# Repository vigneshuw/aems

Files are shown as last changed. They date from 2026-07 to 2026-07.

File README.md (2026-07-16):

# AEMS — Autonomous Energy Monitoring System

An open-source, low-cost, modular platform for high-resolution energy monitoring of manufacturing equipment. AEMS acquires three-phase voltage and current through a front end and a 24-bit, simultaneously sampling ADC, managed by a dual-core architecture that separates deterministic acquisition and on-board logging from host communication and control. A host, edge-gateway, and optional cloud software stack enable autonomous, long-duration acquisition independent of a continuously connected host, combining research-grade fidelity with industrial deployability for Industry 4.0 environments.

This repository accompanies the paper (preprint):

> **An Open-Source, Autonomous Platform for High-Resolution Energy Monitoring in Manufacturing**
> Vignesh Selvaraj, Aditya Nagaraj, Shengyuan Zhang, Sina Sadeghian, Sangkee Min

If you use this hardware, firmware, or software in your work, please see
[Citation](#citation) and [`CITATION.cff`](CITATION.cff).

---

## Why AEMS

Long-term, robust monitoring of machine energy consumption is difficult: commercial power
meters capable of capturing transient events are expensive, closed, and impractical to deploy
across an entire facility. AEMS was designed to make high-fidelity energy monitoring
**affordable, customizable, and reproducible**, so that small and medium-sized manufacturers
can instrument their equipment and improve data availability for Industry 4.0 analytics.

Design goals:

- **High-rate, simultaneous multi-channel acquisition** of voltage and current signals.
- **Autonomous operation** — capture and log on the board even when a host or network is unavailable, then stream or transfer data later.
- **Modular and open** — hardware, firmware, and host software are all open and independently reusable.
- **Deployable at scale** — many boards can share a network and be controlled from a single host or from an edge computer such as Raspberry Pi.

---

## System overview

AEMS is organized into three layers, each of which lives in this repository:

| Layer | Location | Role |
|---|---|---|
| **Hardware** | [`hardware/`](hardware/) | Custom AEMS v2 DAQ board — KiCad design, ADS131M08 analog front end, surge protection, impedance-controlled PCB. |
| **Firmware** | [`firmware/`](firmware/) | STM32H745 dual-core firmware. **CM4** owns deterministic acquisition + eMMC storage; **CM7** owns Ethernet/TCP + host command/control over OpenAMP. |
| **Host software** | [`firmware/BoardInterfaceLibrary/`](firmware/BoardInterfaceLibrary/) | Python `board_interface` library, examples, Raspberry Pi daemon (`aemsctl`), and an optional AWS IoT cloud agent. |

```
Machine mains ──▶ AEMS board (ADS131M08 front end)
                        │
                   STM32H745
              ┌─────────┴─────────┐
        CM4 (DAQ + eMMC)   CM7 (Ethernet/TCP)
                        │
                Host (PC / Raspberry Pi)
             board_interface  ·  aemsctl daemon
```

Data flows from the analog front end through the ADS131M08 acquisition path on CM4, is logged
to on-board eMMC and/or streamed over TCP to a host, and can optionally be forwarded to the
cloud for remote monitoring and transfer.

---

## Repository layout

```
aems/
├── hardware/                     KiCad project for the AEMS v2 board
│   ├── *.kicad_sch / *.kicad_pcb Schematics and PCB layout
│   ├── CustomLibs/               Project symbol/footprint libraries
│   ├── LTSpiceSimulation/        Analog front-end simulations (CT op-amp, etc.)
│   ├── DesignSummary/            Stackup, impedance control, interactive BOM (ibom.html)
│   ├── Manufacturing/            PCBWay fabrication outputs
│   └── FutureUpdates/            Planned revisions (e.g. front-end isolation)
│
└── firmware/                     STM32H745 dual-core firmware + host tooling
    ├── CM4/                      Cortex-M4: DAQ, ADS131M08, eMMC/FatFs, OpenAMP
    ├── CM7/                      Cortex-M7: Ethernet/TCP, FreeRTOS, OpenAMP master
    ├── Common/                   Shared cross-core headers/data structures
    ├── BoardInterfaceLibrary/    Python host library, CLI, Raspberry Pi daemon, cloud agent
    ├── docs/Software/            Firmware architecture documentation
    └── UnitTests/                Bench connectivity/test scripts
```

Detailed documentation already lives with each subtree:

- **Firmware architecture** — [`firmware/README.md`](firmware/README.md) and
  [`firmware/docs/Software/README.md`](firmware/docs/Software/README.md)
- **Host Python library** — [`firmware/BoardInterfaceLibrary/README.md`](firmware/BoardInterfaceLibrary/README.md)
- **Raspberry Pi server & cloud** —
  [`firmware/BoardInterfaceLibrary/docs/raspberry_pi_server.md`](firmware/BoardInterfaceLibrary/docs/raspberry_pi_server.md),
  [`firmware/BoardInterfaceLibrary/docs/cloud_autonomy.md`](firmware/BoardInterfaceLibrary/docs/cloud_autonomy.md)
- **Hardware** — [`hardware/README.md`](hardware/README.md)

---

## Hardware at a glance

The AEMS v2 board is built around:

- **ADS131M08** 8-channel, 24-bit simultaneous-sampling delta-sigma ADC as the analog front end.
- **STM32H745** dual-core (Cortex-M7 + Cortex-M4) microcontroller.
- **Isolated power rails** and impedance-controlled routing for Ethernet and USB.
- **MOV-based surge protection** on the measurement inputs.
- **On-board eMMC** storage for logging, plus Ethernet connectivity.

The current firmware and host workflows target a **6-channel acquisition mask (`0x3F`)** — three voltage and three current channels. See [`hardware/README.md`](hardware/README.md) for the board description, bill of materials, and manufacturing notes.

> **Note on voltage range:** the present hardware is validated for direct measurement at the
> board's rated input topology. Higher line-to-line service voltages (e.g. 480 V L-L) require updating the MOV-based surge protector or an external potential transformer, consistent with the modular design; see
> [`hardware/FutureUpdates/`](hardware/FutureUpdates/).

---

## Getting started

The fastest path depends on what you want to do.

**Bring up a board and capture data**

1. Read the system split in [`firmware/docs/Software/README.md`](firmware/docs/Software/README.md).
2. Build and flash the CM4/CM7 firmware from STM32CubeIDE ([`firmware/`](firmware/)).
3. Confirm connectivity with `firmware/UnitTests/tcptest.py` or the Python examples.
4. Use the [`board_interface`](firmware/BoardInterfaceLibrary/) library for repeatable host-side
   control, logging, and streaming.

**Reproduce or modify the hardware**

1. Open the KiCad project in [`hardware/`](hardware/).
2. Review the interactive BOM at `hardware/DesignSummary/ibom.html` and the stackup/impedance
   summaries.
3. Use the [`hardware/Manufacturing/`](hardware/Manufacturing/) outputs for fabrication.

**Deploy a permanent Raspberry Pi server**

See [`firmware/BoardInterfaceLibrary/docs/raspberry_pi_server.md`](firmware/BoardInterfaceLibrary/docs/raspberry_pi_server.md)
for the `aems-boardd` systemd daemon and `aemsctl` control command, and
[`cloud_autonomy.md`](firmware/BoardInterfaceLibrary/docs/cloud_autonomy.md) for optional AWS
IoT integration.

---

## Repository provenance

`hardware/` and `firmware/` are maintained as independent projects and integrated here via
`git subtree`. Each retains its own commit history and can be developed in isolation.

---

## Citation

If you use AEMS in academic work, please cite the paper and (optionally) the archived software
release. Machine-readable metadata is in [`CITATION.cff`](CITATION.cff).

```bibtex
@misc{selvaraj_aems_2026,
  title   = {An Open-Source, Autonomous Platform for High-Resolution Energy
             Monitoring in Manufacturing},
  author  = {Selvaraj, Vignesh and Nagaraj, Aditya and Zhang, Shengyuan and
             Sadeghian, Sina and Min, Sangkee},
  year    = {2026},
  note    = {Preprint. Department of Mechanical Engineering,
             University of Wisconsin-Madison}
  % arXiv id / journal / doi to be added
}
```

The software itself is archived on Zenodo. Please cite the concept DOI (resolves to the
latest release):

**DOI: [10.5281/zenodo.21383443](https://doi.org/10.5281/zenodo.21383443)**

```bibtex
@software{selvaraj_aems_software,
  author    = {Selvaraj, Vignesh and Nagaraj, Aditya and Zhang, Shengyuan and
               Sadeghian, Sina and Min, Sangkee},
  title     = {AEMS: Autonomous Energy Monitoring System},
  year      = {2026},
  publisher = {Zenodo},
  doi       = {10.5281/zenodo.21383443},
  url       = {https://github.com/vigneshuw/aems}
}
```

The version validated in the paper is v1.0.2 (DOI: [10.5281/zenodo.21383444](https://doi.org/10.5281/zenodo.21383444)).

---

## License

AEMS is released as open hardware and open-source software under a per-material split (full
texts in [`LICENSES/`](LICENSES/), following the [REUSE](https://reuse.software) convention):

| Material | License | Applies to |
|---|---|---|
| Hardware design files | [`CERN-OHL-P-2.0`](LICENSES/CERN-OHL-P-2.0.txt) | [`hardware/`](hardware/) — schematics, PCB, libraries, BOM, fabrication outputs |
| Firmware & host software | [`MIT`](LICENSES/MIT.txt) | original code in [`firmware/`](firmware/) and the Python `BoardInterfaceLibrary` |
| Documentation & figures | [`CC-BY-4.0`](LICENSES/CC-BY-4.0.txt) | READMEs, `docs/`, design summaries |

SPDX expression for the repository: `CERN-OHL-P-2.0 AND MIT AND CC-BY-4.0`. Vendor and
third-party components (ST HAL/CMSIS, FreeRTOS, OpenAMP, FatFs, BlueNRG-2, downloaded KiCad
libraries) retain their own licenses. See [`LICENSE`](LICENSE) for the full overview.

---

## Contact

**Vignesh Selvaraj** — `vselvaraj@wisc.edu`, `vignesh-selvaraj@outlook.com`

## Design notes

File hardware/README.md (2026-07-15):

# AEMS Hardware — Energy Monitoring System Board

KiCad design for the AEMS v2 data-acquisition board: a custom, multi-channel energy-monitoring
front end built around the **ADS131M08** ADC and the **STM32H745** dual-core MCU. This is the
hardware layer of the [Autonomous Energy Monitoring System](../README.md) and is designed to be
reproduced, modified, and manufactured by others.

The KiCad project root is `EnergyMonitoringSystem.kicad_pro`.

---

## Board overview

The board acquires multi-channel voltage and current signals at a high, simultaneous sampling
rate, digitizes them through the ADS131M08 analog front end, and hands the data to the STM32H745
for on-board logging and network streaming.

Key design features:

- **ADS131M08** — 8-channel, 24-bit, simultaneous-sampling delta-sigma ADC front end.
- **STM32H745** dual-core (Cortex-M7 + Cortex-M4) host MCU with eMMC and Ethernet.
- **Isolated power rails** feeding the analog front end and digital domains.
- **Impedance-controlled, multilayer PCB** (100 Ω differential / 50 Ω single-ended Ethernet,
  90 Ω USB) — see the impedance and stackup exports in [`DesignSummary/`](DesignSummary/).
- **MOV-based surge protection** on the measurement inputs.
- **Ethernet** and **on-board eMMC** for autonomous, network-independent logging.

The current firmware/host workflows use a **6-channel acquisition mask (`0x3F`)** — three voltage and three current channels.

> **Input voltage topology:** the present design is validated for its rated direct-measurement
> input topology. Measuring higher line-to-line service voltages (e.g. 480 V L-L) exceeds the
> on-board MOV continuous ratings and requires an updated **MOV surge protector (upto a certain voltage level)** or **external potential transformer**. This is
> consistent with the modular design intent and is tracked under
> [`FutureUpdates/`](FutureUpdates/).

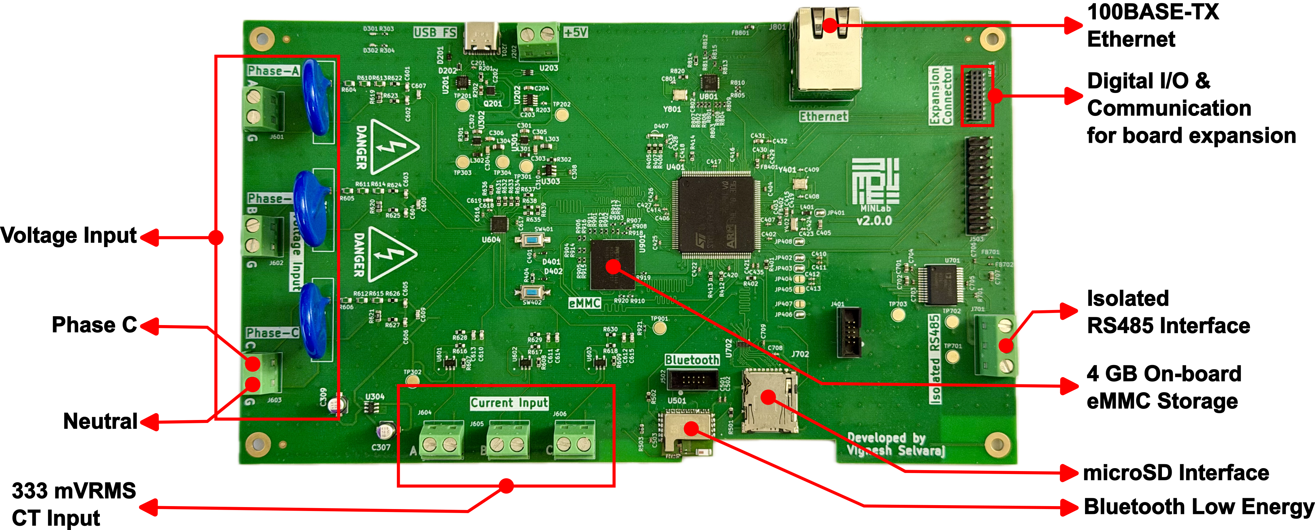
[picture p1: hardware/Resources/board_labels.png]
Overview of the AEMS hardware


---

## Board Power-Up

Temporarily, due to a design issue, the board needs to be powered on as shown in the figure below. This design issue will be fixed in the next hardware version. 

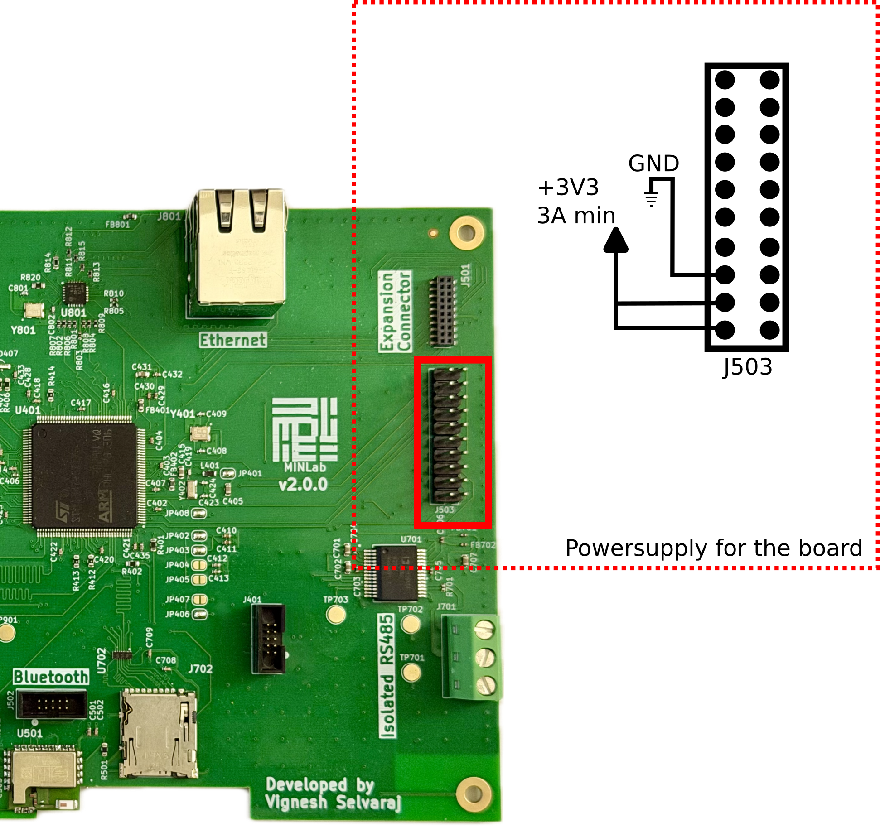
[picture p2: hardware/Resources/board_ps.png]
Board Power Supply


---

## Project structure

```
hardware/
├── EnergyMonitoringSystem.kicad_pro   KiCad project
├── EnergyMonitoringSystem.kicad_sch   Root schematic
├── EnergyMonitoringSystem.kicad_pcb   PCB layout
├── *.kicad_sch                        Hierarchical sheets (see below)
├── CustomLibs/                        Project symbol/footprint libraries
│   ├── EMS.kicad_sym                  Custom symbols
│   ├── EMS.pretty/                    Custom footprints
│   └── Downloaded/                    Third-party part libs (ADS131M08, MOV, op-amps, …)
├── LTSpiceSimulation/                 Analog front-end simulations (CT op-amp, rough studies)
├── Datasheets/                        Component reference material
├── ApplicationNotes/                  ST H7 hardware development notes
├── DesignSummary/                     Stackup, impedance control, interactive BOM
├── Manufacturing/PCBWay/              Fabrication + assembly outputs (Gerbers, drill, BOM, CPL)
└── FutureUpdates/Planned/             Planned revisions (front-end isolation, etc.)
```

### Schematic sheets

The design is hierarchical. The main functional sheets are:

| Sheet | Function |
|---|---|
| `adc` | ADS131M08 analog front end and signal conditioning |
| `uC` / `uCMain` | STM32H745 microcontroller and support |
| `ethernet` | Ethernet PHY (LAN8742) and magnetics |
| `poe` | Ethernet input (No PoE setup currently) |
| `vr` | Voltage regulation / power rails |
| `emmc` | eMMC storage |
| `sd_card` | SD card interface |
| `usb` | USB interface |
| `bm` | Bluetooth (BlueNRG) module |

---

## Bill of materials

- **Interactive BOM:** open [`DesignSummary/ibom.html`](DesignSummary/ibom.html) in a browser
  for a searchable, click-to-highlight BOM with board placement.
- **Fabrication BOM / placement:**
  [`Manufacturing/PCBWay/EnergyMonitoringSystem.kicad_pcb/PCBWay_bom.csv`](Manufacturing/PCBWay/EnergyMonitoringSystem.kicad_pcb/PCBWay_bom.csv)
  and `PCBWay_positions.csv` (component placement / CPL).

---

## Manufacturing

Ready-to-fabricate outputs (generated for PCBWay) are in
[`Manufacturing/PCBWay/`](Manufacturing/PCBWay/) or you generated your own from the KiCAD project:

- Gerbers (`F_Cu`, `B_Cu`, `In1..In6_Cu`, mask, paste, silkscreen, edge cuts)
- Drill files (`PTH`, `NPTH`)
- `PCBWay_bom.csv` (BOM) and `PCBWay_positions.csv` (pick-and-place)
- `PCBWay_netlist.ipc` (IPC-356 netlist)
- `DesignRequirements.pdf` and `Jump-SolderBridges.png` (assembly notes)

Stackup and impedance targets are documented in [`DesignSummary/`](DesignSummary/)
(`CurrentStackup.png`, `PCBWay Stackup.png`, and the `ImpedanceControl *.png` exports).

To regenerate outputs, open `EnergyMonitoringSystem.kicad_pcb` in KiCad and re-plot Gerbers/drill
and re-export the BOM/placement.

---

## Requirements

- **KiCad 7** or newer to open the project.
- Custom and downloaded libraries under [`CustomLibs/`](CustomLibs/) are referenced via the
  project-local `sym-lib-table` / `fp-lib-table`, so the project should open self-contained.

---

## Future updates

Planned hardware revisions are tracked in [`FutureUpdates/Planned/`](FutureUpdates/Planned/),
including improved analog front-end **isolation** and higher line-to-line voltages.

---

## License

Hardware licensing is being finalized as part of the open-hardware release; see the
[top-level LICENSE](../LICENSE). Please contact the authors before redistributing the design
files until the final license is committed.

For system context, firmware, and host software, see the [top-level README](../README.md).

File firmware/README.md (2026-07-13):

# AEMSv02-Firmware

Firmware and host-side tooling for the AEMS v2 board.

This repository contains:
- embedded firmware for the STM32H745 dual-core target
- CM4 DAQ, ADC, and eMMC ownership code
- CM7 Ethernet/TCP, OpenAMP, and host command handling code
- a Python board interface library for single-board and multi-board control
- software documentation for the firmware architecture

## What this repo is trying to do

At a high level, the board measures analog electrical signals, converts them through the ADS131M08 acquisition path, and then makes that data available in two main ways:

- log DAQ data to eMMC on the board
- stream DAQ or file data back to a host over TCP

The repository is structured around the hardware split of the STM32H745:

- `CM4` owns deterministic acquisition and storage work
- `CM7` owns network communication and command/control

That split is intentional. It keeps time-sensitive data capture close to the ADC/eMMC side, while the network-facing logic remains isolated on the Ethernet-enabled core.

## System overview

```mermaid
flowchart LR
    Host[Host PC / Raspberry Pi\nPython library or test tools]
    TCP[TCP server/client link]
    CM7[STM32H745 CM7\nEthernet + TCP + OpenAMP master]
    OA[OpenAMP / RPMsg]
    CM4[STM32H745 CM4\nDAQ engine + ADS131M08 + eMMC]
    ADC[ADS131M08 ADC]
    EMMC[eMMC / FatFs]

    Host <-->|commands, status, streams| TCP
    TCP <-->|network packets| CM7
    CM7 <-->|control + metadata| OA
    OA <-->|requests / replies| CM4
    ADC -->|sample frames| CM4
    CM4 -->|logged data| EMMC
    CM4 -->|stream/file data| OA
    OA --> CM7
    CM7 --> TCP
```

## High-level runtime model

### CM4 responsibilities

CM4 is the real-time acquisition and storage side.

It is responsible for:
- configuring and reading the ADS131M08
- running the DAQ state machine
- managing DAQ sample packing
- writing DAQ data to eMMC through FatFs
- exposing DAQ/file operations to CM7 through OpenAMP
- applying persisted channel offset calibration during DAQ startup

### CM7 responsibilities

CM7 is the communication and orchestration side.

It is responsible for:
- Ethernet and TCP handling
- receiving commands from the host
- translating host commands into OpenAMP operations
- returning status and acknowledgements over TCP
- serving file streams and DAQ streams back to the host

### Host responsibilities

The host side in this repo is the Python library in `BoardInterfaceLibrary`.

It is responsible for:
- acting as the TCP server that boards connect to
- handling single-board and multi-board sessions
- parsing board responses into stable dictionaries / dataclasses
- decoding DAQ stream and DAQ log binary formats
- converting raw ADC values into physical voltage/current values
- providing examples, CLI tooling, and simple GUIs

## Main workflows

### 1. Log DAQ data to eMMC

```mermaid
sequenceDiagram
    participant Host
    participant CM7
    participant CM4
    participant eMMC

    Host->>CM7: command 11 (start DAQ log)
    CM7->>CM4: OpenAMP DAQ start log
    CM4->>CM4: start ADC / DAQ state machine
    CM4->>eMMC: write packed DAQ blocks
    Host->>CM7: command 112 (stop and close)
    CM7->>CM4: OpenAMP DAQ stop/close
    CM4->>eMMC: flush + close file
    Host->>CM7: command 110 / 5
    CM7->>CM4: status / file size query
```

### 2. Stream DAQ data live

```mermaid
sequenceDiagram
    participant Host
    participant CM7
    participant CM4

    Host->>CM7: command 13 (start DAQ stream)
    CM7->>CM4: OpenAMP DAQ start stream
    CM4->>CM4: acquire samples
    CM4-->>CM7: stream blocks via shared memory / OpenAMP
    CM7-->>Host: TCP stream payload
    Host->>CM7: command 12 (stop)
    CM7->>CM4: OpenAMP DAQ stop
```

### 3. Read back a file from eMMC

```mermaid
sequenceDiagram
    participant Host
    participant CM7
    participant CM4
    participant eMMC

    Host->>CM7: command 8 (open/read stream)
    CM7->>CM4: OpenAMP file stream open/read
    CM4->>eMMC: read file chunks
    CM4-->>CM7: data blocks
    CM7-->>Host: TCP file stream
```

## Repository layout

Top-level directories:

- `CM4`
  - Cortex-M4 firmware project content
  - DAQ engine, ADS131M08 integration, eMMC/FatFs, OpenAMP remote service
- `CM7`
  - Cortex-M7 firmware project content
  - Ethernet/TCP handling, FreeRTOS tasks, OpenAMP master side
- `Common`
  - shared headers and cross-core data structures
- `BoardInterfaceLibrary`
  - Python package for controlling one or more boards from a host
- `UnitTests`
  - direct test scripts such as `tcptest.py`
- `docs`
  - software documentation for architecture and library internals
- `Drivers`
  - STM32 HAL and CMSIS driver code
- `Middlewares`
  - FatFs, OpenAMP, libmetal, and related middleware
- `datasheets`
  - hardware reference material used during firmware work

Key root files:

- `AEMSv02-Firmware.ioc`
  - STM32CubeMX project configuration
- `.project`, `.mxproject`, `.settings`
  - STM32CubeIDE project metadata

## Where to start, depending on what you are doing

### If you are working on embedded acquisition or storage

Start with:
- `CM4`
- `docs/Software/CM4/README.md`
- `docs/Software/CM4/Library/ads131m08.md`
- `docs/Software/CM4/Library/emmc_fs.md`

### If you are working on Ethernet, TCP, or host command flow

Start with:
- `CM7`
- `docs/Software/CM7/README.md`
- `docs/Software/CM7/Library/tcpclient.md`
- `docs/Software/CM7/Library/openamp_master.md`

Network identity is code-owned in `CM7/Core/Inc/aems_network_config.h`.
That header is the CubeMX-safe place to set the board static IP, server IP,
server port, and MAC derivation policy before flashing a board.

Current Ethernet policy:
- board IP is static and must be unique per board build
- MAC address is derived from the STM32 unique device ID using a locally administered prefix
- the board TCP client connects to the host/Raspberry Pi server at `192.168.0.20:10`
- TCP reconnects use rotating local source ports, per-board jitter, link-stability gating, TCP keepalive, and an app-level idle heartbeat
- command `99` reports the board IP, derived MAC, server IP/port, current local source port, connect-attempt count, and last connect/socket error

### If you are building host tools, automation, or multi-board workflows

Start with:
- `BoardInterfaceLibrary/README.md`
- `BoardInterfaceLibrary/examples/README.md`
- `BoardInterfaceLibrary/board_interface/session.py`
- `BoardInterfaceLibrary/board_interface/response_parser.py`

### If you need the overall firmware architecture first

Start with:
- `docs/Software/README.md`

## How people use this repo

There are usually three usage modes.

### Firmware development

Typical users:
- embedded developers working in STM32CubeIDE

They use this repo to:
- build and flash CM4/CM7 firmware
- modify DAQ behavior
- update command handling
- change hardware bring-up or storage behavior

### Board bring-up and bench validation

Typical users:
- firmware developers
- test engineers

They use:
- `UnitTests/tcptest.py`
- `BoardInterfaceLibrary/examples`

Common actions:
- verify heartbeat and OpenAMP connectivity
- start/stop DAQ logging
- stream files back from eMMC
- view live RMS values in a host GUI during DAQ streaming
- inspect DAQ status and throughput
- run offset calibration

## RGB LED Status Guide

The onboard RGB LED is driven by CM7 and gives a quick visual status of the board. The LED is useful when several boards are connected to a switch and the host is not yet running.

| LED | Board status | What to do |
|---|---|---|
| White solid | Booting | Firmware has started and initialization is in progress. |
| Blue slow blink | Ethernet / PHY init | LAN8742 PHY reset, Ethernet MAC/PHY bring-up, or no stable link yet. Check cable/switch if it stays here. |
| Blue solid | Ethernet link up, TCP not connected | Board has link but has not connected to the Python host server. Start the host server and check host IP/port. |
| Green solid | TCP connected / idle | Board is connected to the host and ready for commands. |
| Yellow blink | CM4 / OpenAMP not ready | CM7 is alive, but CM4/OpenAMP service is not healthy yet. Run command `99` for detail. |
| Red slow blink | eMMC error | Storage is unavailable or mount failed. Run command `99` and inspect eMMC mount diagnostics. |
| Purple slow blink | eMMC formatting | Blank eMMC was detected and filesystem creation is in progress. Wait for it to finish. |
| Cyan pulse | DAQ logging to eMMC | Command `11` DAQ capture is active and writing to eMMC. |
| Green fast blink | Live DAQ streaming | Command `13` live stream is active over TCP. |
| Cyan fast blink | File streaming | Command `8` file readback stream is active. |
| Yellow solid | Offset calibration | Command `98` offset calibration is running. |
| Orange blink | Recoverable warning | Nonfatal issue such as dropped samples, command failure, stream start failure, or retry condition. Query status. |
| Red solid | Fatal error | Firmware entered `Error_Handler()`. Reset/debug the board. |

Priority is error-first. For example, an eMMC error overrides the normal green connected state.

### Host-side application and automation development

Typical users:
- Python application developers
- lab automation developers
- Raspberry Pi / laptop control software developers

They use:
- `BoardInterfaceLibrary`

Common actions:
- control one or more boards simultaneously
- decode DAQ streams
- convert binary DAQ data to physical values
- build live monitoring tools on top of the Python session API
- build higher-level monitoring or acquisition applications

### Raspberry Pi permanent server deployment

Typical users:
- lab users who want a Pi to always listen for any plugged-in AEMS board
- automation systems that need shell-level control instead of foreground Python scripts

They use:
- `BoardInterfaceLibrary` installed with daemon support
- `aems-boardd` as a systemd service
- `aemsctl` as the shell control command
- optional `aems-cloud-agent` for AWS IoT Core command/shadow integration

Common actions:
- list active and historical boards
- start/stop DAQ streams on one board or all boards
- start/stop eMMC DAQ logs
- run local schedules for daily autonomous DAQ
- publish health/shadow JSON for cloud monitoring
- transfer capture bundles and manifests to local storage or S3
- query eMMC files and board status
- persist capture metadata under `/var/lib/aems-server`

Install on the Raspberry Pi from `BoardInterfaceLibrary`:

```bash
sudo bash ./deploy/install_raspberry_pi.sh
```

That installer creates the `aems` service user/group, installs the package into
`/opt/aems/venv`, installs `aems-boardd.service`, installs the optional
`aems-cloud-agent.service` unit file, and starts the board daemon. The cloud
agent is intentionally not enabled until AWS IoT credentials are configured.

For cloud support, install the optional dependencies into the same venv:

```bash
cd BoardInterfaceLibrary
sudo /opt/aems/venv/bin/pip install ".[cloud]"
```

Then configure `/etc/aems-server/cloud-agent.env`, place AWS IoT certificates
under `/etc/aems-server/certs`, and enable the cloud service:

```bash
sudo systemctl daemon-reload
sudo systemctl enable aems-cloud-agent
sudo systemctl start aems-cloud-agent
```

Use these checks after install:

```bash
aemsctl server status
aemsctl boards --active
sudo systemctl status aems-boardd --no-pager
sudo systemctl status aems-cloud-agent --no-pager
```

Cloud control uses JSON MQTT messages. `aems-cloud-agent` subscribes to
`aems/<thing-name>/commands/#`, forwards supported commands to the local daemon,
publishes responses to `aems/<thing-name>/responses`, and publishes health/shadow
state to `$aws/things/<thing-name>/shadow/update`. Example cloud command:

```json
{
  "command": "daq.stream.start",
  "params": {
    "board": "all",
    "file": "daq_cloud.bin",
    "format": "bin",
    "duration": 300,
    "sample_rate": 2000,
    "channel_mask": 63,
    "block_samples": 128
  }
}
```

## Current documentation entry points

- Firmware overview: `docs/Software/README.md`
- CM4 firmware docs: `docs/Software/CM4/README.md`
- CM7 firmware docs: `docs/Software/CM7/README.md`
- Python host library: `BoardInterfaceLibrary/README.md`
- Python examples: `BoardInterfaceLibrary/examples/README.md`
- Raspberry Pi server: `BoardInterfaceLibrary/docs/raspberry_pi_server.md`
- Raspberry Pi CLI: `BoardInterfaceLibrary/docs/aemsctl.md`
- Cloud/autonomous operation: `BoardInterfaceLibrary/docs/cloud_autonomy.md`

## Practical setup flow

For a new developer or user, the practical order is:

1. Understand the system split in `docs/Software/README.md`
2. Build/flash the firmware from STM32CubeIDE
3. Use `UnitTests/tcptest.py` or the Python examples to confirm board connectivity
4. Use `BoardInterfaceLibrary` for repeatable host-side control and streaming workflows

## Notes

- The current board/firmware assumptions in the Python tooling are built around a 6-channel mask of `0x3F` for the active acquisition workflows.
- CM4 is the authority for ADC capture, offset calibration, and eMMC writes.
- CM7 is the authority for TCP command handling and transport.

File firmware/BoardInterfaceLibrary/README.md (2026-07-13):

# Board Interface Library

This package provides a reusable Python interface for the AEMS board TCP protocol.

Primary APIs:
- `board_interface.BoardServer`
- `board_interface.BoardSession`
- `board_interface.StreamHandle`
- `board_interface.ResponseParser`
- `board_interface.convert_daq_bin_to_csv`

Examples are under `examples/`:
- `examples/commands_example.py`
- `examples/daq_log_example.py`
- `examples/stream_example.py`
- `examples/stream_on_command.py`
- `examples/stream_gui.py`
- `examples/multi_board_stream_example.py`
- `examples/multi_board_daq_log_example.py`
- `examples/README.md`

Raspberry Pi daemon/service docs:
- `docs/raspberry_pi_server.md`
- `docs/aemsctl.md`
- `docs/cloud_autonomy.md`

## Current capabilities

The library currently supports:
- single-board and multi-board TCP sessions keyed by board IP address
- DAQ logging control on the board eMMC
- remote file streaming and live DAQ streaming
- host-side parsing of ACKs/responses into stable dictionaries with `ResponseParser`
- command `99` parsing for network diagnostics, including board IP, derived MAC address, configured server IP/port, local TCP source port, connect-attempt count, and last connect/socket errors
- raw binary DAQ capture and offline conversion to parsed CSV
- live Tkinter-based RMS visualization for DAQ stream data through the example layer

For streamed or logged DAQ data, there are now two host-side output styles:
- raw `.bin`
  - preserves the exact raw bytes from the board
  - suitable for later post-processing
- parsed `.csv`
  - converts each DAQ frame into physical values
  - columns are `sample_index,ch0,ch1,ch2,ch3,ch4,ch5`
  - channels `0,1,2` are converted as voltage
  - channels `3,4,5` are converted as current

The same conversion path is exposed through:

```python
from board_interface import convert_daq_bin_to_csv
```

## DAQ binary layout: eMMC log vs live stream

The board does not emit the same binary layout for command `11` eMMC logging and command `13` live DAQ streaming. The library now handles these as two separate formats.

### Command 11: eMMC DAQ log file layout

The CM4 firmware packs only the selected channel values into the file written to eMMC.

For the current board build:
- channel mask is limited to `0x3F`
- that means channels `0..5` are logged
- each channel is written as one signed 32-bit little-endian integer
- there is no frame header, no response field, and no CRC in the file

So each logged sample in the `.bin` file is:
- `ch0` `int32_le`
- `ch1` `int32_le`
- `ch2` `int32_le`
- `ch3` `int32_le`
- `ch4` `int32_le`
- `ch5` `int32_le`

Total:
- `6 * 4 = 24` bytes per sample

This is the format used by:

```python
from board_interface import convert_daq_bin_to_csv
```

When `examples/stream_example.py` is used in file mode with:

```powershell
python .\examples\stream_example.py --mode file --file-output-format csv ...
```

the example now writes a metadata file next to the CSV that records:
- `decode_format: "command11_packed_log"`
- `sample_bytes: 24`
- `channel_mask: 0x3F`
- assumed channel order and channel types
- parsed command `8` stream summary

The multi-board file-stream example does the same thing per board, writing one metadata JSON file next to each converted CSV.

### Command 13: live DAQ stream layout

The live DAQ stream uses the full firmware frame layout:
- `response` as `uint16_le`
- `crc` as `uint16_le`
- `channel[0..7]` as eight signed 32-bit little-endian integers

Total:
- `36` bytes per stream frame

This is a different format from the eMMC log file. The library keeps these decode paths separate so command `11` files are not misinterpreted as command `13` stream frames.

## Installation Modes

### Normal laptop / desktop library install

Use this mode on Windows, macOS, Linux, or a Raspberry Pi when you want to write
your own Python scripts and directly import `board_interface`.

```powershell
pip install .
```

This installs:

- `board_interface` importable Python package
- `board-interface-cli` legacy interactive CLI
- `aemsctl`, `aems-boardd`, and `aems-cloud-agent` console entry points

Only `board_interface` and examples are normally used in this mode. The daemon
entry points are useful mainly on the Raspberry Pi permanent server.

### Raspberry Pi daemon install

Use this mode when the Pi should permanently listen on TCP port `10` and accept
any AEMS board that connects over Ethernet.

From the `BoardInterfaceLibrary` directory on the Pi:

```bash
sudo bash ./deploy/install_raspberry_pi.sh
```

The installer:

- creates the `aems` system user and group
- adds the invoking sudo user to group `aems` when possible
- creates `/etc/aems-server`
- creates `/etc/aems-server/certs`
- creates `/var/lib/aems-server/{captures,metadata,manifests,transfer_out}`
- installs this package into `/opt/aems/venv`
- installs `/etc/aems-server/config.toml`
- installs `aems-boardd.service`
- installs, but does not enable, `aems-cloud-agent.service`
- enables and restarts `aems-boardd`

Check daemon and CLI:

```bash
sudo systemctl status aems-boardd --no-pager
aemsctl server status
aemsctl boards --active
```

If `aemsctl` reports socket permission errors, log out and back in so the `aems`
group membership refreshes.

### Optional cloud dependencies

The base daemon does not require AWS packages. Install cloud extras only when
you need S3 transfer or AWS IoT Core integration:

Run this from the `BoardInterfaceLibrary` directory:

```bash
sudo /opt/aems/venv/bin/pip install ".[cloud]"
```

This installs:

- `boto3` for S3 upload jobs
- `awsiotsdk` for `aems-cloud-agent`

You can also install all extras into a local environment:

```bash
pip install ".[daemon,cloud]"
```

## Quick example

Stream a board file directly to raw binary:

```powershell
python .\examples\stream_example.py --mode file --file-output-format bin --board-ip 192.168.0.10 --remote-file daq0.bin --output captures\daq0.bin
```

Stream a board file and convert it directly to parsed CSV:

```powershell
python .\examples\stream_example.py --mode file --file-output-format csv --board-ip 192.168.0.10 --remote-file daq0.bin --output captures\daq0.csv
```

Stream live DAQ data to parsed CSV:

```powershell
python .\examples\stream_example.py --mode daq --daq-output-format csv --board-ip 192.168.0.10 --remote-file daq0.bin --duration 30 --output captures\daq0.csv
```

Open a live RMS GUI for the DAQ stream:

```powershell
python .\examples\stream_gui.py --mode daq --board-ip 192.168.0.10 --remote-file daq0.bin --sample-rate 2000 --channel-mask 0x3F --block-samples 128
```

Use `examples/README.md` for the full command reference and all example flows.

## Raspberry Pi permanent server

For a permanent Raspberry Pi server, install the daemon and use `aemsctl`.
The daemon owns TCP port `10`; boards connect to it automatically when they are
plugged into Ethernet.

Install on the Pi:

```bash
cd BoardInterfaceLibrary
sudo bash ./deploy/install_raspberry_pi.sh
```

Useful commands:

```bash
aemsctl server status
aemsctl boards --active
aemsctl board 192.168.0.10 openamp
aemsctl daq stream start --board all --file daq.bin --format bin --duration 30
aemsctl daq stream stop
```

The daemon stores board history and DAQ job metadata in SQLite under
`/var/lib/aems-server`. See `docs/raspberry_pi_server.md` and
`docs/aemsctl.md` for the full service and CLI reference.

Cloud/autonomous operation is documented in `docs/cloud_autonomy.md`. The daemon
now supports local schedules, health/shadow JSON, transfer manifests, local/S3
transfer jobs, and an optional AWS IoT bridge through `aems-cloud-agent`.

## Cloud Agent Summary

`aems-cloud-agent` is optional. It does not own board TCP connections; it talks
to the local daemon through `/run/aems-server/aems-boardd.sock`.

It does four things:

- subscribes to `aems/<thing-name>/commands/#`
- forwards supported cloud commands to `aems-boardd`
- publishes command responses to `aems/<thing-name>/responses`
- publishes the daemon shadow document to `$aws/things/<thing-name>/shadow/update`

Minimum cloud setup on the Pi:

```bash
sudo /opt/aems/venv/bin/pip install ".[cloud]"
sudo install -d -o aems -g aems -m 0750 /etc/aems-server/certs
sudo cp <device-cert.pem.crt> /etc/aems-server/certs/device.pem.crt
sudo cp <private-key.pem.key> /etc/aems-server/certs/private.pem.key
sudo cp <AmazonRootCA1.pem> /etc/aems-server/certs/AmazonRootCA1.pem
sudo chown -R aems:aems /etc/aems-server/certs
sudo chmod 0640 /etc/aems-server/certs/*
```

Create `/etc/aems-server/cloud-agent.env`:

```bash
AEMS_AWS_IOT_ENDPOINT=xxxxxxxxxxxxxx-ats.iot.us-east-1.amazonaws.com
AEMS_AWS_THING_NAME=aems-site-001-pi-001
AEMS_AWS_CERT=/etc/aems-server/certs/device.pem.crt
AEMS_AWS_KEY=/etc/aems-server/certs/private.pem.key
AEMS_AWS_CA=/etc/aems-server/certs/AmazonRootCA1.pem
AEMS_AWS_TOPIC_PREFIX=aems/aems-site-001-pi-001
```

Enable and inspect:

```bash
sudo systemctl daemon-reload
sudo systemctl enable aems-cloud-agent
sudo systemctl start aems-cloud-agent
sudo systemctl status aems-cloud-agent --no-pager
journalctl -u aems-cloud-agent -f
```

Cloud command payloads are JSON. Publish them to
`aems/<thing-name>/commands/<request-id>`:

```json
{
  "command": "daq.stream.start",
  "params": {
    "board": "all",
    "file": "daq_cloud.bin",
    "format": "bin",
    "duration": 300,
    "sample_rate": 2000,
    "channel_mask": 63,
    "block_samples": 128
  }
}
```

Useful cloud commands mirror the local daemon API:

- `health.get` / `health.shadow`
- `boards.list`, `jobs.list`, `transfers.list`
- `daq.stream.start` / `daq.stream.stop`
- `daq.log.start` / `daq.log.stop` / `daq.log.run`
- `transfer.start`
- `schedule.add` / `schedule.remove` / `schedule.enable`

Responses are published to `aems/<thing-name>/responses`. The device shadow is
published to `$aws/things/<thing-name>/shadow/update` every 30 seconds by
default. Use `docs/cloud_autonomy.md` for the full AWS setup and command
reference.

The AWS IoT policy must allow MQTT connect, subscribe/receive on the command
topic, publish on the response topic, and publish to the named shadow update
topic. S3 uploads require AWS credentials available to the `aems` user and
`s3:PutObject` permission on the configured bucket/prefix.

## Response parsing for end users

Use `board_interface.ResponseParser` to convert board responses and ACKs into stable dictionaries for application code.

Example:

```python
from board_interface import ResponseParser
parsed = ResponseParser.parse(response)
```

This parser is the intended place to update when board ACK/response formats change in the future.

## Current board limitation

The current board/firmware build is limited to a channel mask of `0x3F`.

That means:
- only channels 0 through 5 are currently supported by the examples and library workflows
- do not request a wider channel mask until the board firmware explicitly supports it

## TODO - Mandatory protocol fix

The current library contains a temporary host-side workaround to distinguish command `12` ACK traffic from command `13` DAQ stream payload on the same TCP connection.

This is not a reliable protocol boundary. It exists only as a temporary compatibility fix.

Mandatory long-term fix:
- update the firmware/protocol so DAQ stream traffic is explicitly framed or otherwise separated from control packets
- once that firmware change is made, the host library should remove the heuristic stream/control marker scan and parse packets deterministically

See `examples/README.md` for the detailed explanation and usage impact.

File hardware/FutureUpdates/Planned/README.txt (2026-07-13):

eMMC Memory
============

The plan is now to use the H7 chip that has a very high clock rate and can support the eMMC memory at a much higher clock rate (read and write speeds)

Advantages
----------

Something that we might potentially use for our case

1. Dual Core - Cortex M7 (~400MHz) and Cortex M4 (~200MHz)
	a. One for data collection / purely sampling the sensors (M0)
	b. One for external interface (Ethernet/Wi-Fi/RS 485)
2. Ethernet port is present
3. eMMC interface
4. USB present - Can be used as a mass storage as well
5. Pinouts for add on Wi-Fi board for scalability

1. PCB design notes for H7 Chip
	a. https://community.st.com/t5/stm32-mcus-products/stm32h7-with-emmc-and-usb-mass-storage-class-electronics/td-p/710280

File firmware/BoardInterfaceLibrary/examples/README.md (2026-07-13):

# Examples

This directory contains runnable examples for `BoardInterfaceLibrary`. The examples are intentionally small and direct, but they cover the main workflows you are likely to need:

- inspecting a board and exercising individual commands (Comment out items you don't need)
- starting a DAQ log to eMMC and stopping it cleanly
- streaming a file or DAQ data back to the host
- running simultaneous streams from multiple boards
- running simultaneous DAQ logs on multiple boards

The host machine runs these scripts as the TCP server. Boards connect into the host as TCP clients.

For a Raspberry Pi that should run continuously as the permanent board server,
use the daemon and CLI instead of these foreground examples:

- `../docs/raspberry_pi_server.md`
- `../docs/aemsctl.md`
- `../docs/cloud_autonomy.md`

## Response parsing for end users

Use `board_interface.ResponseParser` to convert board responses and ACKs into stable dictionaries for application code.

Example:

```python
from board_interface import ResponseParser
parsed = ResponseParser.parse(response)
```

This parser is the intended place to update when board ACK/response formats change in the future.

## Current board limitation

The current board/firmware build is limited to a channel mask of `0x3F`. All the binary to csv conversions implemented will only consider 6-channels, the codebase needs to be updated if going more than 6-channels.

That means:
- only channels 0 through 5 are currently supported by the examples and library workflows
- do not request a wider channel mask until the board firmware explicitly supports it

## TODO - Mandatory protocol fix

### Temporary workaround currently in use

The library now uses a temporary host-side heuristic, copied from the behavior proven in `UnitTests/tcptest.py`, to distinguish command `12` ACK traffic from command `13` DAQ stream payload on the same TCP socket.

What that means:
- while a DAQ stream is active, the host scans the incoming byte stream for something that looks like a fixed 128-byte control packet
- if it finds a plausible command `12` packet, it treats that region as control traffic instead of DAQ payload
- this is only a temporary compatibility fix so the example flow can stop a DAQ stream and continue collecting metrics

### Why this must be removed later

This is not a clean protocol boundary. It relies on packet-shape heuristics rather than explicit framing. That means it is workable for now, but it is not the correct long-term design.

### Required reliable fix - firmware/protocol update

A firmware update is required to make this reliable.

Mandatory fix:
- update the firmware/protocol so command `13` DAQ stream traffic is explicitly framed in chunks, or otherwise separated from fixed control/ACK packets
- after that, the host can parse command `12`, `10`, `110`, and other control packets deterministically during an active DAQ stream without any heuristic scanning

Recommended firmware-level solutions, in order of preference:
1. frame every DAQ stream chunk as a proper packet with command + length + payload
2. use a unified packet envelope for both stream and control messages
3. use separate logical or physical channels for stream data vs control traffic

Until that firmware update exists, the current heuristic should be treated as a temporary compatibility layer only.

## Directory contents

- `common.py`
  - shared helpers used by the single-board examples
- `commands_example.py`
  - runs the non-streaming commands against one board
- `daq_log_example.py`
  - starts DAQ logging on one board, waits, stops, then queries status and file size
- `stream_example.py`
  - streams either a remote file or a DAQ stream from one board
- `stream_on_command.py`
  - same core arguments as `stream_example.py`, but DAQ/file streaming starts when you press Enter
  - for DAQ mode, pressing Enter a second time sends command `12` to stop the stream
- `stream_gui.py`
  - starts a live DAQ stream and displays 0.25 second RMS values in a Tkinter GUI
  - shows channels 0 through 5 as Voltage-Ph1, Voltage-Ph2, Voltage-Ph3, Current-Ph1, Current-Ph2, Current-Ph3
- `multi_board_stream_example.py`
  - waits for multiple boards and starts simultaneous streams on all of them
- `multi_board_daq_log_example.py`
  - waits for multiple boards and starts simultaneous DAQ logs on all of them
- `boards.txt`
  - sample board IP file for the multi-board examples

## Requirements

- Python 3.10+
- the `board_interface` package available from this repo
- the host machine reachable by the boards over TCP
- boards configured to connect to the host on port `10` unless you override it

## General usage model

All examples follow the same pattern:

1. The script opens a TCP server on the host.
2. One or more boards connect to that server.
3. The script obtains a `BoardSession` for each board.
4. Commands are executed against each board session independently.

Single-board examples either:
- wait for the next board to connect, or
- wait for a specific board IP if `--board-ip` is given.

Multi-board examples:
- read a text file of IP addresses,
- wait for exactly those boards to connect,
- then start the requested operation on each board.

The default connection wait timeout used by the examples is 30 seconds unless you override `--timeout`.

## How to run the examples

Run from the `BoardInterfaceLibrary` directory:

```powershell
cd BoardInterfaceLibrary
```

### 1. Exercise the non-streaming commands

This example covers:
- heartbeat
- write config
- file counts
- file list
- file size
- DAQ status
- DAQ log status
- OpenAMP/network diagnostic heartbeat
- optional delete file
- delete all `.bin` / `.dat`

```powershell
python .\examples\commands_example.py
```

Target a specific board:

```powershell
python .\examples\commands_example.py --board-ip 192.168.0.10
```

Use a specific file for command 5:

```powershell
python .\examples\commands_example.py --board-ip 192.168.0.10 --read-file daq.bin
```

Run an explicit delete-file before the delete-all:

```powershell
python .\examples\commands_example.py --board-ip 192.168.0.10 --delete-file daq_old.bin
```

### 2. Run a DAQ log on one board

This example starts logging to eMMC, waits for the chosen duration, stops logging, then reads DAQ status and file size.

```powershell
python .\examples\daq_log_example.py --board-ip 192.168.0.10 --filename daq0.bin --duration 15
```

Common options:
- `--sample-rate`
- `--channel-mask`
- `--block-samples`

Example:

```powershell
python .\examples\daq_log_example.py --board-ip 192.168.0.10 --filename daq0.bin --duration 20 --sample-rate 6000 --channel-mask 0x3F --block-samples 128
```

### 3. Stream from one board

#### Interactive Enter-to-start / Enter-to-stop streaming

This example is intended for manual bench use.

- it accepts the same main stream arguments as `stream_example.py`
- it waits for Enter before starting the stream
- in `--mode daq`, it waits for Enter again before sending command `12`
- in `--mode file`, the second Enter concept does not apply because file streaming ends when the remote file transfer completes

DAQ stream with manual start/stop:

```powershell
python .\examples\stream_on_command.py --mode daq --daq-output-format csv --board-ip 192.168.0.10 --remote-file daq0.bin --output captures\daq0.csv
```

Raw file stream with manual start:

```powershell
python .\examples\stream_on_command.py --mode file --file-output-format bin --board-ip 192.168.0.10 --remote-file daq0.bin --output captures\daq0.bin
```

#### Live RMS GUI

This example starts a command `13` live DAQ stream and opens a Tkinter GUI. Incoming stream frames are decoded directly in memory; no `.csv` or `.bin` file is written.

The GUI displays RMS values over 0.25 second windows:

- `ch0` -> `Voltage-Ph1`
- `ch1` -> `Voltage-Ph2`
- `ch2` -> `Voltage-Ph3`
- `ch3` -> `Current-Ph1`
- `ch4` -> `Current-Ph2`
- `ch5` -> `Current-Ph3`

Stop the stream with the GUI's `Stop Stream` button.

```powershell
python .\examples\stream_gui.py --mode daq --board-ip 192.168.0.10 --remote-file daq0.bin --sample-rate 2000 --channel-mask 0x3F --block-samples 128
```

#### Stream a remote file to the host

For `--mode file`, there are now two output options:

- `--file-output-format bin`
  - writes the remote file exactly as raw bytes to a `.bin` file
- `--file-output-format csv`
  - treats the remote file as a command `11` eMMC DAQ log file
  - decodes it using the CM4 packed-log format, not the live stream format
  - columns are:
    - `sample_index`
    - `ch0`
    - `ch1`
    - `ch2`
    - `ch3`
    - `ch4`
    - `ch5`

Raw binary file read:

```powershell
python .\examples\stream_example.py --mode file --file-output-format bin --board-ip 192.168.0.10 --remote-file daq0.bin --output captures\daq0.bin
```

Convert streamed file directly to CSV:

```powershell
python .\examples\stream_example.py --mode file --file-output-format csv --board-ip 192.168.0.10 --remote-file daq0.bin --output captures\daq0.csv
```

For file-mode CSV output, the example also writes a metadata file next to the CSV, for example:
- `captures\daq0.csv.metadata.json`

That metadata records:
- `decode_format`
  - currently `command11_packed_log`
- `sample_bytes`
  - currently `24`
- `channel_mask`
  - currently `0x3F`
- `assumed_channel_order`
- `channel_types`
- `command_8_stream`
  - parsed file-stream summary from the library
- `frames_written`

If `--output` is omitted, the script writes to a default path that includes the board IP.

##### Important binary-layout detail for file mode

When command `11` logs DAQ data to eMMC, the CM4 firmware writes only the selected channel values into the file:

- current board limitation: channel mask is `0x3F`
- channels written: `ch0` through `ch5`
- storage type: signed 32-bit little-endian per channel
- no `response` field in the file
- no `crc` field in the file
- no per-sample header

So the current board writes:
- `24` bytes per logged sample
- sample layout:
  - `ch0 int32_le`
  - `ch1 int32_le`
  - `ch2 int32_le`
  - `ch3 int32_le`
  - `ch4 int32_le`
  - `ch5 int32_le`

This is why file-mode CSV conversion uses a different unpacker from live DAQ stream CSV conversion.

#### Stream live DAQ data to the host

For `--mode daq`, there are now two output options:

- `--daq-output-format csv`
  - writes a parsed CSV with converted physical values
  - decodes the command `13` live stream frame format
  - columns are:
    - `sample_index`
    - `ch0`
    - `ch1`
    - `ch2`
    - `ch3`
    - `ch4`
    - `ch5`
  - channel mapping is:
    - `ch0`, `ch1`, `ch2` -> converted voltage values
    - `ch3`, `ch4`, `ch5` -> converted current values
- `--daq-output-format bin`
  - writes the raw DAQ stream payload directly to a `.bin` file
  - this file contains only raw bytes; you can re-run the same conversion methods later if you want to post-process it offline

##### Important binary-layout detail for DAQ stream mode

Command `13` live streaming is not packed the same way as the eMMC log file.

The live DAQ stream uses the full firmware sample frame:
- `response uint16_le`
- `crc uint16_le`
- `channel[0..7]` as eight signed 32-bit little-endian integers

Total:
- `36` bytes per stream frame

So:
- command `11` file log decode path != command `13` live stream decode path
- the library now keeps those two formats separate on purpose

The example starts command 13 asynchronously, waits for `--duration`, sends command 12 with `stop_daq()`, waits for stream completion, then sends command 10 and saves metadata next to the output file.

The default DAQ stream duration is 30 seconds.

```powershell
python .\examples\stream_example.py --mode daq --daq-output-format csv --board-ip 192.168.0.10 --remote-file daq0.bin --duration 30 --output captures\daq0.csv
```

The example also writes a metadata file next to the CSV, for example:
- `captures\daq0.csv.metadata.json`

To dump the raw DAQ stream payload as a binary file instead:

```powershell
python .\examples\stream_example.py --mode daq --daq-output-format bin --board-ip 192.168.0.10 --remote-file daq0.bin --duration 30 --output captures\daq0.bin
```

That metadata file contains:
- `board_ip`
- `remote_file`
- `output_file`
- `duration_seconds`
- `command_13_ack`
  - fixed command 13 ACK if present, otherwise `null`
- `command_12_ack`
  - parsed stop ACK fields from command 12
  - includes `channel_mask_hex`
- `command_10_status`
  - parsed DAQ status returned by command 10 after the stream stops
  - includes `bytes_written_mib`
- `command_13_stream`
  - host-side DAQ stream summary
  - includes:
    - `bytes_received`
    - `bytes_received_mib`
    - `frames_received`
    - `elapsed_seconds`
    - `avg_frames_per_sec`
    - `avg_mib_per_sec`
    - `csv_path`

This metadata structure is intended to mirror the style of output you inspect in `tcptest.py` for commands 12, 13, and 10, but in machine-readable JSON form.

With DAQ stream settings:

```powershell
python .\examples\stream_example.py --mode daq --daq-output-format csv --board-ip 192.168.0.10 --remote-file daq0.bin --duration 15 --sample-rate 2000 --channel-mask 0x3F --block-samples 128
```

### 4. Stream from multiple boards simultaneously (Needs Testing)

Create an IP file such as `boards.txt`:

```text
192.168.0.10
192.168.0.11
192.168.0.12
```

A sample file is already included at:
- `examples/boards.txt`

#### Multi-board DAQ stream to CSV

```powershell
python .\examples\multi_board_stream_example.py --ip-file .\examples\boards.txt --mode daq --daq-output-format csv --remote-file daq.bin --output-dir captures
```

Each board writes to its own file, for example:
- `captures\192.168.0.10_daq.csv`
- `captures\192.168.0.11_daq.csv`

#### Multi-board DAQ stream to raw binary files

```powershell
python .\examples\multi_board_stream_example.py --ip-file .\examples\boards.txt --mode daq --daq-output-format bin --remote-file daq.bin --output-dir captures
```

Each board writes to its own file, for example:
- `captures\192.168.0.10_daq.bin`
- `captures\192.168.0.11_daq.bin`

#### Multi-board file stream to binary files

```powershell
python .\examples\multi_board_stream_example.py --ip-file .\examples\boards.txt --mode file --file-output-format bin --remote-file daq.bin --output-dir captures
```

Each board writes to its own file, for example:
- `captures\192.168.0.10_daq.bin`
- `captures\192.168.0.11_daq.bin`

#### Multi-board file stream converted to CSV

```powershell
python .\examples\multi_board_stream_example.py --ip-file .\examples\boards.txt --mode file --file-output-format csv --remote-file daq.bin --output-dir captures
```

Each board writes to its own converted CSV, for example:
- `captures\192.168.0.10_daq.csv`
- `captures\192.168.0.11_daq.csv`

For file-mode CSV conversion, each board also gets its own metadata file, for example:
- `captures\192.168.0.10_daq.csv.metadata.json`
- `captures\192.168.0.11_daq.csv.metadata.json`

These metadata files contain the same decode details as the single-board file-mode CSV example:
- `decode_format`
- `sample_bytes`
- `channel_mask`
- `assumed_channel_order`
- `channel_types`
- `command_8_stream`
- `frames_written`

### 5. Run DAQ logs on multiple boards simultaneously

This example starts logging on all listed boards first, waits for the requested duration, then stops each board and queries status and file size.

```powershell
python .\examples\multi_board_daq_log_example.py --ip-file .\examples\boards.txt --filename-prefix daq --duration 15
```

Generated remote filenames are unique per board, for example:
- `daq_192_168_0_10.bin`
- `daq_192_168_0_11.bin`

With a higher sample rate:

```powershell
python .\examples\multi_board_daq_log_example.py --ip-file .\examples\boards.txt --filename-prefix runA --duration 20 --sample-rate 6000 --channel-mask 0x3F --block-samples 128
```

## Command mapping reference

These examples exercise the current command set in the library:

- `0` - heartbeat
- `1` - write config
- `2` - `.dat` file count
- `3` - all file count
- `4` - file list with size
- `5` - file size for a specific filename
- `6` - delete all `.bin` / `.dat`
- `7` - delete a specific file
- `8` - file stream
- `9` - test stream
- `10` - DAQ status
- `11` - start DAQ log
- `12` - stop DAQ
- `13` - DAQ stream
- `97` - get current CM4 ADC offset calibration values
- `98` - run CM4 ADC offset calibration, save the offsets persistently, and return the new values
- `99` - OpenAMP heartbeat with eMMC, board IP/MAC, server, and TCP reconnect diagnostics
- `110` - DAQ log status
- `112` - stop/close DAQ log

## Notes on outputs

### Host-side outputs

For stream examples, host-side output names are board-scoped so simultaneous runs do not collide.

Examples:
- `captures\192.168.0.10_daq.csv`
- `captures\192.168.0.11_daq.csv`
- `captures\192.168.0.10_daq.bin`

### Board-side filenames

For DAQ logging examples, the filename refers to the file created on the board eMMC.

Single-board example:
- `--filename daq0.bin`

Multi-board example:
- generated from `--filename-prefix` and board IP so each board gets a unique remote file name

## Practical workflow

A typical workflow is:

1. Use `commands_example.py` to confirm the board is connected and responsive.
2. Use `daq_log_example.py` to create a DAQ file on the board.
3. Use `stream_example.py` with `--mode file` or `--mode daq` to pull data back to the host.
4. Use the multi-board examples once the single-board path is confirmed.

## Troubleshooting

### A script waits forever for a board

Check:
- the board is configured to connect to the host IP and port
- the host firewall allows inbound TCP on the selected port
- the IP in `--board-ip` or `boards.txt` matches the board client IP

### A board connects but the wrong board is used

For single-board examples, provide `--board-ip` explicitly.

For multi-board examples, only the IPs listed in the IP file are accepted as targets.

### Output files are empty or incomplete

Check:
- the remote filename exists on the board
- command 11 actually created the DAQ file before command 8/13 is used
- DAQ log stop/close completed successfully before streaming the file

### Multiple boards are expected but only some connect

The multi-board examples wait for every IP in the IP file. Remove unavailable boards from the file or bring them online before starting the script.

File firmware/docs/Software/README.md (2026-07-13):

# AEMS Firmware Software Documentation

## Purpose

This firmware runs the Adaptive Energy Monitoring System (AEMS) board built around an STM32H745 dual-core MCU. The board acquires multi-channel electrical measurements through an ADS131M08 ADC, stores captured data to eMMC, and exchanges commands and data with a host computer over Ethernet/TCP.

The design deliberately splits responsibility across both cores:

- **CM4** owns deterministic acquisition, buffering, and eMMC file operations.
- **CM7** owns networking, TCP command handling, host-facing streaming, and supervisory control.

That split is the core architectural decision in this codebase. The firmware is trying to achieve three things at the same time:

1. **capture data deterministically** from the analog front end
2. **persist data safely** to eMMC in a format that can be streamed or decoded later
3. **expose the board as a remotely controlled instrument** through a simple TCP protocol

## Current firmware status

The current codebase implements the following board-level capabilities:

- CM7 TCP client connection to a host Python server
- CM7 CubeMX-safe static network config in `CM7/Core/Inc/aems_network_config.h`
- CM7 UID-derived locally administered MAC address
- CM7 TCP reconnect hardening: PHY reset/retry, link-stability gating, rotating local source ports, reconnect jitter, TCP keepalive, and app-level idle heartbeat
- CM7 command parser and response framing
- CM7 file and DAQ streaming over TCP
- CM4 OpenAMP remote service for filesystem and DAQ control
- CM4 ADS131M08 acquisition pipeline using SPI + DMA + cooperative superloop
- CM4 eMMC filesystem wrapper using FatFs on SDMMC1/MMC
- CM4 eMMC first-mount/format recovery with command `99` diagnostics
- CM4 SDMMC1 ClockDiv boot policy: slower ClockDiv during mount/format, runtime ClockDiv after success
- DAQ logging to eMMC files
- DAQ live streaming from CM4 to CM7 via shared memory
- file count, file list, file size, file delete, and file stream operations
- persistent ADC offset calibration commands `97` / `98`

Known current constraints:

- the host tooling and most workflows currently assume **channel mask `0x3F`**
- command `11` eMMC DAQ log files and command `13` live DAQ streams use **different binary layouts**
- CM7/host-side DAQ stop during command `13` still relies on a temporary protocol heuristic and should be cleaned up by a future firmware framing update
- command `99` is the primary bring-up diagnostic; it now includes raw FatFs mount/format results plus board IP/MAC/server/TCP reconnect diagnostics

## Hardware and software interplay

The firmware is tightly coupled to the board hardware. The main hardware/software boundaries are:

| Hardware block | Firmware owner | Notes |
|---|---|---|
| ADS131M08 ADC | CM4 | Sample clocking, SPI4 DMA reads, DRDY interrupt handling, per-sample packing |
| eMMC on SDMMC1 | CM4 | FatFs mount/format, ClockDiv policy, file I/O, DAQ raw log writes |
| Ethernet PHY / LwIP | CM7 | Host connectivity, TCP link, command transport |
| Shared SRAM region | CM4 + CM7 | File and DAQ streaming handoff between cores |
| OpenAMP / RPMsg | CM4 + CM7 | Control plane between the two cores |
| HSEM boot synchronization | CM4 + CM7 | Dual-core startup coordination |
| RGB LED | CM7 | Basic board-visible status indication |

### System data flow

```plantuml
@startuml
skinparam monochrome true
skinparam shadowing false
actor Host
rectangle CM7 {
  component "TCP client +\ncommand controller" as TCP
  component "OpenAMP master" as OA7
}
rectangle CM4 {
  component "OpenAMP remote" as OA4
  component "DAQ engine" as DAQ
  component "eMMC / FatFs" as FS
}
component "ADS131M08" as ADC
component "Shared SRAM" as SHM

Host --> TCP : TCP commands / stream sink
TCP --> OA7 : translate host requests
OA7 --> OA4 : RPMsg command
OA4 --> DAQ : start/stop/status
OA4 --> FS : list/read/write/delete
ADC --> DAQ : DRDY + SPI DMA samples
DAQ --> FS : raw DAQ log writes
FS --> OA4 : file chunks
DAQ --> SHM : DAQ stream blocks
FS --> SHM : file stream blocks
SHM --> TCP : zero-copy / pointer-style send
TCP --> Host : fixed responses + streamed bytes
@enduml
```

## Dual-core role split

### CM4 summary

CM4 is the real-time data plane. It:

- initializes and mounts eMMC
- configures and services the ADS131M08
- runs the DAQ state machine
- aggregates acquired samples into write blocks
- writes DAQ data to eMMC
- provides filesystem and DAQ services to CM7 through OpenAMP

See: [CM4 documentation](CM4/README.md)

### CM7 summary

CM7 is the supervisory and transport plane. It:

- boots FreeRTOS and LwIP
- opens a TCP connection to the host
- receives host commands and maps them to board actions
- calls CM4 OpenAMP services
- streams file and DAQ data over TCP
- frames host-visible responses

See: [CM7 documentation](CM7/README.md)

## Source tree orientation

| Area | Purpose |
|---|---|
| `CM4/Core/Src` | CM4 boot, superloop, OpenAMP remote endpoint |
| `CM4/Library/ads131m08` | ADC driver, DAQ engine, DAQ state machine |
| `CM4/Library/emmc_fs` | FatFs wrapper and raw DAQ log file API |
| `CM7/Core/Src` | CM7 boot, FreeRTOS tasks, OpenAMP master |
| `CM7/Library/eth` | TCP client used by the host-facing command path |
| `CM7/Library/led` | RGB LED helper |
| `Common/Inc` | shared DAQ structures, HSEM IDs, shared-memory definitions |
| `BoardInterfaceLibrary` | Python host library, examples, Raspberry Pi daemon, and CLI |

## Documentation map

### Core-level documents

- [CM4 / Overview](CM4/README.md)
- [CM7 / Overview](CM7/README.md)

### Library-level documents

#### CM4
- [CM4 Library Index](CM4/Library/README.md)
- [CM4 ads131m08 and DAQ engine](CM4/Library/ads131m08.md)
- [CM4 eMMC filesystem wrapper](CM4/Library/emmc_fs.md)
- [CM4 OpenAMP remote service](CM4/Library/openamp_remote.md)

#### CM7
- [CM7 Library Index](CM7/Library/README.md)
- [CM7 TCP client library](CM7/Library/tcpclient.md)
- [CM7 LED helper library](CM7/Library/led.md)
- [CM7 OpenAMP master service](CM7/Library/openamp_master.md)

#### Host / Raspberry Pi
- [Python host library](../../BoardInterfaceLibrary/README.md)
- [Raspberry Pi board server](../../BoardInterfaceLibrary/docs/raspberry_pi_server.md)
- [aemsctl CLI](../../BoardInterfaceLibrary/docs/aemsctl.md)
- [Cloud/autonomous operation](../../BoardInterfaceLibrary/docs/cloud_autonomy.md)

## Boot and runtime overview

### Boot sequence

1. CM7 powers up first, configures clocks/cache/MPU, and releases CM4 through HSEM.
2. CM4 wakes, initializes SPI4, SDMMC1, DAQ context, sets SDMMC1 to mount ClockDiv `10`, and mounts/formats the eMMC filesystem.
3. CM4 brings up the OpenAMP remote endpoint.
4. CM7 starts FreeRTOS, LwIP, TCP client, and OpenAMP master.
5. The board is then ready to accept host commands.

After a successful eMMC mount or first-boot format, CM4 switches SDMMC1 back to runtime ClockDiv `8` and then loads persisted DAQ offset calibration from `ocal.cfg` when present.

### Command path overview

```plantuml
@startuml
skinparam monochrome true
skinparam shadowing false
actor Host
participant "CM7 TcpClient" as TCP
participant "CM7 ControllerTask" as CTRL
participant "CM7 OpenAmpFs" as OA7
participant "CM4 OpenAmpFs" as OA4
participant "CM4 DAQ / FS" as CM4

Host -> TCP : TCP payload
TCP -> CTRL : enqueue decoded command
CTRL -> OA7 : service request
OA7 -> OA4 : RPMsg request
OA4 -> CM4 : DAQ or filesystem operation
CM4 --> OA4 : result / data metadata
OA4 --> OA7 : RPMsg reply
CTRL -> TCP : fixed reply or start stream
TCP --> Host : response bytes
@enduml
```

## Data formats that matter

Two binary DAQ formats exist today:

### 1. eMMC log file format from command `11`

- selected channels only
- current host physical-value tooling assumes channels `0..5` (`channel_mask = 0x3F`)
- firmware can validate an 8-bit channel mask, but widening the mask changes the file stride and host decoder assumptions
- each channel stored as signed 32-bit little-endian
- **24 bytes per sample** for current board assumptions

### 2. live DAQ stream format from command `13`

- `response` (`uint16_le`)
- `crc` (`uint16_le`)
- `channel[0..7]` as eight signed 32-bit little-endian values
- **36 bytes per frame**

This distinction is important in both firmware and host tooling.

## Bring-up diagnostics

Command `99` returns the health snapshot used during board bring-up and eMMC troubleshooting.

Important storage fields:

| Field | Meaning |
|---|---|
| `remote_mount_status` | CM4 public `EmmcFs_MountOrFormat()` result; `0` means storage is usable |
| `emmc_mount_stage` | last mount lifecycle stage: link, first mount, mkfs, or post-format mount |
| `emmc_mount_fresult` | FatFs result from the first `f_mount()` |
| `emmc_mkfs_fresult` | FatFs result from `f_mkfs()` |
| `emmc_post_mount_fresult` | FatFs result from the mount after formatting |

A blank eMMC can validly report `remote_mount_status=0`, `emmc_mount_fresult=13`, `emmc_mkfs_fresult=0`, and `emmc_post_mount_fresult=0`. That means the first mount found no filesystem, firmware created one, and the post-format mount succeeded.

## RGB LED Board Status

CM7 owns the onboard RGB LED and updates it from `TelemetryTask`. The LED service is non-blocking: the telemetry task selects a board status and calls `LED_Service(&rgbLed)` every 25 ms. Blink and pulse effects are generated from `HAL_GetTick()` and do not block TCP, OpenAMP, or DAQ work.

The LED is intended as the first field diagnostic. An end user should be able to look at the board and know whether the issue is network, host connection, CM4/OpenAMP, eMMC, active acquisition, or a fatal fault.

### Status Colors

| Priority | LED | Meaning | Typical trigger |
|---:|---|---|---|
| 1 | Red solid | Fatal firmware error | `Error_Handler()` |
| 2 | Red slow blink | eMMC/storage error | CM4 mount status is nonzero after command `99` diagnostics are available |
| 3 | Yellow blink | CM4/OpenAMP not ready | OpenAMP init failed or latest heartbeat/probe showed CM4 service not healthy |
| 4 | Yellow solid | Offset calibration active | command `98` is running |
| 5 | Purple slow blink | eMMC formatting | blank eMMC was detected and filesystem creation is in progress |
| 6 | Cyan pulse | DAQ logging to eMMC | command `11` succeeded and logging is active |
| 7 | Green fast blink | Live DAQ streaming | command `13` stream is active |
| 8 | Cyan fast blink | File stream active | command `8` stream is active |
| 9 | Orange blink | Recoverable warning | command/stream failure, dropped samples reported by command `10`/`110`, or retry condition |
| 10 | Green solid | TCP connected and idle | board is connected to host and no higher-priority activity/error is active |
| 11 | Blue solid | Ethernet link up, TCP not connected | PHY/link is up but Python host server is not connected |
| 12 | Blue slow blink | Ethernet/PHY initialization or no link | PHY reset/link bring-up, cable/switch missing, or link not stable |
| 13 | White solid | Booting | LED initialized before runtime status is known |

### How to Interpret the LED

- **White solid** should be brief. If it stays white, CM7 likely did not reach the FreeRTOS telemetry loop.
- **Blue slow blink** points at physical Ethernet: cable, switch, PHY reset/init, or link negotiation.
- **Blue solid** means Ethernet is good but the host TCP server is not connected. Start the Python tool and verify the configured host IP is reachable.
- **Green solid** is the normal idle state after the board connects to the host.
- **Yellow blink** means CM7 is alive but cannot confirm CM4/OpenAMP health. Use command `99`.
- **Red slow blink** means eMMC is not usable. Use command `99` and check `remote_mount_status`, `emmc_mount_stage`, and FatFs `FRESULT` fields.
- **Purple slow blink** means the eMMC filesystem creation path is active. This can happen on a new blank eMMC.
- **Cyan pulse / green fast blink / cyan fast blink** identify active data movement: eMMC DAQ logging, live DAQ streaming, or file streaming.
- **Orange blink** is intentionally nonfatal. It tells the user to query command `10`, `110`, or `99` for detail.
- **Red solid** means fatal firmware error and requires reset/debug.

See also: [CM7 LED helper library](CM7/Library/led.md)

## Recommended reading order

1. read this page first
2. read [CM4 / Overview](CM4/README.md)
3. read [CM7 / Overview](CM7/README.md)
4. use the library pages for function-level interface details

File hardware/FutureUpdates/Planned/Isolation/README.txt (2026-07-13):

Safety
------

- Creating isolation to protect other devices connected to the board

DC-DC-Isolation
----------------

- Isolating the power supply to ADC from the USB Input
- https://www.analog.com/en/products/adum5000.html#part-details
- Videos -> https://www.youtube.com/watch?v=OM6CCaYSZ9A

SPI Isolation
--------------

- Isolating the SPI connection between the ADC and MCU
- Potentially we can remove the 1V2 REF IN to the ADC, as the ADC has its own reference voltage generator. But need to think about the Op-Amp used for the current input.
- https://www.analog.com/en/products/adum3151.html#part-details

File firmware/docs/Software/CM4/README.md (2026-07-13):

# CM4 Firmware

## Role

CM4 is the deterministic acquisition and storage core.

It runs without an RTOS and executes a cooperative superloop. It owns the peripherals that are most timing-sensitive or storage-sensitive:

- ADS131M08 acquisition path
- SPI4 DMA servicing for ADC reads
- SDMMC1 / eMMC access
- FatFs-backed file operations
- OpenAMP remote command handling for file and DAQ services

The key design rule is simple: **CM4 owns the data plane**.

## Runtime responsibilities

CM4 is responsible for:

- booting after CM7 releases it through HSEM
- initializing the ADC-facing SPI and the eMMC interface
- mounting the filesystem
- creating the filesystem on first boot when eMMC is blank
- recording eMMC mount/format diagnostics for command `99`
- creating the OpenAMP RPMsg service used by CM7
- running the DAQ state machine
- packaging and writing raw samples into eMMC log files
- exposing file operations and DAQ operations to CM7

## Main execution model

CM4 main loop in `CM4/Core/Src/main.c` is effectively:

```c
while (1)
{
    DAQ_StateMachine_Run();
    OpenAmpFs_RemotePoll();
}
```

That is the whole model:

- DAQ work is progressed cooperatively
- OpenAMP messages are polled cooperatively
- interrupt handlers only signal events and complete DMA-related handoffs

## Core startup

### File of interest
- `CM4/Core/Src/main.c`

### Sequence

1. wait for CM7 boot synchronization using HSEM
2. initialize HAL and CM4-owned peripherals
3. probe the ADC device ID using the master clock
4. initialize DAQ context and DAQ engine
5. set SDMMC1 to mount ClockDiv `10`
6. initialize and mount-or-format eMMC filesystem through `EmmcFs_*`
7. snapshot mount diagnostics for command `99`
8. if mount succeeded, switch SDMMC1 to runtime ClockDiv `8`
9. load persisted ADC offset calibration from `ocal.cfg` when present
10. initialize OpenAMP remote endpoint through `OpenAmpFs_RemoteInit()`
11. enter the superloop

## Interrupts and callback ownership

CM4 uses interrupts as signal sources, not as heavy processing contexts.

### Important callbacks in `main.c`

| Callback | Purpose |
|---|---|
| `HAL_GPIO_EXTI_Callback()` | detects ADS DRDY edge and signals DAQ |
| `HAL_SPI_TxRxCpltCallback()` | completes ADC DMA sample transfer and signals DAQ |
| `HAL_SPI_ErrorCallback()` | reports ADC DMA error to DAQ |

## DAQ state machine

### Files of interest
- `CM4/Library/ads131m08/statemachine.c`
- `CM4/Library/ads131m08/statemachine.h`
- `CM4/Library/ads131m08/daq_engine.c`
- `CM4/Library/ads131m08/daq_engine.h`

### States

| State | Meaning |
|---|---|
| `DAQ_STATE_IDLE` | no active run |
| `DAQ_STATE_PREPARING` | hardware/config bring-up before acquisition |
| `DAQ_STATE_ACQUIRING` | normal sampling, buffering, and output servicing |
| `DAQ_STATE_STOPPING` | stop requested, shutdown in progress |
| `DAQ_STATE_FINALIZING` | flush pending blocks before returning idle |
| `DAQ_STATE_ERROR` | latched error state until stop/reset |

### PlantUML state view

```plantuml
@startuml
skinparam monochrome true
skinparam shadowing false
[*] --> Idle
Idle --> Preparing : CMD_START
Preparing --> Acquiring : ADC armed
Preparing --> Error : arm failure
Acquiring --> Stopping : CMD_STOP
Stopping --> Finalizing : shutdown complete
Finalizing --> Idle : no pending writes
Error --> Idle : CMD_STOP + shutdown
@enduml
```

### How acquisition progresses

During `DAQ_STATE_ACQUIRING`, CM4 repeatedly does three things:

1. `DAQ_ServiceAdcPending()`
2. `DAQ_ServiceCapturedSamples()`
3. `DAQ_ServicePendingWrites()`

This is the key acquisition pipeline.

## DAQ data path

```plantuml
@startuml
skinparam monochrome true
skinparam shadowing false
start
:DRDY interrupt;
:increment adc_ready_pending;
:superloop services pending ADC events;
:start SPI DMA read of ADS131M08 frame;
:DMA completion callback fires;
:raw ADC frame taken from ADS driver queue;
:build DaqSampleFrame_t;
:append sample to aggregation block;
if (block full?) then (yes)
  :queue block for output;
endif
if (DAQ mode == log) then (log)
  :pack selected channels;
  :write raw bytes to eMMC;
else (stream)
  :copy full frames to shared memory;
endif
stop
@enduml
```

## DAQ modes

CM4 supports two distinct output modes through `DaqMode_t`:

| Mode | Purpose |
|---|---|
| `DAQ_MODE_LOG_TO_EMMC` | write packed raw channel data into an eMMC log file |
| `DAQ_MODE_STREAM_TO_SHMEM` | expose full DAQ frames through shared memory for CM7 TCP streaming |

This distinction is important because the binary layout differs.

### Command 11 log layout

For current board/host assumptions:

- workflows currently use `channel_mask = 0x3F`
- the firmware validates an 8-bit mask, but host physical-value conversion and CSV examples are defined for channels `0..5`
- channels `0..5` are packed
- each channel is written as signed 32-bit little-endian
- no response field or CRC field is written
- total = **24 bytes/sample**

### Command 13 stream layout

Stream mode uses full `DaqSampleFrame_t` objects:

- `response` (`uint16`)
- `crc` (`uint16`)
- `channel[8]` (`int32[8]`)
- total = **36 bytes/frame**

## OpenAMP service role on CM4

### Files of interest
- `CM4/Core/Src/openamp_fs.c`
- `CM4/Core/Inc/openamp_fs.h`

CM4 implements the RPMsg service endpoint named `openamp_pingpong_demo`. This service handles file and DAQ requests from CM7.

### Main service categories

| Category | Operations |
|---|---|
| heartbeat / diagnostics | ping, init status, mount status, ADC ID, shared-memory probe |
| filesystem metadata | count `.dat`, count all files, list files, file size |
| filesystem data access | read chunk, open stream, read stream, close stream |
| maintenance | delete logs, delete specific file |
| DAQ control | get status, start log, start stream, stop, stop+close |

The operation IDs are defined locally in `CM4/Core/Src/openamp_fs.c`.

Command `99` exposes both the public mount status and lower-level FatFs mount lifecycle diagnostics. A newly formatted blank eMMC commonly reports `remote_mount_status=0`, `emmc_mount_fresult=13`, `emmc_mkfs_fresult=0`, and `emmc_post_mount_fresult=0`.

## Filesystem ownership

CM4 owns eMMC and all FatFs access in the current architecture. CM7 does not mount or write the volume directly; it proxies through CM4 using OpenAMP.

That ownership model reduces concurrency problems and keeps storage timing under CM4 control.

The eMMC boot policy is also CM4-owned. `CM4/Core/Inc/sdmmc.h` defines a slower mount/format ClockDiv (`10`) and a runtime ClockDiv (`8`). The helper functions live in CubeMX USER CODE blocks, so regenerating SDMMC setup should not remove the policy.

## Key source files

| File | Purpose |
|---|---|
| `CM4/Core/Src/main.c` | boot, peripheral init, superloop, callbacks |
| `CM4/Core/Src/openamp_fs.c` | RPMsg/OpenAMP service implementation |
| `CM4/Library/ads131m08/ads131m08.c` | low-level ADC driver |
| `CM4/Library/ads131m08/daq_engine.c` | DAQ capture, aggregation, packing, write/stream handoff |
| `CM4/Library/ads131m08/statemachine.c` | cooperative DAQ state machine |
| `CM4/Library/emmc_fs/emmc_fs.c` | FatFs wrapper and raw log file writer |
| `CM4/Core/Src/mmc_diskio.c` | low-level disk I/O glue for FatFs |

## Library documents

- [CM4 Library Index](Library/README.md)
- [ads131m08 / DAQ engine](Library/ads131m08.md)
- [eMMC filesystem wrapper](Library/emmc_fs.md)
- [OpenAMP remote service](Library/openamp_remote.md)

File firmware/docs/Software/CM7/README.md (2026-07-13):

# CM7 Firmware

## Role

CM7 is the supervisory and transport core.

It runs FreeRTOS and LwIP, maintains the TCP connection to the host, accepts host-issued commands, proxies DAQ/filesystem requests into CM4 through OpenAMP, and streams returned data back over Ethernet.

The key design rule is: **CM7 owns the control plane and the host interface**.

## Runtime responsibilities

CM7 is responsible for:

- system clock, MPU, and cache configuration
- FreeRTOS startup
- LwIP initialization
- TCP client connection to the host computer
- command receive and command dispatch
- OpenAMP master-side RPC into CM4
- framing of TCP responses and stream headers
- forwarding DAQ and file payloads from shared memory to the host

## Main components

### Boot and RTOS bring-up
- `CM7/Core/Src/main.c`
- `CM7/Core/Src/freertos.c`

### Inter-core control plane
- `CM7/Core/Src/openamp_fs.c`
- `CM7/Core/Inc/openamp_fs.h`

### Host TCP transport
- `CM7/Library/eth/tcpclient.c`
- `CM7/Library/eth/tcpclient.h`

### Utility / status indication
- `CM7/Library/led/led.c`
- `CM7/Library/led/led.h`

## FreeRTOS task model

### Tasks created today

| Task | Priority | Purpose |
|---|---|---|
| `defaultTask` | high | initializes LwIP and TCP client, then yields |
| `controllerTask` | normal | command execution and response/stream orchestration |
| `telemetryTask` | low | RGB LED status service and idle TCP heartbeat generation |

### Initialization flow

1. `main()` configures clocks, cache, MPU, GPIO, DMA, timer, and LED.
2. `MX_FREERTOS_Init()` creates queues and tasks.
3. `StartDefaultTask()` initializes LwIP and the TCP client.
4. `ControllerTask()` waits on the control queue and serves host commands.

## Command handling model

TCP receive bytes are handed to `ProcessTcpData()`, which converts them into `ControlMessage_t` items and pushes them into `gControlQueue`.

`ControllerTask()` is the main command dispatcher.

### Current command classes

| Command | Role |
|---:|---|
| `0` | heartbeat |
| `2` / `3` | file counts |
| `4` | file list with size text payload |
| `5` | file size query |
| `6` / `7` | delete logs / delete specific file |
| `8` | file stream |
| `9` | test stream |
| `10` / `110` | DAQ status |
| `11` | start DAQ log to eMMC |
| `12` | stop DAQ |
| `13` | start DAQ live stream |
| `97` | get current CM4 ADC offset calibration values |
| `98` | run CM4 ADC offset calibration and persist the new values |
| `99` | OpenAMP heartbeat / diagnostic snapshot, including eMMC mount/format and network/TCP reconnect diagnostics |
| `112` | stop and close DAQ log |

## CM7 to CM4 command path

```plantuml
@startuml
skinparam monochrome true
skinparam shadowing false
actor Host
participant TCP as "TcpClient"
participant RX as "ProcessTcpData"
participant Q as "gControlQueue"
participant CTRL as "ControllerTask"
participant OA as "CM7 OpenAmpFs"
participant CM4 as "CM4 OpenAmpFs"

Host -> TCP : TCP bytes
TCP -> RX : RxHandler callback
RX -> Q : enqueue ControlMessage_t
CTRL -> Q : xQueueReceive()
CTRL -> OA : command-specific OpenAmpFs_* API
OA -> CM4 : RPMsg request
CM4 --> OA : status / shared-memory metadata
CTRL -> TCP : fixed response or stream start
TCP --> Host : bytes on socket
@enduml
```

## Stream handling model

CM7 provides two kinds of host-visible streams:

### File stream (`command 8`)

- CM7 asks CM4 to open a persistent file stream
- CM7 repeatedly asks CM4 to fill shared SRAM with file bytes
- `TcpClient_StartStreamPtr()` sends those bytes directly from shared SRAM

### Live DAQ stream (`command 13`)

- CM7 asks CM4 to start DAQ stream mode
- CM7 repeatedly asks CM4 for the next DAQ block in shared SRAM
- each block contains full `DaqSampleFrame_t` frames
- `TcpClient_StartStreamPtr()` sends those bytes directly to the host

### Diagnostic heartbeat (`command 99`)

Command `99` is the main cross-core bring-up snapshot. CM7 performs an OpenAMP ping, probes shared memory, then returns a fixed 128-byte TCP response containing:

- OpenAMP service creation and RX counters
- CM7 OpenAMP init status
- CM4 OpenAMP init status
- CM4 eMMC public mount status
- shared-memory probe status/length/bad-index
- last file-stream open/prefetch status
- CM4 ADC device ID
- CM4 eMMC mount lifecycle diagnostics: stage, first `f_mount()` result, `f_mkfs()` result, and post-format `f_mount()` result
- board network identity: configured board IP, UID-derived board MAC, configured server IP and server port
- TCP reconnect diagnostics: current/last local source port, connect-attempt count, last connect stage, and last socket error

Network identity is centralized in `CM7/Core/Inc/aems_network_config.h` so CubeMX regeneration does not overwrite it. `CM7/LWIP/App/lwip.c` overrides generated IP bytes inside `USER CODE BEGIN IP_ADDRESSES`, and `CM7/LWIP/Target/ethernetif.c` overrides the generated MAC inside `USER CODE BEGIN MACADDRESS`.

## Shared-memory role

Shared memory is the high-throughput handoff between CM4 and CM7.

It is used to avoid routing large file/DAQ payloads through RPMsg message bodies. RPMsg returns metadata; the actual chunk bytes are placed in shared SRAM and consumed by CM7.

## OpenAMP service role on CM7

CM7 is the OpenAMP master side. It exposes blocking helper calls such as:

- `OpenAmpFs_Ping()`
- `OpenAmpFs_CountDatFiles()`
- `OpenAmpFs_ListFilesShared()`
- `OpenAmpFs_OpenFileStream()`
- `OpenAmpFs_DaqStartLog()`
- `OpenAmpFs_DaqStartStream()`
- `OpenAmpFs_DaqReadStreamShared()`
- `OpenAmpFs_DaqStop()`

These calls package CM7 requests into RPMsg messages and wait for CM4 responses.

## Notes for maintainers

- file and DAQ streaming are not purely CM7-local features; they are coordinated CM7/CM4 workflows
- the stop/stream protocol boundary for live DAQ is still a known cleanup area at the host-protocol level
- any TCP packet or stream framing changes must be coordinated with the Python host library

## Library documents

- [CM7 Library Index](Library/README.md)
- [TCP client library](Library/tcpclient.md)
- [LED helper library](Library/led.md)
- [OpenAMP master service](Library/openamp_master.md)

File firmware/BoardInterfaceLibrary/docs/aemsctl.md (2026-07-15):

# aemsctl Command Reference

`aemsctl` is the Raspberry Pi shell interface for the permanent AEMS board
daemon. It talks to `aems-boardd` over a local Unix socket.

Default socket:

```bash
/run/aems-server/aems-boardd.sock
```

## Installation

`aemsctl` is installed by the Raspberry Pi installer:

```bash
sudo bash ./deploy/install_raspberry_pi.sh
```

The executable is installed in:

```text
/opt/aems/venv/bin/aemsctl
```

The installer normally makes it available on the shell path. If not, call it
directly:

```bash
/opt/aems/venv/bin/aemsctl server status
```

`aemsctl` requires the daemon to be running:

```bash
sudo systemctl status aems-boardd --no-pager
```

Override when needed:

```bash
aemsctl --socket /tmp/aems-boardd.sock server status
```

## Server

```bash
aemsctl server status
```

Returns:

- listen host and port
- API socket path
- database path
- capture directories
- uptime
- active and known board counts

## Boards

```bash
aemsctl boards
aemsctl boards --active
```

Each board entry contains:

- IP address
- active state
- first seen timestamp
- last seen timestamp
- last connected/disconnected timestamps
- connection count
- last parsed heartbeat/openamp/status response, if available

## Jobs

```bash
aemsctl jobs
aemsctl jobs --active
```

Jobs currently cover DAQ streams started through the daemon.

## Health and Shadow

```bash
aemsctl health
aemsctl health --poll
aemsctl shadow
aemsctl shadow --poll
```

`health` returns a daemon/board/job/storage summary. `shadow` returns an AWS IoT
Device Shadow compatible document with `state.reported`.

Use `--poll` when you want the daemon to query connected boards before returning
the result. The daemon avoids health polling while it owns an active DAQ stream
job because the current firmware stream framing cannot safely interleave
arbitrary status responses into command `13` stream payloads.

## Schedules

```bash
aemsctl schedules
aemsctl schedules --enabled
```

Add a schedule:

```bash
aemsctl schedule add daily-stream \
  --board all \
  --mode daq_stream \
  --start 02:00 \
  --duration 300 \
  --file-template "daq_{board_ip}_{date}.bin" \
  --format bin
```

Enable/disable/remove:

```bash
aemsctl schedule disable daily-stream
aemsctl schedule enable daily-stream
aemsctl schedule remove daily-stream
```

Supported schedule modes:

- `daq_stream`: host-side command `13` stream job
- `daq_log`: board-side command `11` eMMC log with timed stop/close

## Transfers

```bash
aemsctl transfers
aemsctl transfers --active
```

Copy captures/metadata/manifests to a local destination:

```bash
aemsctl transfer start --target local --dest /mnt/usb/aems-upload
```

Upload captures/metadata/manifests to S3:

```bash
aemsctl transfer start --target s3 --bucket my-aems-data-bucket --prefix site-001/pi-001/
```

S3 transfer requires the optional cloud dependency and valid AWS credentials.
Run this from the `BoardInterfaceLibrary` directory:

```bash
sudo /opt/aems/venv/bin/pip install ".[cloud]"
```

## Board Commands

```bash
aemsctl board 192.168.0.10 heartbeat
aemsctl board 192.168.0.10 openamp
aemsctl board 192.168.0.10 status
```

These map to firmware commands:

- `heartbeat`: command `0`
- `openamp`: command `99`
- `status`: command `10`

## eMMC Commands

```bash
aemsctl emmc list --board 192.168.0.10
aemsctl emmc size --board 192.168.0.10 --file daq.bin
aemsctl emmc delete --board 192.168.0.10 --file daq.bin
aemsctl emmc delete-logs --board 192.168.0.10
```

Use `--board all` to run the operation on every currently connected board.

## DAQ Stream

Start one board:

```bash
aemsctl daq stream start --board 192.168.0.10 --file daq.bin --format bin --duration 30
```

Start every connected board:

```bash
aemsctl daq stream start --board all --file daq.bin --format csv --duration 30
```

### Where Stream Files Are Saved

`daq stream start` is a host-side live stream capture. The board streams command
`13` DAQ frames over TCP, and `aems-boardd` writes the received data on the
Raspberry Pi. It does not save this command `13` stream to the board eMMC.

Default output directory:

```text
/var/lib/aems-server/captures
```

Default metadata directory:

```text
/var/lib/aems-server/metadata
```

These paths come from `/etc/aems-server/config.toml`:

```toml
capture_dir = "/var/lib/aems-server/captures"
metadata_dir = "/var/lib/aems-server/metadata"
```

You can confirm the active paths with:

```bash
aemsctl server status
```

For this command:

```bash
aemsctl daq stream start --board all --file daq.bin --format csv --duration 30
```

the daemon creates one independent DAQ stream job per currently active board.
Each board gets its own output file. The filename pattern is:

```text
<board_ip_with_underscores>_<remote_file_stem>_<job_id_prefix>.<format>
```

Example for two boards:

```text
/var/lib/aems-server/captures/192_168_0_10_daq_a1b2c3d4.csv
/var/lib/aems-server/captures/192_168_0_11_daq_e5f6a7b8.csv
```

The matching metadata files are saved separately:

```text
/var/lib/aems-server/metadata/192_168_0_10_daq_a1b2c3d4.csv.metadata.json
/var/lib/aems-server/metadata/192_168_0_11_daq_e5f6a7b8.csv.metadata.json
```

For `--format csv`, the daemon first receives the raw command `13` stream into a
temporary raw binary file, converts it to physical-value CSV when the stream
stops, then deletes the temporary raw file. The final CSV contains parsed
physical values from the live stream. The metadata JSON records:

- job ID and board IP
- requested sample rate, channel mask, and block size
- output file path and output format
- command `13` stream summary
- command `12` stop ACK
- command `10` DAQ status after the stream stops
- received bytes, frames, throughput, dropped buffers, and loss estimates

For `--format bin`, the daemon keeps the raw command `13` stream bytes directly
as the final `.bin` file and writes the same metadata JSON next to it in the
metadata directory.

Use `--output-dir` to override only the capture output directory for this run:

```bash
aemsctl daq stream start --board all --file daq.bin --format csv --duration 30 --output-dir /mnt/usb/aems-captures
```

Metadata still goes to the configured daemon metadata directory.

Stop jobs:

```bash
aemsctl daq stream stop --board 192.168.0.10
aemsctl daq stream stop --job-id <job_id>
aemsctl daq stream stop
```

Arguments:

- `--format bin`: preserve raw command `13` stream bytes
- `--format csv`: convert command `13` stream frames to physical values
- `--duration`: optional automatic stop time
- `--sample-rate`: requested sample rate
- `--channel-mask`: current board limit is `0x3F`
- `--block-samples`: firmware block size, normally `128`

## eMMC DAQ Log

Start:

```bash
aemsctl daq log start --board 192.168.0.10 --file daq.bin --sample-rate 2000 --channel-mask 0x3F
```

Stop:

```bash
aemsctl daq log stop --board 192.168.0.10
```

Run a timed eMMC log as a daemon job:

```bash
aemsctl daq log run --board all --file "daq_{board_ip}_{date}.bin" --duration 3600
```

Status:

```bash
aemsctl daq status --board 192.168.0.10
aemsctl daq status --board 192.168.0.10 --log-status
```

## Calibration

```bash
aemsctl calibration get --board 192.168.0.10
aemsctl calibration run --board 192.168.0.10
```

Calibration run takes about 15 seconds on the current firmware.

## Output Format

Every command prints JSON:

```json
{
  "ok": true,
  "data": {}
}
```

Failures are also JSON:

```json
{
  "ok": false,
  "error": "Board 192.168.0.10 is not connected"
}
```

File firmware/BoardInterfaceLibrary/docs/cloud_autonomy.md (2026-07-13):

# Cloud Autonomy and AWS Integration

This page documents how the Raspberry Pi AEMS server can run autonomous DAQ locally and optionally bridge commands/health to AWS IoT Core and S3.

The important design rule is: board control stays local on the Pi. Cloud integration is a separate process that talks to the local daemon. If AWS credentials, MQTT, or internet connectivity fail, board TCP connections and local schedules can continue running.

## Process Responsibilities

| Process/tool | Required? | Responsibility |
|---|---|---|
| `aems-boardd` | yes on Raspberry Pi server | Owns TCP port `10`, accepts AEMS boards, stores board/job state, runs schedules, starts DAQ jobs, creates transfer manifests |
| `aemsctl` | yes for local control | Shell CLI that talks to `aems-boardd` through `/run/aems-server/aems-boardd.sock` |
| `aems-cloud-agent` | optional | AWS IoT Core bridge that converts MQTT commands into daemon API calls and publishes shadow updates |

`aems-cloud-agent` never talks directly to boards. It depends on `aems-boardd` being active.

## Architecture

```mermaid
flowchart LR
    B[AEMS boards] -->|TCP client :10| D[aems-boardd]
    D --> DB[(SQLite state)]
    D --> C[/captures/]
    D --> M[/metadata + manifests/]
    CLI[aemsctl] -->|Unix socket JSON API| D
    AG[aems-cloud-agent] -->|Unix socket JSON API| D
    AG <-->|MQTT commands + shadow| IOT[AWS IoT Core]
    D -->|transfer job| S3[(S3)]
```

## Installation Sequence On The Raspberry Pi

Run commands from the `BoardInterfaceLibrary` directory on the Pi.

### 1. Install daemon and CLI

```bash
sudo bash ./deploy/install_raspberry_pi.sh
```

The installer creates/configures:

- service user/group: `aems:aems`
- package virtualenv: `/opt/aems/venv`
- daemon executable: `/opt/aems/venv/bin/aems-boardd`
- CLI executable: `/opt/aems/venv/bin/aemsctl`
- cloud executable entry point: `/opt/aems/venv/bin/aems-cloud-agent`
- daemon unit: `/etc/systemd/system/aems-boardd.service`
- cloud unit: `/etc/systemd/system/aems-cloud-agent.service`
- daemon config: `/etc/aems-server/config.toml`
- cloud certificate directory: `/etc/aems-server/certs`
- daemon data root: `/var/lib/aems-server`
- captures: `/var/lib/aems-server/captures`
- metadata: `/var/lib/aems-server/metadata`
- manifests: `/var/lib/aems-server/manifests`

The installer enables and starts only `aems-boardd`. The cloud unit is installed but not enabled until AWS IoT credentials are configured.

Validate:

```bash
sudo systemctl status aems-boardd --no-pager
aemsctl server status
aemsctl boards --active
```

If `aemsctl` reports a socket permission error, log out and back in so your shell receives the `aems` group membership.

### 2. Install optional cloud dependencies

From the same `BoardInterfaceLibrary` directory:

```bash
sudo /opt/aems/venv/bin/pip install ".[cloud]"
```

This installs:

- `boto3` for S3 upload transfer jobs
- `awsiotsdk` / `awscrt` for AWS IoT Core MQTT and shadow publishing

Validate:

```bash
/opt/aems/venv/bin/aems-cloud-agent --help
/opt/aems/venv/bin/python -c "import boto3; import awscrt; print('cloud deps ok')"
```

### 3. Restart daemon after package updates

After reinstalling the package or changing daemon code:

```bash
sudo systemctl restart aems-boardd
sudo systemctl status aems-boardd --no-pager
```

If the firmware fixed-packet protocol changed, flash matching board firmware before using the updated daemon.

## Local Autonomous DAQ

Autonomous operation does not require AWS. The daemon can run schedules locally from SQLite.

### Daily live DAQ stream schedule

```bash
aemsctl schedule add morning-stream \
  --board all \
  --mode daq_stream \
  --start 02:00 \
  --duration 300 \
  --file-template "daq_{board_ip}_{date}.bin" \
  --format bin \
  --sample-rate 2000 \
  --channel-mask 0x3F \
  --block-samples 128
```

Live stream output is saved on the Pi under `/var/lib/aems-server/captures`. Metadata is saved under `/var/lib/aems-server/metadata`.

### Daily eMMC logging schedule

```bash
aemsctl schedule add morning-emmc-log \
  --board all \
  --mode daq_log \
  --start 03:00 \
  --duration 3600 \
  --file-template "emmc_{board_ip}_{date}.bin" \
  --sample-rate 2000 \
  --channel-mask 0x3F
```

For `daq_log`, the board writes data to its own eMMC. The daemon stores job ACK/status metadata under `/var/lib/aems-server/metadata`.

### Manage schedules

```bash
aemsctl schedules
aemsctl schedules --enabled
aemsctl schedule disable morning-stream
aemsctl schedule enable morning-stream
aemsctl schedule remove morning-stream
```

Template fields supported by `--file-template`:

- `{board_ip}`: board IP, for example `192.168.0.10`
- `{board}`: board IP with dots replaced by underscores
- `{site_id}`: configured site ID
- `{pi_id}`: configured Raspberry Pi ID
- `{date}`: local `YYYYMMDD`
- `{time}`: local `HHMMSS`
- `{datetime}`: local `YYYYMMDD_HHMMSS`

## Timed Jobs Without A Schedule

Start a timed live stream immediately:

```bash
aemsctl daq stream start --board all --file daq.bin --format bin --duration 300
```

Start a timed eMMC log immediately:

```bash
aemsctl daq log run --board all --file "daq_{board_ip}_{date}.bin" --duration 3600
```

Stop live stream jobs:

```bash
aemsctl daq stream stop
aemsctl daq stream stop --board 192.168.0.10
aemsctl daq stream stop --job-id <job_id>
```

## Health and Shadow Output

Local health:

```bash
aemsctl health --poll
```

AWS IoT shadow-compatible reported state:

```bash
aemsctl shadow --poll
```

The shadow document contains:

- `site_id`
- `pi_id`
- daemon uptime and paths
- storage capacity/free space
- active and historical boards
- last heartbeat/openamp/status responses
- active/recent DAQ jobs
- active/recent transfer jobs
- configured schedules

`aems-cloud-agent` publishes this payload to AWS IoT Device Shadow on:

```text
$aws/things/<thing-name>/shadow/update
```

## Transfer Jobs and Manifests

Transfer local captures/metadata/manifests to another folder:

```bash
aemsctl transfer start --target local --dest /mnt/usb/aems-upload
```

Transfer local captures/metadata/manifests to S3:

```bash
aemsctl transfer start \
  --target s3 \
  --bucket my-aems-data-bucket \
  --prefix site-001/pi-001/
```

List transfer jobs:

```bash
aemsctl transfers
aemsctl transfers --active
```

Each transfer creates a manifest under:

```text
/var/lib/aems-server/manifests
```

The manifest contains:

- transfer ID
- site ID
- Pi ID
- target
- file list
- byte counts
- SHA-256 for each file

The manifest is transferred last. Cloud ingestion can treat manifest arrival as the signal that all files listed in the manifest are available.

## AWS Resources Required From The End User

The repository does not create AWS resources automatically. You must provide the AWS pieces below.

### 1. AWS account and region

Choose the AWS region for IoT Core and S3, for example:

```text
us-east-1
```

Set this in `/etc/aems-server/config.toml`:

```toml
aws_region = "us-east-1"
```

### 2. S3 bucket and credentials

Create an S3 bucket for raw captures, metadata, and manifests.

Example config:

```toml
aws_s3_bucket = "my-aems-data-bucket"
aws_s3_prefix = "aems/site-001/pi-001/"
```

The `aems` user must have AWS credentials that allow S3 upload. Use one of:

- AWS CLI config for the `aems` user
- environment variables in a systemd drop-in
- IAM Roles Anywhere or another managed credential path

Minimum S3 permission shape:

```json
{
  "Effect": "Allow",
  "Action": ["s3:PutObject"],
  "Resource": "arn:aws:s3:::my-aems-data-bucket/aems/site-001/pi-001/*"
}
```

### 3. AWS IoT Thing and certificates

Create one IoT Thing for the Raspberry Pi, for example:

```text
aems-site-001-pi-001
```

Create/download:

- device certificate PEM
- private key PEM
- Amazon Root CA
- AWS IoT Core ATS endpoint

Install certificate files on the Pi:

```text
/etc/aems-server/certs/device.pem.crt
/etc/aems-server/certs/private.pem.key
/etc/aems-server/certs/AmazonRootCA1.pem
```

Recommended permissions:

```bash
sudo chown -R aems:aems /etc/aems-server/certs
sudo chmod 0750 /etc/aems-server/certs
sudo chmod 0640 /etc/aems-server/certs/*
```

### 4. AWS IoT policy

The IoT policy must allow the Pi to:

- connect as its thing/client ID
- subscribe to the command topic filter
- receive command topic messages
- publish command responses
- publish shadow updates

Topic pattern used by default:

```text
aems/<thing-name>/commands/#
aems/<thing-name>/responses
$aws/things/<thing-name>/shadow/update
```

The policy must cover both `iot:Subscribe` on the topic-filter ARN and `iot:Receive` on the topic ARN for the command topic. It also needs `iot:Publish` on the response topic and shadow update topic.

## Cloud Agent Configuration

Create:

```text
/etc/aems-server/cloud-agent.env
```

Example:

```bash
AEMS_AWS_IOT_ENDPOINT=xxxxxxxxxxxxxx-ats.iot.us-east-1.amazonaws.com
AEMS_AWS_THING_NAME=aems-site-001-pi-001
AEMS_AWS_CERT=/etc/aems-server/certs/device.pem.crt
AEMS_AWS_KEY=/etc/aems-server/certs/private.pem.key
AEMS_AWS_CA=/etc/aems-server/certs/AmazonRootCA1.pem
AEMS_AWS_TOPIC_PREFIX=aems/aems-site-001-pi-001
```

Secure the env file:

```bash
sudo chown root:aems /etc/aems-server/cloud-agent.env
sudo chmod 0640 /etc/aems-server/cloud-agent.env
```

Enable and start:

```bash
sudo systemctl daemon-reload
sudo systemctl enable aems-cloud-agent
sudo systemctl start aems-cloud-agent
sudo systemctl status aems-cloud-agent --no-pager
```

Logs:

```bash
journalctl -u aems-boardd -f
journalctl -u aems-cloud-agent -f
```

Manual run shape for debugging:

```bash
/opt/aems/venv/bin/aems-cloud-agent \
  --endpoint xxxxxxxxxxxxxx-ats.iot.us-east-1.amazonaws.com \
  --thing-name aems-site-001-pi-001 \
  --cert /etc/aems-server/certs/device.pem.crt \
  --key /etc/aems-server/certs/private.pem.key \
  --ca /etc/aems-server/certs/AmazonRootCA1.pem \
  --topic-prefix aems/aems-site-001-pi-001
```

Cloud agent behavior:

- `--topic-prefix` defaults to `aems/<thing-name>` if omitted.
- command subscription is `<topic-prefix>/commands/#`.
- command responses publish to `<topic-prefix>/responses`.
- shadow reported-state publishes every `--shadow-interval` seconds, default `30`.
- shadow topic is `$aws/things/<thing-name>/shadow/update`.
- payloads are JSON.
- unsupported commands are rejected and published as an error response.

## Cloud Commands

The cloud agent subscribes to:

```text
aems/<thing-name>/commands/#
```

Command payload shape:

```json
{
  "command": "daq.stream.start",
  "params": {
    "board": "all",
    "file": "daq_cloud.bin",
    "format": "bin",
    "duration": 300,
    "sample_rate": 2000,
    "channel_mask": 63,
    "block_samples": 128
  }
}
```

Supported command names:

- `health.get`
- `health.shadow`
- `daq.stream.start`
- `daq.stream.stop`
- `daq.log.start`
- `daq.log.stop`
- `daq.log.run`
- `transfer.start`
- `schedule.add`
- `schedule.remove`
- `schedule.enable`
- `boards.list`
- `jobs.list`
- `transfers.list`

Responses are published to:

```text
aems/<thing-name>/responses
```

Response shape:

```json
{
  "topic": "aems/aems-site-001-pi-001/commands/request-001",
  "request": {"command": "health.get", "params": {}},
  "result": {"ok": true, "data": {}}
}
```

## Current Board Limitation

The current firmware/tooling assumes channel mask `0x3F` for channels `0..5`. Keep cloud schedules and commands at `channel_mask = 63` unless the firmware and decoder are explicitly updated.

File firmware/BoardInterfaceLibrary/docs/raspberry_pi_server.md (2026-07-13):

# Raspberry Pi Permanent Server

The Raspberry Pi server mode runs one permanent process that listens for AEMS
boards on TCP port `10`. Boards connect as TCP clients when they are powered or
reconnected. Users then control those boards locally through the `aemsctl` shell
command.

This is separate from normal library usage. You can still install and import
`board_interface` from Windows, macOS, or Linux for direct scripting.

## Architecture

```mermaid
flowchart LR
    B1[AEMS board 192.168.0.10] -->|TCP client :10| D[aems-boardd]
    B2[AEMS board 192.168.0.11] -->|TCP client :10| D
    D --> DB[(SQLite board/job registry)]
    D --> CAP[/captures + metadata + manifests/]
    AG[aems-cloud-agent] -->|Unix socket JSON API| D
    AG <-->|MQTT/shadow| AWS[AWS IoT Core]
    CLI[aemsctl] -->|Unix socket JSON API| D
```

## Installed Paths

Default Raspberry Pi paths:

- Config: `/etc/aems-server/config.toml`
- Database: `/var/lib/aems-server/aems.db`
- Captures: `/var/lib/aems-server/captures`
- Metadata: `/var/lib/aems-server/metadata`
- Manifests: `/var/lib/aems-server/manifests`
- Local API socket: `/run/aems-server/aems-boardd.sock`

## Install

From the `BoardInterfaceLibrary` directory on the Raspberry Pi:

```bash
sudo bash ./deploy/install_raspberry_pi.sh
```

The installer:

- creates the `aems` system user
- creates the `aems` group and adds the sudo user to it when possible
- creates `/etc/aems-server/certs`
- creates `/var/lib/aems-server`
- installs the package into `/opt/aems/venv`
- installs `/etc/aems-server/config.toml`
- installs and enables `aems-boardd.service`
- installs, but does not enable, `aems-cloud-agent.service`

Log out and back in after install if `aemsctl` reports socket permission errors.

The installer deliberately keeps cloud support disabled until AWS IoT
certificates and environment variables exist. To add cloud support later:

```bash
cd BoardInterfaceLibrary
sudo /opt/aems/venv/bin/pip install ".[cloud]"
sudo systemctl daemon-reload
```

## Service Control

```bash
sudo systemctl status aems-boardd
sudo systemctl restart aems-boardd
sudo journalctl -u aems-boardd -f
```

TCP port `10` is privileged on Linux. The systemd unit grants only
`CAP_NET_BIND_SERVICE`, so the Python daemon can bind port `10` without running
the whole process as root.

Optional cloud agent service:

```bash
sudo systemctl enable aems-cloud-agent
sudo systemctl start aems-cloud-agent
sudo systemctl status aems-cloud-agent --no-pager
sudo journalctl -u aems-cloud-agent -f
```

Do not enable the cloud agent until `/etc/aems-server/cloud-agent.env` and the
AWS IoT certificate files are configured. See `cloud_autonomy.md`.

## Runtime Model

- `aems-boardd` owns TCP port `10`.
- Each board is keyed by IP address for now.
- The daemon stores board first-seen, last-seen, active state, connection count,
  and recent responses in SQLite.
- `aemsctl` never opens TCP port `10`; it talks to `/run/aems-server/aems-boardd.sock`.
- Long-running DAQ streams run as daemon jobs, not foreground shell processes.
- Schedules, transfer jobs, and health/shadow snapshots are stored in SQLite.
- `aems-cloud-agent` is optional and only talks to `aems-boardd` through the
  local Unix socket; it does not own board TCP sockets.

## Common Commands

```bash
aemsctl server status
aemsctl health --poll
aemsctl shadow --poll
aemsctl boards
aemsctl boards --active
aemsctl jobs
aemsctl jobs --active
aemsctl schedules
aemsctl transfers
```

Single-board checks:

```bash
aemsctl board 192.168.0.10 heartbeat
aemsctl board 192.168.0.10 openamp
aemsctl board 192.168.0.10 status
```

Multi-board DAQ stream:

```bash
aemsctl daq stream start --board all --file daq.bin --format bin --duration 30
aemsctl jobs --active
```

Manual stop:

```bash
aemsctl daq stream stop --board 192.168.0.10
aemsctl daq stream stop
```

eMMC DAQ log:

```bash
aemsctl daq log start --board 192.168.0.10 --file daq.bin --sample-rate 2000 --channel-mask 0x3F
aemsctl daq log stop --board 192.168.0.10
```

Timed eMMC DAQ log:

```bash
aemsctl daq log run --board all --file "daq_{board_ip}_{date}.bin" --duration 300
```

Scheduled autonomous DAQ:

```bash
aemsctl schedule add daily-stream --board all --mode daq_stream --start 02:00 --duration 300 --file-template "daq_{board_ip}_{date}.bin"
aemsctl schedules
```

Transfer completed captures:

```bash
aemsctl transfer start --target local --dest /mnt/usb/aems-upload
aemsctl transfer start --target s3 --bucket my-aems-data-bucket --prefix site-001/pi-001/
```
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

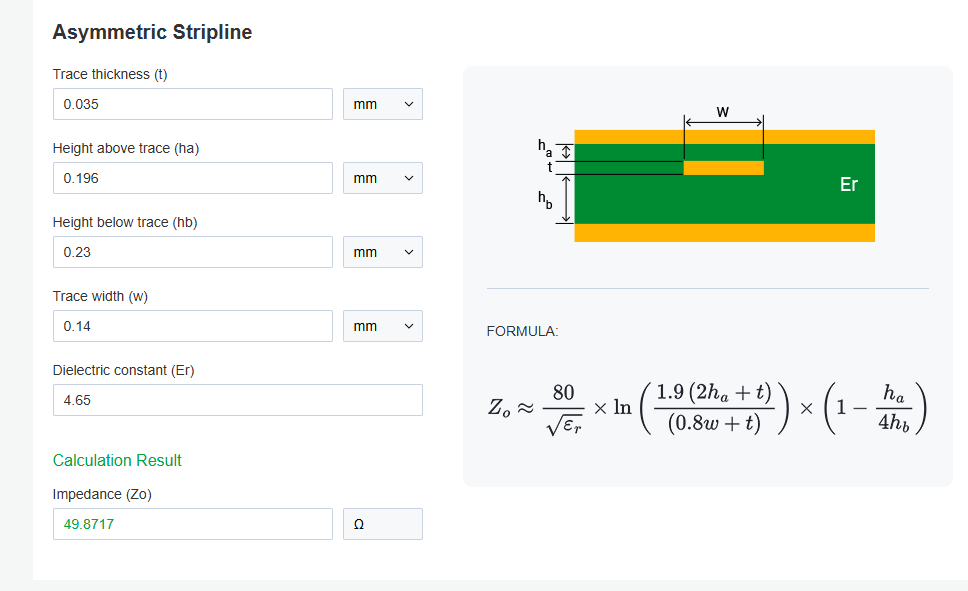
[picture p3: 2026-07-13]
hardware/DesignSummary/ImpedanceControl 50Ohm L6.png

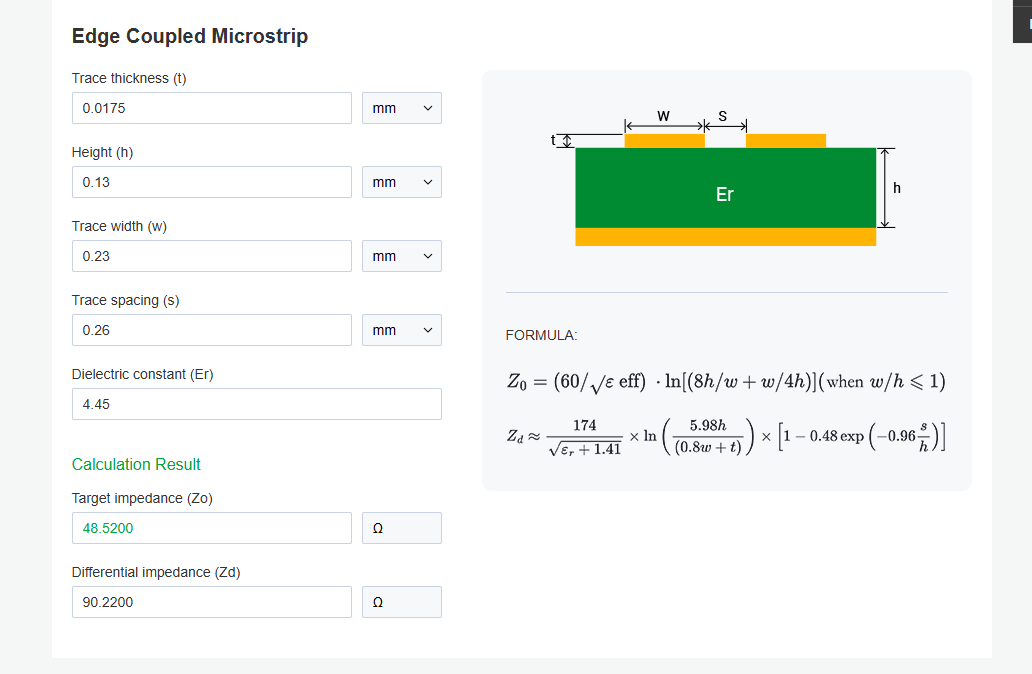
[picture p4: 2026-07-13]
hardware/DesignSummary/ImpedanceControl 90ohm L1refL2 USB.png

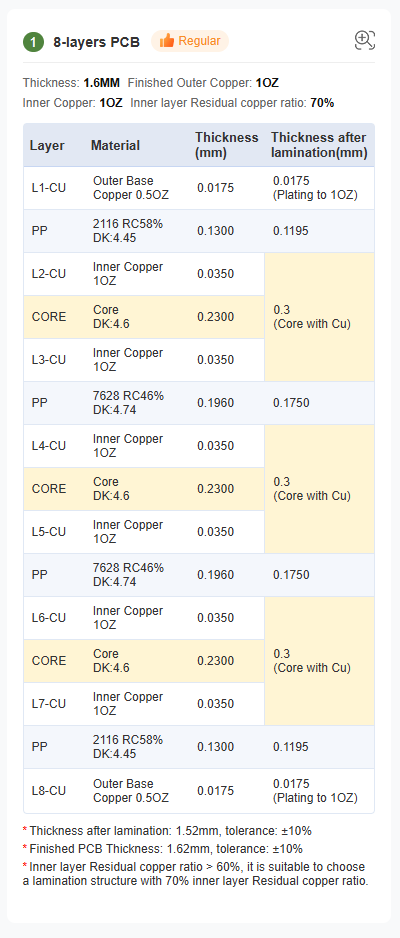
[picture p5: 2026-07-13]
hardware/DesignSummary/PCBWay Stackup.png

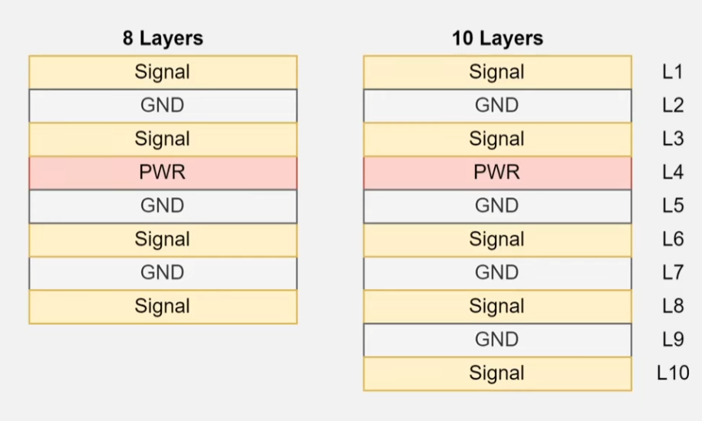
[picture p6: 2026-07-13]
hardware/DesignSummary/CurrentStackup.png

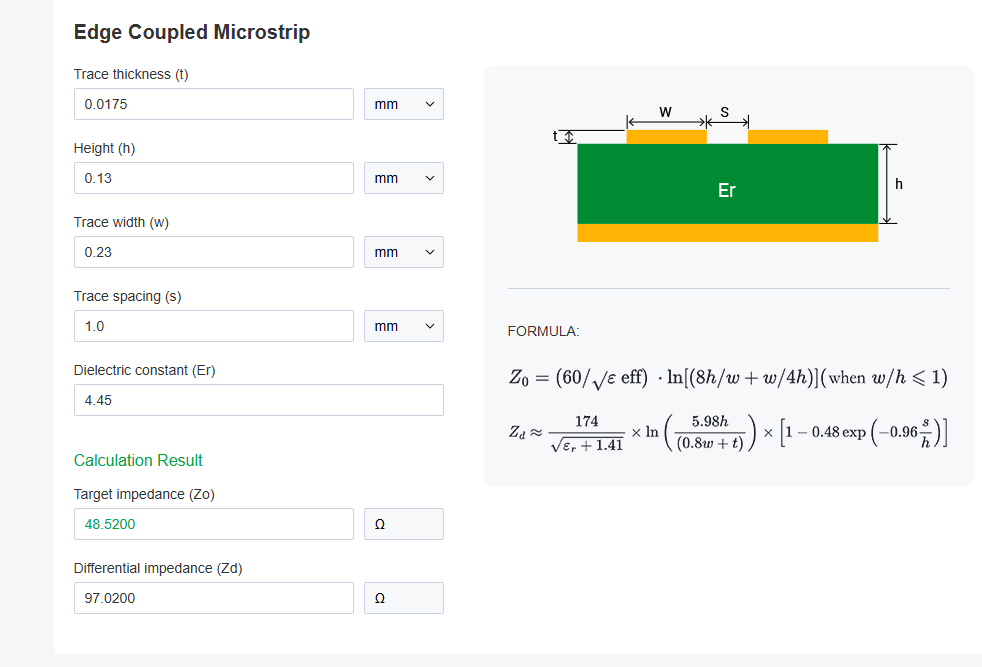
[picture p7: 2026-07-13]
hardware/DesignSummary/ImpedanceControl 100ohmDiff 50ohmSingle L1refL2 Ethernet.png

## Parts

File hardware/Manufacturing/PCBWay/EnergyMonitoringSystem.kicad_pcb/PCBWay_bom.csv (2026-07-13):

Designator | Quantity | Value | Footprint | Package | MPN | DNP | Mount_Type | Description | Distributor_Link | Manufacturer_Name | Mouser Part Number | Mouser Price/Stock | Height
C201, C202, C401, C402, C403, C404, C407, C414, C416, C417, C418, C420, C421, C422, C425, C426, C427, C430, C432, C433, C434, C502, C503, C504, C505, C506, C708, C709, C803, C804, C808, C809, C810, C901, C903, C905 | 36 | 100n | C_0402_1005Metric |  | 04023C104KAT2A |  | smt | Unpolarized capacitor | https://www.mouser.com/ProductDetail/KYOCERA-AVX/04023C104KAT2A?qs=nNezP%252BoerbAsgsxxIAjFOw%3D%3D | KYOCERA AVX
C203, C204, C301, C302, C405, C415, C431, C701, C702, C707, C805 | 11 | 10u | C_0603_1608Metric |  | KGM15CR51A106KT |  | smt | Unpolarized capacitor | https://www.mouser.com/ProductDetail/KYOCERA-AVX/KGM15CR51A106KT?qs=Jm2GQyTW%2FbjXWeIrE371aQ%3D%3D | KYOCERA AVX
C303, C304, C305, C306 | 4 | 47u | C_0603_1608Metric |  | KGM15CR50J476MT |  | smt | Unpolarized capacitor | https://www.mouser.com/ProductDetail/KYOCERA-AVX/KGM15CR50J476MT?qs=Jm2GQyTW%2FbjG5%252BWRMk5Okw%3D%3D | KYOCERA AVX
C307, C309 | 2 | 10u | 10SVPS10M |  | 10SVPS10M |  | smt | Polarized capacitor, US symbol | https://www.mouser.com/ProductDetail/Panasonic/10SVPS10M?qs=ZsfFHnjSocuoc6qZXKY4bQ%3D%3D | Panasonic
C308, C310, C406, C429, C616, C617, C807 | 7 | 1u | C_0402_1005Metric |  | KGM05AR70J105KH |  | smt | Unpolarized capacitor | https://www.mouser.com/ProductDetail/KYOCERA-AVX/KGM05AR70J105KH?qs=Jm2GQyTW%2FbhjbEFVB5FesQ%3D%3D | KYOCERA AVX
C408, C409, C423, C424, C801, C802 | 6 | 5p6 | C_0402_1005Metric |  | GJM1555C1H5R6FB01D |  | smt | Unpolarized capacitor | https://www.mouser.com/ProductDetail/Murata-Electronics/GJM1555C1H5R6FB01D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 | Murata Electronics
C410, C411 | 2 | 4u7 | C_0402_1005Metric |  | KAM05CT70J475KH |  | smt | Unpolarized capacitor | https://www.mouser.com/ProductDetail/KYOCERA-AVX/KAM05CT70J475KH?qs=amGC7iS6iy%252BulcRHQtmtBg%3D%3D | KYOCERA AVX
C412, C413, C428, C435, C501, C902, C904, C906 | 8 | 2u2 | C_0402_1005Metric |  | KGM05AR51A225KH |  | smt | Unpolarized capacitor | https://www.mouser.com/ProductDetail/KYOCERA-AVX/KGM05AR51A225KH?qs=Jm2GQyTW%2FbiyjPO%2FbUk4tw%3D%3D | KYOCERA AVX
C419 | 1 | 220p | C_0402_1005Metric |  | CC0402JRNPO9BN221 |  | smt | Unpolarized capacitor | https://www.mouser.com/ProductDetail/YAGEO/CC0402JRNPO9BN221?qs=AgBp2OyFlx9ZbPSdFesvlw%3D%3D | YAGEO
C601, C602, C603, C604, C605, C606, C610, C611, C612, C619 | 10 | 10p | C_0603_1608Metric |  | GCM1885C2A100JA16D |  | smt | Unpolarized capacitor | https://www.mouser.com/ProductDetail/Murata-Electronics/GCM1885C2A100JA16D?qs=aEuGZpxfbxWHMoMFqJj3mw%3D%3D | Murata Electronics
C607, C608, C609, C613, C614, C615 | 6 | 6800p | C_0603_1608Metric |  | CGA3EANP02A682J080AC |  | smt | Unpolarized capacitor | https://www.mouser.com/ProductDetail/TDK/CGA3EANP02A682J080AC?qs=6JAMGB%252BEdkzgcWV5VX6J2Q%3D%3D | TDK
C618 | 1 | 220n | C_0402_1005Metric |  | CGA2B2X7R1C224K050BE |  | smt | Unpolarized capacitor | https://www.mouser.com/ProductDetail/TDK/CGA2B2X7R1C224K050BE?qs=nQSIdc08i%252Be%2FATrJWqG41w%3D%3D | TDK
C703, C704, C705, C706 | 4 | 0u1 | C_0402_1005Metric |  | 04023D104JAT2A |  | smt | Unpolarized capacitor | https://www.mouser.com/ProductDetail/KYOCERA-AVX/04023D104JAT2A?qs=r5DSvlrkXmJgSdo5yOX5%2Fw%3D%3D | KYOCERA AVX
C806 | 1 | 470p | C_0402_1005Metric |  | GCM1555C2A471JE02D |  | smt | Unpolarized capacitor | https://www.mouser.com/ProductDetail/Murata-Electronics/GCM1555C2A471JE02D?qs=ZcfC38r4PovohJEnU3KwxA%3D%3D | Murata Electronics
C812 | 1 | 1n | C_0402_1005Metric |  | 04025C102KAZ2A |  | smt | Unpolarized capacitor | https://www.mouser.com/ProductDetail/KYOCERA-AVX/04025C102KAZ2A?qs=%252BdQmOuGyFcHUWKrsS7iuyw%3D%3D | KYOCERA AVX
D201 | 1 | ESDA7P60-1U1M | ESDA7P60-1U1M |  | ESDA7P60-1U1M |  | smt | STMicroelectronics ESDA7P60-1U1M Uni-Directional TVS Diode, 700W peak, 2-Pin QFN1610 | https://www.mouser.co.uk/ProductDetail/STMicroelectronics/ESDA7P60-1U1M?qs=kWQV1gtkNnfgxoDhWqG%2FZA%3D%3D | STMicroelectronics | 511-ESDA7P60-1U1M | https://www.mouser.co.uk/ProductDetail/STMicroelectronics/ESDA7P60-1U1M?qs=kWQV1gtkNnfgxoDhWqG%2FZA%3D%3D
D202 | 1 | BAT30KFILM | BAT30KFILM |  | BAT30KFILM |  | smt | STMicroelectronics BAT30KFILM, SMT Schottky Diode, 30V 300mA, 2-Pin SOD-523 | https://www.mouser.co.uk/ProductDetail/STMicroelectronics/BAT30KFILM?qs=jZi1jxfVU97WgdRkbosYSw%3D%3D | STMicroelectronics | 511-BAT30KFILM | https://www.mouser.co.uk/ProductDetail/STMicroelectronics/BAT30KFILM?qs=jZi1jxfVU97WgdRkbosYSw%3D%3D | 0.7
D301, D302 | 2 | LED | LED_0402_1005Metric |  | 150040RS73240 |  | smt | Light emitting diode | https://www.mouser.com/ProductDetail/Wurth-Elektronik/150040RS73240?qs=8Aam6%252B7C6HGMiInmnlrBiw%3D%3D | Wurth Elektronik
D401, D402 | 2 | ESDALC6V1-1M2 | ESDALC6V11M2 |  | ESDALC6V1-1M2 |  | smt | ESD Suppressors / TVS Diodes Low cap TRANSIL | https://www.mouser.co.uk/ProductDetail/STMicroelectronics/ESDALC6V1-1M2?qs=Cak7mXXNf1Vp5Y5FXrX40g%3D%3D | STMicroelectronics | 511-ESDALC6V1-1M2 | https://www.mouser.co.uk/ProductDetail/STMicroelectronics/ESDALC6V1-1M2?qs=Cak7mXXNf1Vp5Y5FXrX40g%3D%3D
D403, D404, D405, D406, D408 | 5 | PESD3V3L1BA,115 | PESD3V3L1BA_115-SOD-323-2 |  | PESD3V3L1BA,115 |  | smt | PESD3V3L1BA - Low capacitance bidirectional ESD protection diode in SOD323 | https://www.mouser.co.uk/ProductDetail/Nexperia/PESD3V3L1BA115?qs=LOCUfHb8d9tfcQwAsqvzKg%3D%3D | Nexperia | 771-PESD3V3L1BA-T/R | https://www.mouser.co.uk/ProductDetail/Nexperia/PESD3V3L1BA115?qs=LOCUfHb8d9tfcQwAsqvzKg%3D%3D | 1.1
D407 | 1 | LED_RAGB | LED_Kingbright_APFA3010_3x1.5mm_Horizontal |  | APFA3010LSEEZGKQBKC |  | smt | RGB LED, red/anode/green/blue | https://www.mouser.com/ProductDetail/Kingbright/APFA3010LSEEZGKQBKC?qs=ZqXcJfGlKsh4RNXwluO8Eg%3D%3D | Kingbright
FB401, FB801 | 2 | FerriteBead | L_0603_1608Metric |  | BBGK00160808601Y00 |  | smt | Ferrite bead | https://www.mouser.com/ProductDetail/Pulse-Electronics/BBGK00160808601Y00?qs=DRkmTr78QASbvvb5JKCdog%3D%3D | Pulse Electronics
FB402 | 1 | FerriteBead | L_0603_1608Metric |  | FBMJ1608HM180NTR |  | smt | Ferrite bead | https://www.mouser.com/ProductDetail/TAIYO-YUDEN/FBMJ1608HM180NTR?qs=qEEMd6hQM8W1%252BaWOtiVIaA%3D%3D | Taiyo Yuden
FB701, FB702 | 2 | FerriteBead | BLM15HD182SN1D |  | BLM15HD182SN1D |  | smt | Ferrite bead | https://www.mouser.com/ProductDetail/Murata-Electronics/BLM15HD182SN1D?qs=0VEDk56ETToBhybuH4wvpA%3D%3D | Murata Electronics
J201 | 1 | USB_C_Receptacle_USB2.0_16P | USB_C_Receptacle_GCT_USB4105-xx-A_16P_TopMnt_Horizontal |  | USB4105-GF-A |  | smt | USB 2.0-only 16P Type-C Receptacle connector | https://www.mouser.com/ProductDetail/GCT/USB4105-GF-A?qs=KUoIvG%2F9IlY%2FMLlBMpStpA%3D%3D | GCT
J202, J601, J602, J603, J604, J605, J606 | 7 | Screw_Terminal_01x02 | TerminalBlock_Phoenix_MKDS-1,5-2-5.08_1x02_P5.08mm_Horizontal |  | 1548128 |  | tht | Generic screw terminal, single row, 01x02, script generated (kicad-library-utils/schlib/autogen/connector/) | https://www.mouser.com/ProductDetail/Phoenix-Contact/1548128?qs=ulEaXIWI0c87QOzP9yohxA%3D%3D | Phoenix Contact
J401, J502 | 2 | Conn_02x05_Counter_Clockwise | 62701021621 |  | 62701021621 |  | tht | Generic connector, double row, 02x05, odd/even pin numbering scheme (row 1 odd numbers, row 2 even numbers), script generated (kicad-library-utils/schlib/autogen/connector/) | https://www.mouser.com/ProductDetail/Wurth-Elektronik/62701021621?qs=1Kr7Jg1SGW%252Bbz%2FJ7gpmd%2Fg%3D%3D | Wurth Elektronik
J501 | 1 | CLP-110-02-G-D | CLP-110-02-XXX-D |  | CLP-110-02-G-D |  | smt | 20 Position Connector Header, Center Strip Contacts Surface Mount | https://www.mouser.com/ProductDetail/Samtec/CLP-110-02-G-D?qs=0lQeLiL1qyaw0wV0yc599g%3D%3D | SAMTEC | 200-CLP11002GD | https://www.mouser.co.uk/ProductDetail/Samtec/CLP-110-02-G-D?qs=0lQeLiL1qyaw0wV0yc599g%3D%3D
J503 | 1 | Conn_02x08_Counter_Clockwise | PinHeader_2x10_P2.54mm_Vertical |  | M20-9720546 |  | tht | Generic connector, double row, 02x10, odd/even pin numbering scheme (row 1 odd numbers, row 2 even numbers), script generated (kicad-library-utils/schlib/autogen/connector/) | https://www.mouser.com/ProductDetail/Harwin/M20-9720546?qs=vF78I%252BjhbY95YP90xzX2TQ%3D%3D | Harwin
J701 | 1 | Screw_Terminal_01x03 | TerminalBlock_Phoenix_MKDS-1,5-3-5.08_1x03_P5.08mm_Horizontal |  | 1548129 |  | tht | Generic screw terminal, single row, 01x03, script generated (kicad-library-utils/schlib/autogen/connector/) | https://www.mouser.com/ProductDetail/Phoenix-Contact/1548129?qs=ulEaXIWI0c%2FYtJCBk3iUtQ%3D%3D | Phoenix Contact
J702 | 1 | DM3AT-SF-PEJM5_40_ | DM3ATSFPEJM540 |  | DM3AT-SF-PEJM5(40) |  | smt | Memory Card Connectors MICRO SD CD CONN STD SMT PUSHPUSH | https://www.mouser.co.uk/ProductDetail/Hirose-Connector/DM3AT-SF-PEJM540?qs=0WLLhGLuJYzPvbo0KPPEoQ%3D%3D | Hirose | 798-DM3AT-SF-PEJM540 | https://www.mouser.co.uk/ProductDetail/Hirose-Connector/DM3AT-SF-PEJM540?qs=0WLLhGLuJYzPvbo0KPPEoQ%3D%3D | 1.83
J801 | 1 | SI-60062-F | Connector-SI60062F |  | SI-60062-F |  | tht | Bel-Stewart Female RJ45 Modular Jack, STP, Straight, Through Hole Mount, MagJack | https://www.mouser.com/ProductDetail/Bel-Magnetic-Solutions/SI-60062-F?qs=FESYatJ8odK8fgoNWoNb9g%3D%3D | BelFuse | 530-SI-60062-F |  | 13.84
L301, L302, L401 | 3 | 2u2 | L_0603_1608Metric |  | MCHK1608T2R2MKN |  | smt | Inductor | https://www.mouser.com/ProductDetail/TAIYO-YUDEN/MCHK1608T2R2MKN?qs=hWgE7mdIu5TOfQbNfL22HA%3D%3D | TAIYO YUDEN
L303, L304 | 2 | 10u | L_0805_2012Metric |  | LQM21FN100M80L |  | smt | Inductor | https://www.mouser.com/ProductDetail/Murata-Electronics/LQM21FN100M80L?qs=%2F%252BYoplLUB5jHVlRNWlo0OQ%3D%3D | Murata Electronics
Q201 | 1 | STL6N3LLH6 | STL6N3LLH6 |  | STL6N3LLH6 |  | smt | STMicroelectronics STL6N3LLH6 N-channel MOSFET Transistor, 6 A, 30 V, 6-Pin PowerFLAT | https://www.mouser.co.uk/ProductDetail/STMicroelectronics/STL6N3LLH6?qs=symtzNQNgQLOqUYDqyK2eQ%3D%3D | STMicroelectronics | 511-STL6N3LLH6 | https://www.mouser.co.uk/ProductDetail/STMicroelectronics/STL6N3LLH6?qs=symtzNQNgQLOqUYDqyK2eQ%3D%3D
R201, R404, R607, R608, R609, R637 | 6 | 10k | R_0603_1608Metric |  | CRCW060310K0FKEI |  | smt | Resistor | https://www.mouser.com/ProductDetail/Vishay-Dale/CRCW060310K0FKEI?qs=3qWEzBg5KnKofE%252B8acPBRA%3D%3D | Vishay/Dale
R202 | 1 | 2k7 | R_0603_1608Metric |  | SFR03EZPF2701 |  | smt | Resistor | https://www.mouser.com/ProductDetail/ROHM-Semiconductor/SFR03EZPF2701?qs=Mv7BduZupUiLN9LTZV3rpg%3D%3D | ROHM Semiconductor
R203, R701 | 2 | 120R | R_0402_1005Metric |  | SFR01MZPF1200 |  | smt | Resistor | https://www.mouser.com/ProductDetail/ROHM-Semiconductor/SFR01MZPF1200?qs=byeeYqUIh0O51%2Fd5wyiQxA%3D%3D | ROHM Semiconductor
R301, R302, R638, R639 | 4 | 100k | R_0603_1608Metric |  | CRCW0603100KFKEE |  | smt | Resistor | https://www.mouser.com/ProductDetail/Vishay-Dale/CRCW0603100KFKEE?qs=%252B6g0mu59x7I1D%252BO0qMg%252Bjg%3D%3D | Vishay/Dale
R303, R304 | 2 | 220R | R_0402_1005Metric |  | RC0402FR-07221RL |  | smt | Resistor | https://www.mouser.com/ProductDetail/YAGEO/RC0402FR-07221RL?qs=YDy31nmf64y04UoKIvC83Q%3D%3D | YAGEO
R401, R402, R403, R502 | 4 | 22R | R_0603_1608Metric |  | ERJ-S03F22R0V |  | smt | Resistor | https://www.mouser.com/ProductDetail/Panasonic/ERJ-S03F22R0V | Panasonic
R405, R406, R407, R622, R623, R624, R625, R626, R627 | 9 | 1k | R_0603_1608Metric |  | CRCW06031K00FKEE |  | smt | Resistor | https://www.mouser.com/ProductDetail/Vishay-Dale/CRCW06031K00FKEE?qs=%252B6g0mu59x7JNM5l%252Bg7fBgQ%3D%3D | Vishay/Dale
R408, R409, R410, R411, R811, R812, R813, R815 | 8 | 49R9 | R_0402_1005Metric |  | M55342K11B49D9RS2 |  | smt | Resistor | https://www.mouser.com/ProductDetail/Vishay/M55342K11B49D9RS2?qs=DRnBzpJSeP4mXvhGAQSKpg%3D%3D | Vishay
R412, R413, R414, R631, R632, R633, R634, R635, R636 | 9 | 33R | R_0603_1608Metric |  | ESR03EZPF33R0 |  | smt | Resistor | https://www.mouser.com/ProductDetail/ROHM-Semiconductor/ESR03EZPF33R0?qs=493kPxzlxfImjDH5P%252Bz4Hw%3D%3D | ROHM Semiconductor
R501 | 1 | 47k | R_0603_1608Metric |  | CRCW060347K0FKEAHP |  | smt | Resistor | https://www.mouser.com/ProductDetail/Vishay-Dale/CRCW060347K0FKEAHP?qs=k2%2FDWSARqgGdf8xU6XXKnw%3D%3D | Vishay/Dale
R503 | 1 | 4k7 | R_0603_1608Metric |  | SR0603FR-7T4K7L |  | smt | Resistor | https://www.mouser.com/ProductDetail/YAGEO/SR0603FR-7T4K7L?qs=1mbolxNpo8e2BYIAXFrBnQ%3D%3D | YAGEO
R601, R602, R603 | 3 | R_Variable | B72220S0271K101 |  | B72220S0271K101 |  | tht | Variable resistor | https://www.mouser.com/ProductDetail/EPCOS-TDK/B72220S0271K101?qs=dEfas%2FXlABJm%252BgabQzQHxg%3D%3D | EPCOS/TDK
R604, R605, R606, R610, R611, R612, R613, R614, R615 | 9 | 330k | R_0805_2012Metric |  | TNPV0805330KBEEA |  | smt | Resistor | https://www.mouser.com/ProductDetail/Vishay-Dale/TNPV0805330KBEEA?qs=Li%252BoUPsLEnvXdeF%2FViJuBw%3D%3D | Vishay/Dale
R616, R617, R618 | 3 | 15k | R_0603_1608Metric |  | ERJ-3EKF1502V |  | smt | Resistor | https://www.mouser.com/ProductDetail/Panasonic/ERJ-3EKF1502V?qs=H7k1u0Mp9JTF6x646045AQ%3D%3D | Panasonic
R619, R620, R621 | 3 | 750R | R_0805_2012Metric |  | RT0805FRE10750RL |  | smt | Resistor | https://www.mouser.com/ProductDetail/YAGEO/RT0805FRE10750RL?qs=F5EMLAvA7IAUd7LY9VBaDQ%3D%3D | YAGEO
R628, R629, R630 | 3 | 2k | R_0603_1608Metric |  | ERJ-PA3F2001V |  | smt | Resistor | https://www.mouser.com/ProductDetail/Panasonic/ERJ-PA3F2001V?qs=BzJM0faLVqX48axB4MDEgw%3D%3D | Panasonic
R801, R802, R804, R805 | 4 | 33R | R_0402_1005Metric |  | RC0402FR-7D33RL |  | smt | Resistor | https://www.mouser.com/ProductDetail/YAGEO/RC0402FR-7D33RL?qs=F5EMLAvA7IDm7JsSOw%2FPgg%3D%3D | YAGEO
R803, R806, R807, R808, R810, R816, R817, R910 | 8 | 10k | R_0402_1005Metric |  | ERJ-PA2F1002X |  | smt | Resistor | https://www.mouser.com/ProductDetail/Panasonic/ERJ-PA2F1002X | Panasonic
R809 | 1 | 1k5 | R_0402_1005Metric |  | RT73F1J1K5BTD |  | smt | Resistor | https://www.mouser.com/ProductDetail/TE-Connectivity-Holsworthy/RT73F1J1K5BTD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 | TE Connectivity
R814 | 1 | 12k1 | R_0603_1608Metric |  | ERJ-P03F1212V |  | smt | Resistor | https://www.mouser.com/ProductDetail/Panasonic/ERJ-P03F1212V?qs=18kBAoNi3c8cWfKXlKmFJQ%3D%3D | Panasonic
R818, R819 | 2 | 270R | R_0603_1608Metric |  | CRGH0603F270R |  | smt | Resistor | https://www.mouser.com/ProductDetail/TE-Connectivity-Holsworthy/CRGH0603F270R?qs=gt1LBUVyoHkSOaKreGSGBQ%3D%3D | TE Connectivity
R820, R922 | 2 | 0R | R_0603_1608Metric |  | CRCW06030000Z0EI |  | smt | Resistor | https://www.mouser.com/ProductDetail/Vishay/CRCW06030000Z0EI?qs=%252B6g0mu59x7L7KQG%252Bwwt0jQ%3D%3D | Vishay
R901, R902, R903, R904, R905, R906, R907, R908, R909, R921 | 10 | 47k | R_0402_1005Metric |  | RC0402FR-7D47KL |  | smt | Resistor | https://www.mouser.com/ProductDetail/YAGEO/RC0402FR-7D47KL | YAGEO
R911, R912 | 2 | 22R | R_0402_1005Metric |  | RC0402FR-7D22RL |  | smt | Resistor | https://www.mouser.com/ProductDetail/YAGEO/RC0402FR-7D22RL | YAGEO
R913, R914, R915, R916, R917, R918, R919, R920 | 8 | 22R | R_0402_1005Metric |  | RC0402FR-7D22RL |  | smt | Resistor | https://www.mouser.com/ProductDetail/YAGEO/RC0402FR-7D22RL | YAGEO
SW401, SW402 | 2 | SW_Push | SW_SPST_CK_RS282G05A3 |  | RS282G05A3SMRT |  | smt | Push button switch, generic, two pins | https://www.mouser.com/ProductDetail/CK/RS-282G05A3-SM-RT?qs=T%252BgPUmif8%252BjtyA9QuPnoeg%3D%3D | C&K
TP201, TP202, TP301, TP302, TP303, TP304, TP701, TP702, TP703, TP901 | 10 | TestPoint | TestPoint_Pad_D3.0mm |  |  |  | tht | test point
U201 | 1 | TCPP01-M12 | TCPP01-M12-QFN-12L |  | TCPP01-M12 |  | smt | USB type-C port protection | https://www.mouser.co.uk/ProductDetail/STMicroelectronics/TCPP01-M12?qs=%252B6g0mu59x7KCafIwapwG2A%3D%3D | STMicroelectronics | 511-TCPP01-M12 | https://www.mouser.co.uk/ProductDetail/STMicroelectronics/TCPP01-M12?qs=%252B6g0mu59x7KCafIwapwG2A%3D%3D | 1
U202 | 1 | STEF05SGR | STEF05SGR-TSOT23-8L |  | STEF05SGR |  | smt | Electronic Fuse Regulator - 3.6A 10-DFN (3x3) | https://www.mouser.co.uk/ProductDetail/STMicroelectronics/STEF05SGR?qs=%252B6g0mu59x7KvRRED919Zdw%3D%3D | STMicroelectronics | 511-STEF05SGR | https://www.mouser.co.uk/ProductDetail/STMicroelectronics/STEF05SGR?qs=%252B6g0mu59x7KvRRED919Zdw%3D%3D | 1
U203 | 1 | USBLC6-2P6 | USBLC62P6-SOT666-6 |  | USBLC6-2P6 |  | smt | ESD Suppressors / TVS Diodes High Speed Interface Protection Low Cap | https://www.mouser.co.uk/ProductDetail/STMicroelectronics/USBLC6-2P6?qs=6ARB0lp6jlViGcbUSvj1Mw%3D%3D | STMicroelectronics | 511-USBLC6-2P6 | https://www.mouser.co.uk/ProductDetail/STMicroelectronics/USBLC6-2P6?qs=6ARB0lp6jlViGcbUSvj1Mw%3D%3D | 0.6
U301, U302 | 2 | ST1PS02CQTR | ST1PS02CQTR |  | ST1PS02CQTR |  | smt | Switching Voltage Regulators 400mA Nano-Quiescent Synchronous step-down converter digital volt Power Good AUX | https://www.mouser.co.uk/ProductDetail/STMicroelectronics/ST1PS02CQTR?qs=sPbYRqrBIVkrGj42PMRzhg%3D%3D | STMicroelectronics | 511-ST1PS02CQTR | https://www.mouser.co.uk/ProductDetail/STMicroelectronics/ST1PS02CQTR?qs=sPbYRqrBIVkrGj42PMRzhg%3D%3D | 0.55
U303 | 1 | LDLN025M12R | LDLN025M12R-SOT-23-5 |  | LDLN025M12R |  | smt | 250 mA ultra-low noise LDO | https://www.mouser.co.uk/ProductDetail/STMicroelectronics/LDLN025M12R?qs=5aG0NVq1C4zrayTBALXrUQ%3D%3D | STMicroelectronics | 511-LDLN025M12R | https://www.mouser.co.uk/ProductDetail/STMicroelectronics/LDLN025M12R?qs=5aG0NVq1C4zrayTBALXrUQ%3D%3D | 1.45
U304 | 1 | LM2664M6_NOPB | LM2664M6_NOPB-SOT-23-6 |  | LM2664M6/NOPB |  | smt | 1.8V to 5.5Vin Switched Capacitor Voltage Converter | https://www.mouser.co.uk/ProductDetail/Texas-Instruments/LM2664M6-NOPB?qs=X1J7HmVL2ZFqN%2Fb7EAhtIA%3D%3D | Texas Instruments | 926-LM2664M6/NOPB | https://www.mouser.co.uk/ProductDetail/Texas-Instruments/LM2664M6-NOPB?qs=X1J7HmVL2ZFqN%2Fb7EAhtIA%3D%3D | 1.45
U401 | 1 | STM32H745ZGT6 | STM32H745ZGT6_LQFP144 |  | STM32H745ZGT6 |  | smt | IC MCU 32BIT 1MB FLASH 144LQFP | https://www.arrow.com/en/products/stm32h745zgt6/stmicroelectronics?region=nac | STMicroelectronics | 511-STM32H745ZGT6 | https://www.mouser.co.uk/ProductDetail/STMicroelectronics/STM32H745ZGT6?qs=%252B6g0mu59x7JX5wfM7tEzng%3D%3D | 1.6
U501 | 1 | BLUENRG-M2SA | BLUENRG-M2SA |  | BLUENRG-M2SA |  | smt | STMicroelectronics | https://www.mouser.co.uk/ProductDetail/STMicroelectronics/BLUENRG-M2SA?qs=%252B6g0mu59x7K3hjyySj690A%3D%3D | STMicroelectronics | 511-BLUENRG-M2SA | https://www.mouser.co.uk/ProductDetail/STMicroelectronics/BLUENRG-M2SA?qs=%252B6g0mu59x7K3hjyySj690A%3D%3D | 2.5
U601, U602, U603 | 3 | TSV911ILT | TSV911ILT_SOT23-5 |  | TSV911ILT |  | smt |  | https://www.mouser.com/ProductDetail/STMicroelectronics/TSV911ILT?qs=RJLCOMRfwh0RYaQNK47UtQ%3D%3D | STMicroelectronics
U604 | 1 | ADS131M08IRSNR | ADS131M08IRSNR-QFN40 |  | ADS131M08IRSNR |  | smt |  | https://www.mouser.com/ProductDetail/Texas-Instruments/ADS131M08IRSNR?qs=iLbezkQI%252BsiKQHmiUzcSQg%3D%3D | Texas Instruments
U701 | 1 | ADM2565EBRNZ | ADM2565EBRNZ-SOIC-28 |  | ADM2565EBRNZ |  | smt |  | https://www.mouser.com/ProductDetail/Analog-Devices/ADM2565EBRNZ?qs=DPoM0jnrROUAp2vbRe3rEw%3D%3D | Analog Devices
U702 | 1 | EMIF06-MSD02N16 | EMIF06-MSD02N16 |  | EMIF06-MSD02N16 |  | smt | 6-Line EMI filter&ESD for SD card uQFN16 STMicroelectronics EMIF06-MSD02N16, EMI Filter & ESD Protector | https://www.mouser.co.uk/ProductDetail/STMicroelectronics/EMIF06-MSD02N16?qs=1CGoW%2F3pMwpSqVuN8kmN4Q%3D%3D | STMicroelectronics | 511-EMIF06-MSD02N16 | https://www.mouser.co.uk/ProductDetail/STMicroelectronics/EMIF06-MSD02N16?qs=1CGoW%2F3pMwpSqVuN8kmN4Q%3D%3D | 0
U801 | 1 | LAN8742A-CZ-TR | LAN8742A-CZ-TR_QFN50 |  | LAN8742A-CZ-TR |  | smt | Ethernet ICs | https://www.mouser.com/ProductDetail/Microchip-Technology/LAN8742A-CZ-TR?qs=6qKXPk0vzx0Y6uPCt7MXWw%3D%3D | Microchip | 579-LAN8742A-CZ-TR | https://www.mouser.co.uk/ProductDetail/Microchip-Technology/LAN8742A-CZ-TR?qs=6qKXPk0vzx0Y6uPCt7MXWw%3D%3D | 1
U901 | 1 | MX52LM04A11XSI | MX52LM04A11XSI_BGA153 |  | MX52LM04A11XSI |  | smt | FLASH - NAND (MLC) Memory IC 32Gbit eMMC_5.1 200 MHz 153-LFBGA (11.5x13) | https://www.mouser.com/ProductDetail/Macronix/MX52LM04A11XSI?qs=vOcB1WHNNXJCwnH5CmUP8A%3D%3D | Macronix | 95-52LM04A11XSIT | https://www.mouser.co.uk/ProductDetail/Macronix/MX52LM04A11XSI?qs=vOcB1WHNNXJCwnH5CmUP8A%3D%3D | 0.8
Y401, Y801 | 2 | Crystal_GND24 | NX3225SA25000MSTDCSR6 |  | NX3225SA-25.000M-STD-CSR-6 |  | smt | Four pin crystal, GND on pins 2 and 4 | https://www.mouser.com/ProductDetail/NDK/NX3225SA-25.000M-STD-CSR-6?qs=w%2Fv1CP2dgqpEjeC0SO%2Fwdg%3D%3D | NDK
Y402 | 1 | 32.768KHz | Crystal_SMD_3215-2Pin_3.2x1.5mm |  | NX3215SA-32.768K-STD-MUA-14 |  | smt | Two pin crystal | https://www.mouser.com/ProductDetail/NDK/NX3215SA-32.768K-STD-MUA-14?qs=55YtniHzbhCTyKGENMTVrQ%3D%3D | NDK

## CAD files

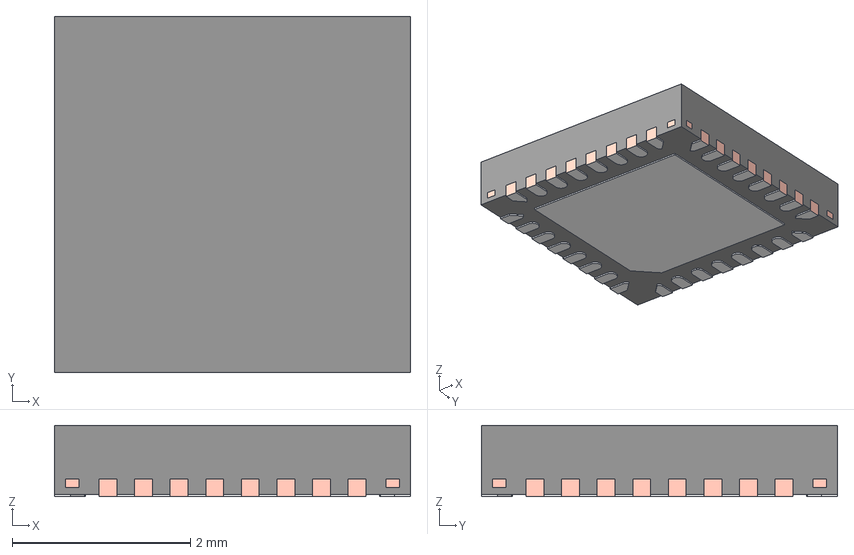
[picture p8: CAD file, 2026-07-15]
hardware/CustomLibs/Downloaded/ADC/ADS131M08IPBS/ADS131M08IRSNR.stp
4.00 x 4.00 x 0.8 mm
BODY-QFN
FRAME-RSN0032B
PIN1-ID

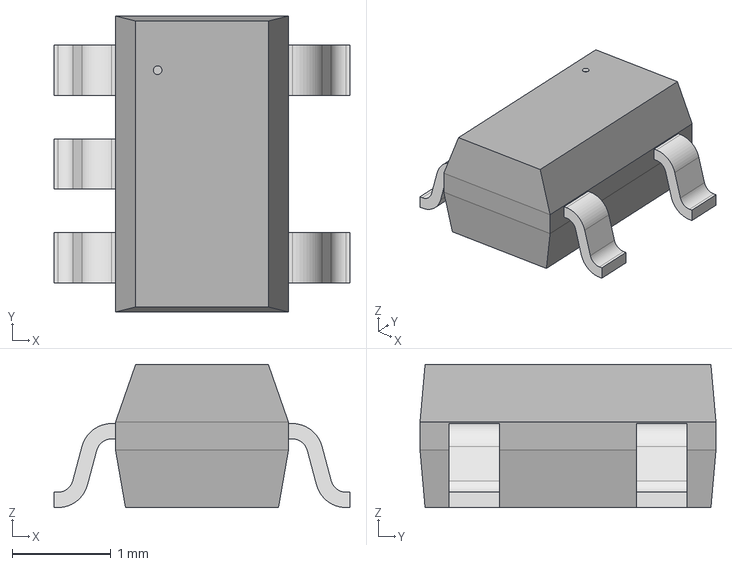
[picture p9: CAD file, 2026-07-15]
hardware/CustomLibs/Downloaded/ADC/TSV911ILT/TSV911ILT.step
3.00 x 3.00 x 1.45 mm

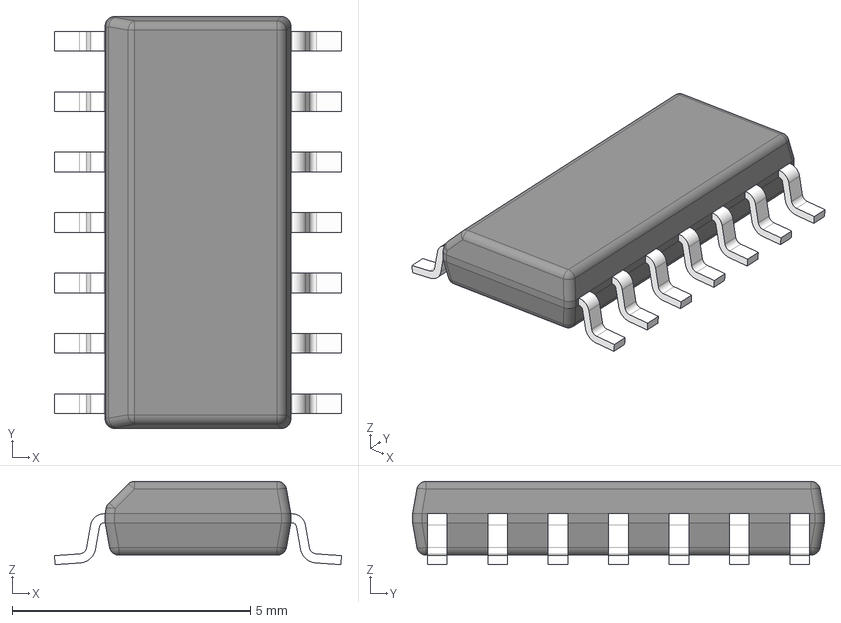
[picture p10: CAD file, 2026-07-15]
hardware/CustomLibs/Downloaded/ADC/TSV914AIDR/TSV914AIDR.stp
6.03 x 8.65 x 1.75 mm
BODY-SO
LEAD-SO x 14
PIN1-ID

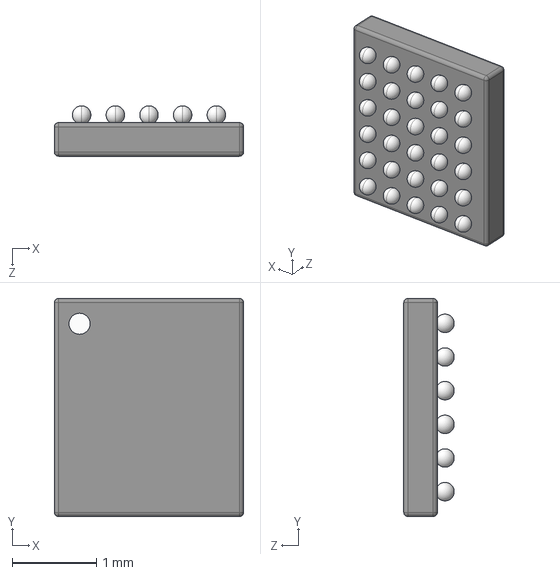
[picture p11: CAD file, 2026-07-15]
hardware/CustomLibs/Downloaded/BM/STBC02AJR/STBC02AJR.stp
2.25 x 2.59 x 0.6 mm

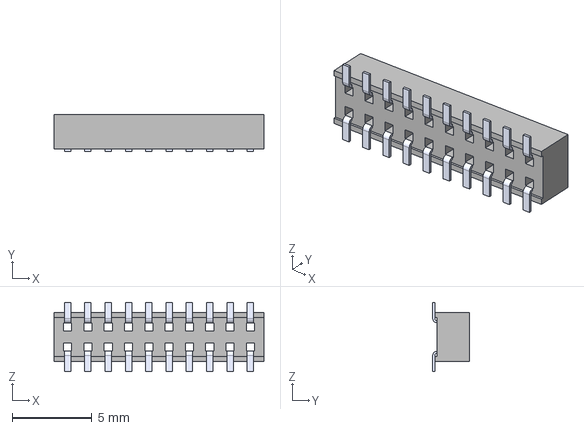
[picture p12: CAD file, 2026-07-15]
hardware/CustomLibs/Downloaded/CONNECTORS/CLP-110-02-G-D/CLP-110-02-G-D.stp
13.1 x 2.29 x 4.32 mm
C-106-22-110_Pin x 2
CLP-110-2-L-D_terminal

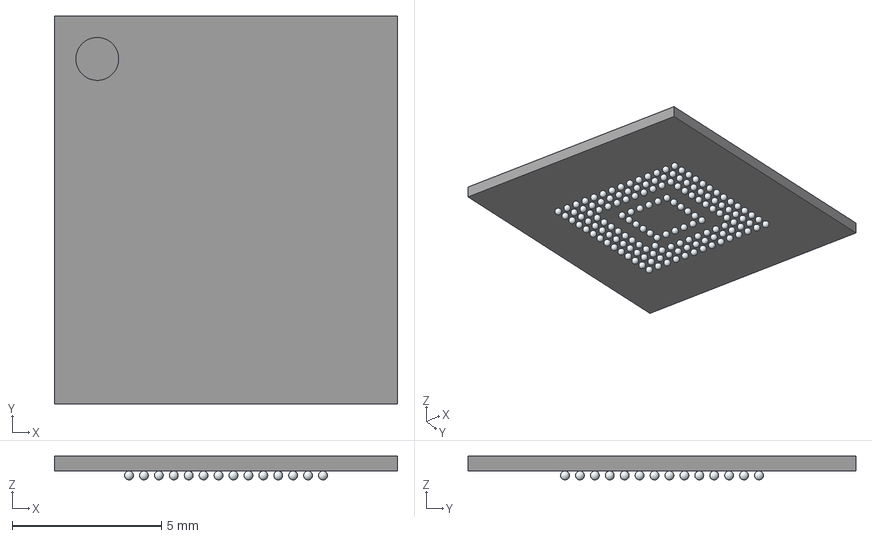
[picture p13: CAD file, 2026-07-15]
hardware/CustomLibs/Downloaded/eMMC/MX52LM04A11XSI/MX52LM04A11XSI.stp
11.5 x 13.0 x 0.8 mm
A1
A2
A3
A4
A5
A6
A7
A8
A9
A10
A11
A12
A13
A14
B1
B2
B3
B4
B5
B6
B7
B8
B9
B10
B11
B12
B13
B14
C1
C2
C3
C4
C5
C6
C7
C8
C9
C10
C11
C12
C13
C14
D1
D2
D3
D4
D12
D13
D14
E1
E2
E3
E5
E6
E7
E8
E9
E10
E12
E13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

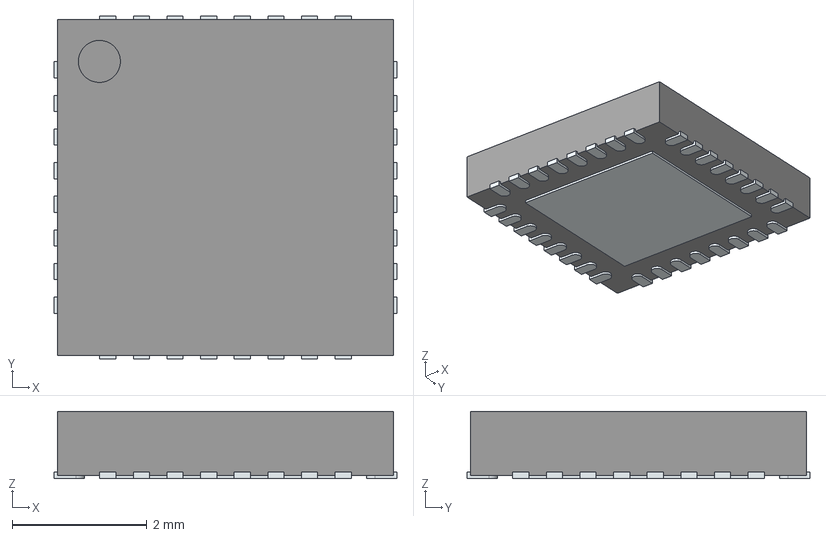
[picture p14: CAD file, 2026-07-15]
hardware/CustomLibs/Downloaded/ETHERNET/LAN8740AI-EN-TR/LAN8740AI-EN-TR.stp
5.10 x 5.10 x 1.00 mm
ThermalPin
PinsArrayLR
PinsArrayTB

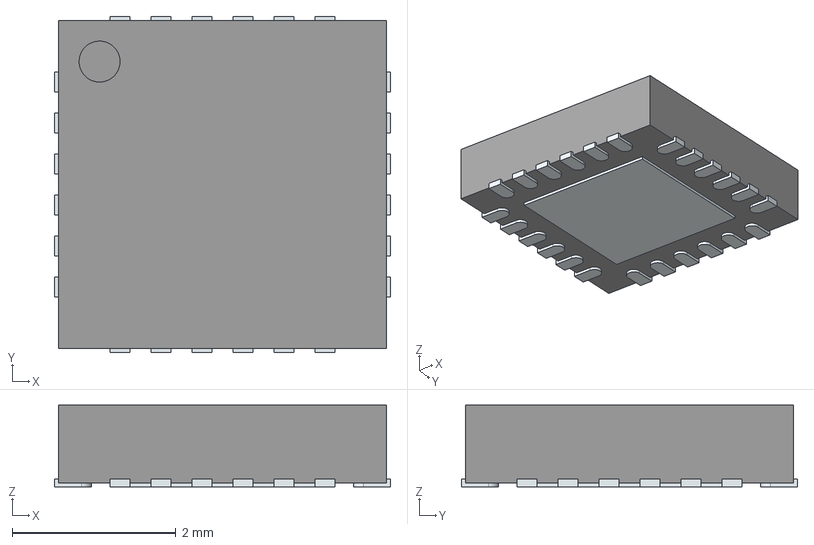
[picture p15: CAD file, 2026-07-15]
hardware/CustomLibs/Downloaded/ETHERNET/LAN8742A-CZ-TR/LAN8742A-CZ-TR.stp
4.10 x 4.10 x 1.00 mm
ThermalPin
PinsArrayLR
PinsArrayTB

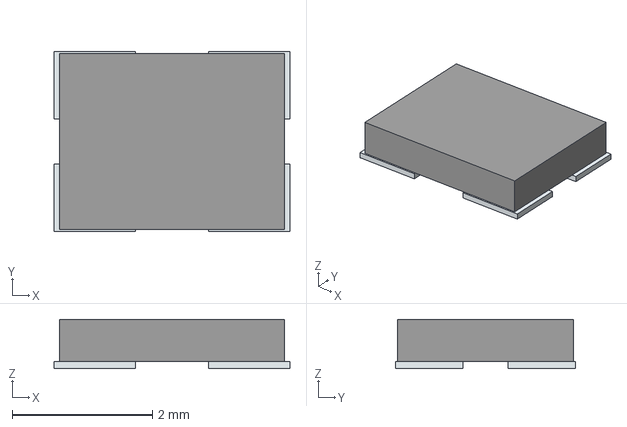
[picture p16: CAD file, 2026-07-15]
hardware/CustomLibs/Downloaded/ETHERNET/NX3225SA-25.000M-STD-CSR-6/NX3225SA-25.000M-STD-CSR-6.stp
3.36 x 2.56 x 0.7 mm
Pins

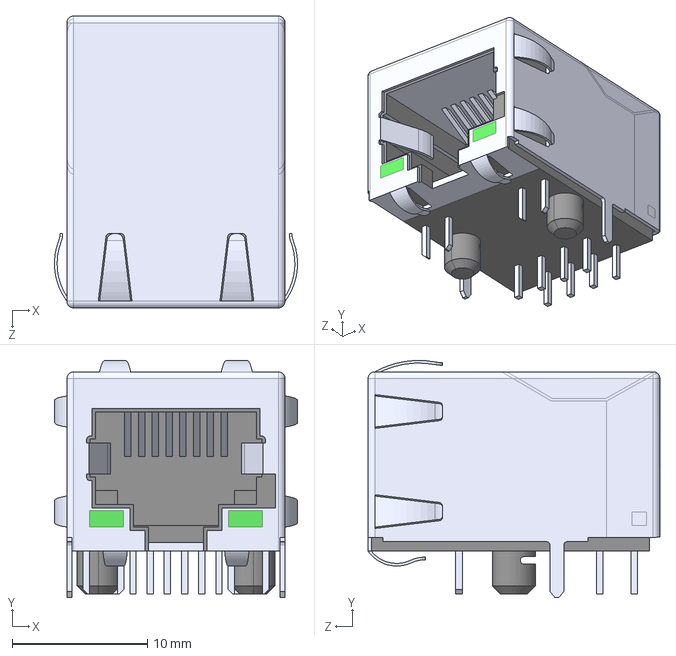
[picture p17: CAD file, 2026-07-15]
hardware/CustomLibs/Downloaded/ETHERNET/SI-60062-F/SI-60062-F.stp
18.0 x 17.5 x 21.6 mm

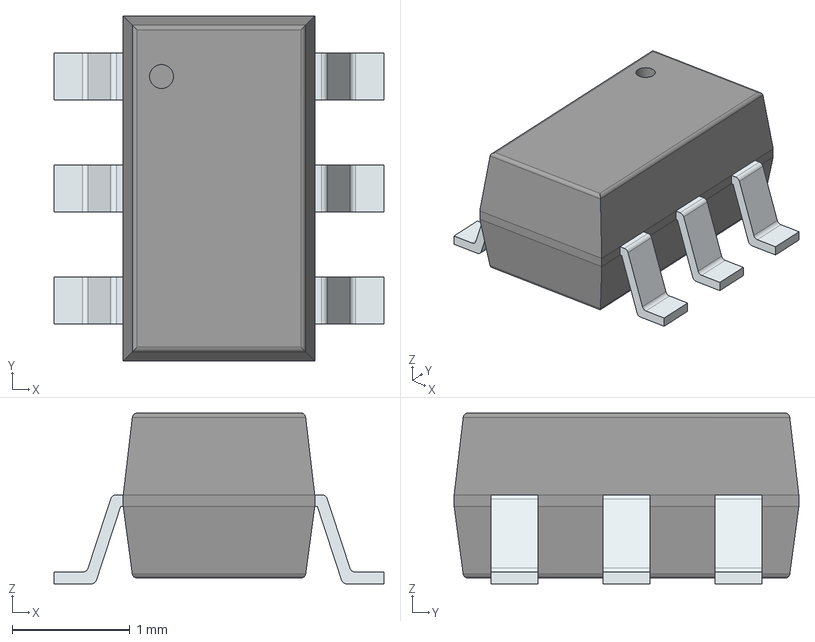
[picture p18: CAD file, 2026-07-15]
hardware/CustomLibs/Downloaded/ETHERNET/USBLC6-4SC6/USBLC6-4SC6.stp
2.80 x 2.92 x 1.45 mm
PinsArrayLR

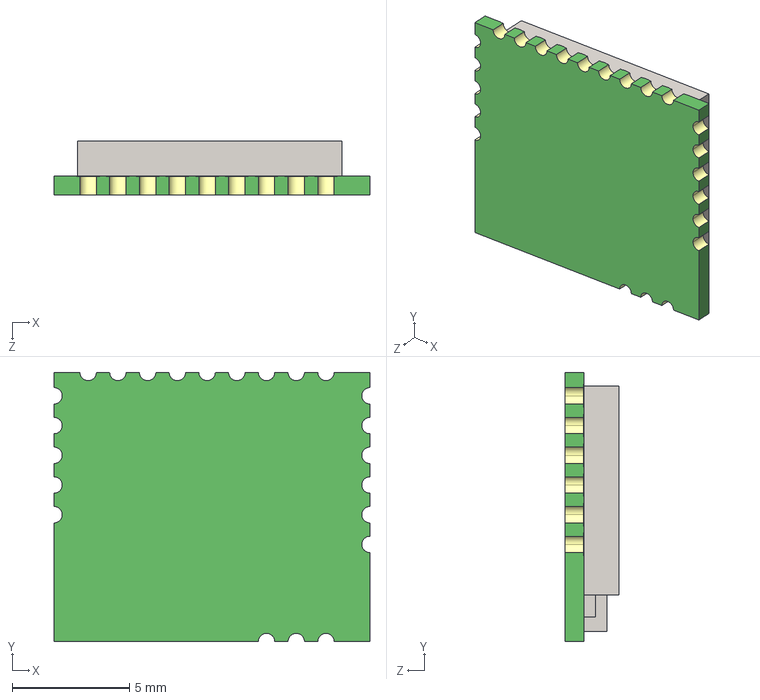
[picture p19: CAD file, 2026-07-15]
hardware/CustomLibs/Downloaded/RADIO/BLUENRG-M2SA/BLUENRG-M2SA.stp
13.5 x 11.5 x 2.30 mm

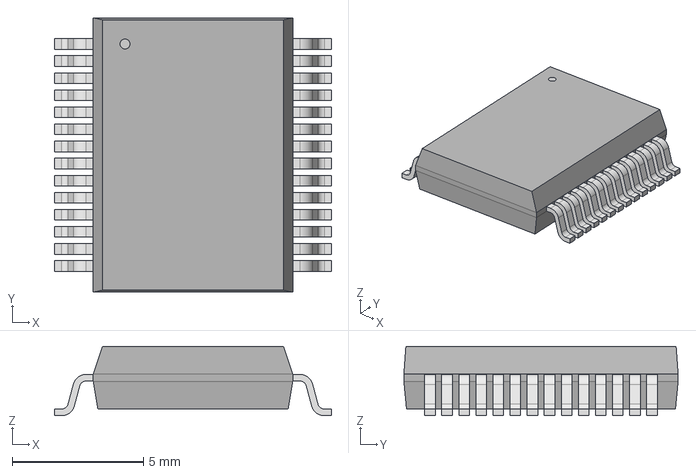
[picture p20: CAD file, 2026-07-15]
hardware/CustomLibs/Downloaded/SDCARD/ADM2565EBRNZ/ADM2565EBRNZ.step
10.5 x 10.4 x 2.64 mm

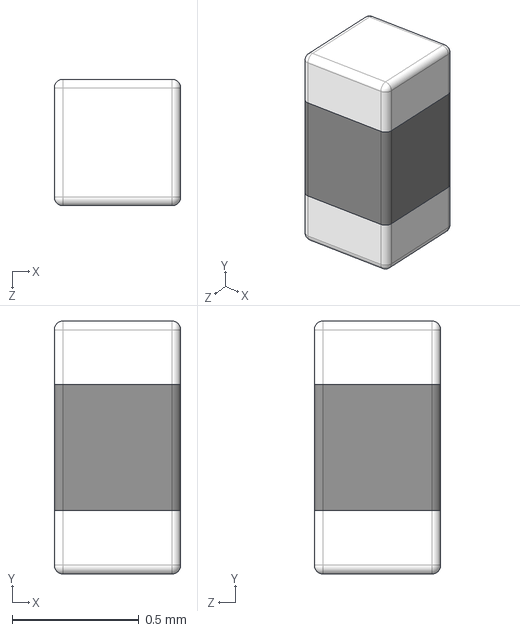
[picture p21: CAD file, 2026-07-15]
hardware/CustomLibs/Downloaded/SDCARD/BLM15HD182SN1D/BLM15HD182SN1D.stp
0.5 x 1.00 x 0.5 mm

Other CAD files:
hardware/CustomLibs/Downloaded/SDCARD/DM3ATSFPEJM540/DM3ATSFPEJM540.stp
hardware/CustomLibs/Downloaded/SDCARD/EMIF06-MSD02N16/EMIF06-MSD02N16.stp
hardware/CustomLibs/Downloaded/TestPoint/5000/5000.stp
hardware/CustomLibs/Downloaded/uC/APFA3010LSEEZGKQBKC/APFA3010LSEEZGKQBKC.stp
hardware/CustomLibs/Downloaded/ADC/B72220S0271K101/B72220S0271K101.stp
hardware/CustomLibs/Downloaded/USB/BAT30KFILM/BAT30KFILM.stp
hardware/CustomLibs/Downloaded/USB/ESDA7P60-1U1M/ESDA7P60-1U1M.stp
hardware/CustomLibs/Downloaded/USB/STEF05SGR/STEF05SGR.stp
hardware/CustomLibs/Downloaded/USB/STL6N3LLH6/STL6N3LLH6.stp
hardware/CustomLibs/Downloaded/USB/TCPP01-M12/TCPP01-M12.stp
hardware/CustomLibs/Downloaded/USB/USBLC6-2P6/USBLC6-2P6.stp
hardware/CustomLibs/Downloaded/VR/10SVPS10M/10SVPS10M.stp
hardware/CustomLibs/Downloaded/VR/LDLN025M12R/LDLN025M12R.stp
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

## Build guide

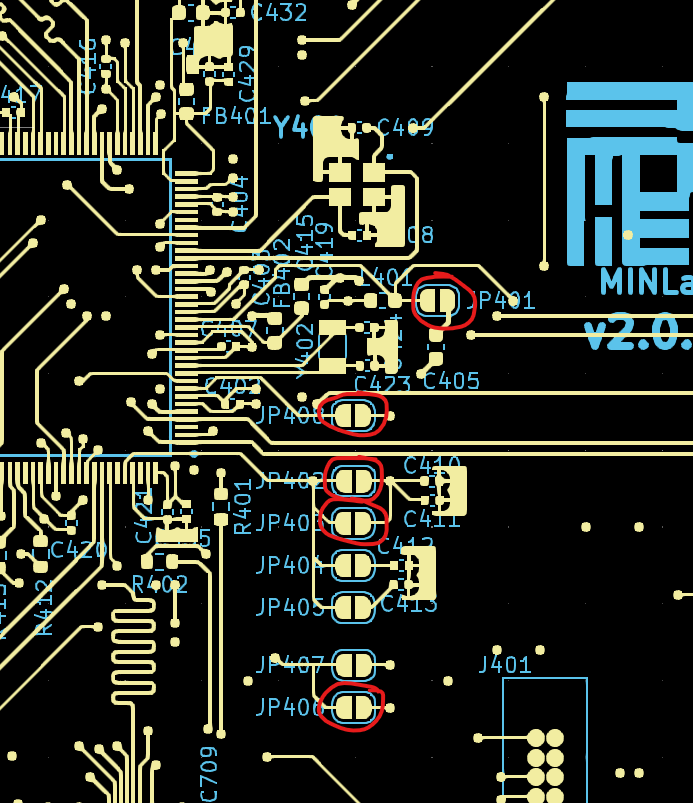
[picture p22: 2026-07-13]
hardware/Manufacturing/PCBWay/EnergyMonitoringSystem.kicad_pcb/Jump-SolderBridges.png

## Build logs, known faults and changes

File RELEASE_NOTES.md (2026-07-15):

# AEMS v1.0.0 — First public open-hardware release

First public release of the **Autonomous Energy Monitoring System (AEMS)**: an
open-source, low-cost, modular platform for high-resolution energy monitoring of
manufacturing equipment. This release contains the complete hardware design, the
dual-core embedded firmware, and the host-side software stack, accompanying the
paper *"An Open-Source, Autonomous Platform for High-Resolution Energy Monitoring
in Manufacturing."*

## What's included

**Hardware** (`hardware/`) — Complete KiCad 7 design for the AEMS v2 board:
hierarchical schematics, PCB layout, custom and third-party part libraries,
LTSpice front-end simulations, stackup/impedance design summaries, an interactive
BOM (`ibom.html`), and ready-to-fabricate PCBWay outputs (Gerbers, drill, BOM,
pick-and-place).

**Firmware** (`firmware/`) — STM32H745 dual-core firmware:
- **CM4** — deterministic acquisition (ADS131M08), DAQ state machine, on-board
  eMMC logging via FatFs, and OpenAMP remote service.
- **CM7** — Ethernet/TCP host link, FreeRTOS/LwIP, OpenAMP master, command and
  response handling, file/DAQ streaming.

**Host software** (`firmware/BoardInterfaceLibrary/`) — Python `board_interface`
library for single- and multi-board control, DAQ stream/log decoding, examples,
a Raspberry Pi daemon (`aems-boardd` / `aemsctl`), and an optional AWS IoT cloud
agent.

## Hardware highlights

- **ADS131M08** 8-channel, 24-bit, simultaneously sampling delta-sigma ADC front end
- **STM32H745** dual-core (Cortex-M7 + Cortex-M4) MCU
- Isolated power rails and impedance-controlled multilayer PCB
- MOV-based surge protection on the measurement inputs
- On-board eMMC for autonomous logging; PoE-capable Ethernet
- Current build acquires 6 channels (three voltage, three current)

## Validation

The platform was validated on a three-axis CNC machining center, where it resolves
spindle, feed-drive, rapid-traverse, and material-removal energy states and detects
feed-rate changes as small as 50 mm/min.

## Getting started

- System overview and setup: [`README.md`](README.md)
- Firmware architecture: [`firmware/README.md`](firmware/README.md) and `firmware/docs/Software/README.md`
- Host library: [`firmware/BoardInterfaceLibrary/README.md`](firmware/BoardInterfaceLibrary/README.md)
- Hardware / fabrication: [`hardware/README.md`](hardware/README.md)
- Raspberry Pi server & cloud: `firmware/BoardInterfaceLibrary/docs/`

## How to cite

If you use AEMS, please cite the paper and this archived release. See
[`CITATION.cff`](CITATION.cff).

- Paper: Selvaraj, V., Nagaraj, A., Zhang, S., Sadeghian, S., Min, S.,
  *An Open-Source, Autonomous Platform for High-Resolution Energy Monitoring in
  Manufacturing* (2026).
- Software archive: Zenodo DOI `10.5281/zenodo.XXXXXXX` *(add after archiving)*

## License

Released under a per-material split (full texts in [`LICENSES/`](LICENSES/)):

- Hardware design files — **CERN-OHL-P-2.0**
- Firmware and host software — **MIT**
- Documentation and figures — **CC-BY-4.0**

Vendor/third-party components (ST HAL/CMSIS, FreeRTOS, OpenAMP, FatFs, BlueNRG-2,
downloaded KiCad libraries) retain their own licenses.

## Known limitations

- **6-channel operation only.** The current board/firmware build and host workflows
  assume a channel mask of `0x3F` (channels 0–5). Do not request a wider mask until
  the firmware explicitly supports it.
- **Input voltage topology.** The present hardware is validated for its rated
  direct-measurement input. Higher line-to-line service voltages (e.g. 480 V L-L)
  exceed the on-board MOV continuous ratings and require an external potential
  transformer (tracked under `hardware/FutureUpdates/`).
- **Stream/control framing (temporary).** The host library uses a temporary
  heuristic to separate command `12` ACK traffic from command `13` DAQ stream
  payload on the same TCP connection. A firmware/protocol change to explicitly
  frame stream traffic is the planned long-term fix.

## Release artifacts

In addition to the source archives attached by GitHub, this release may include:

- **Fabrication package** — zipped `hardware/Manufacturing/PCBWay/` (Gerbers, drill,
  BOM, pick-and-place) plus the interactive BOM and a schematic PDF
- **Compiled firmware** — CM4 and CM7 binaries (`.elf` / `.bin` / `.hex`)
- **Python package** — built wheel/sdist of `BoardInterfaceLibrary`

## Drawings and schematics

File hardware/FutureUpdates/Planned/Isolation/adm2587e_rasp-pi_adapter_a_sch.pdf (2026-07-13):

D

6 | 5 | 4 | 3 | 2 | 1

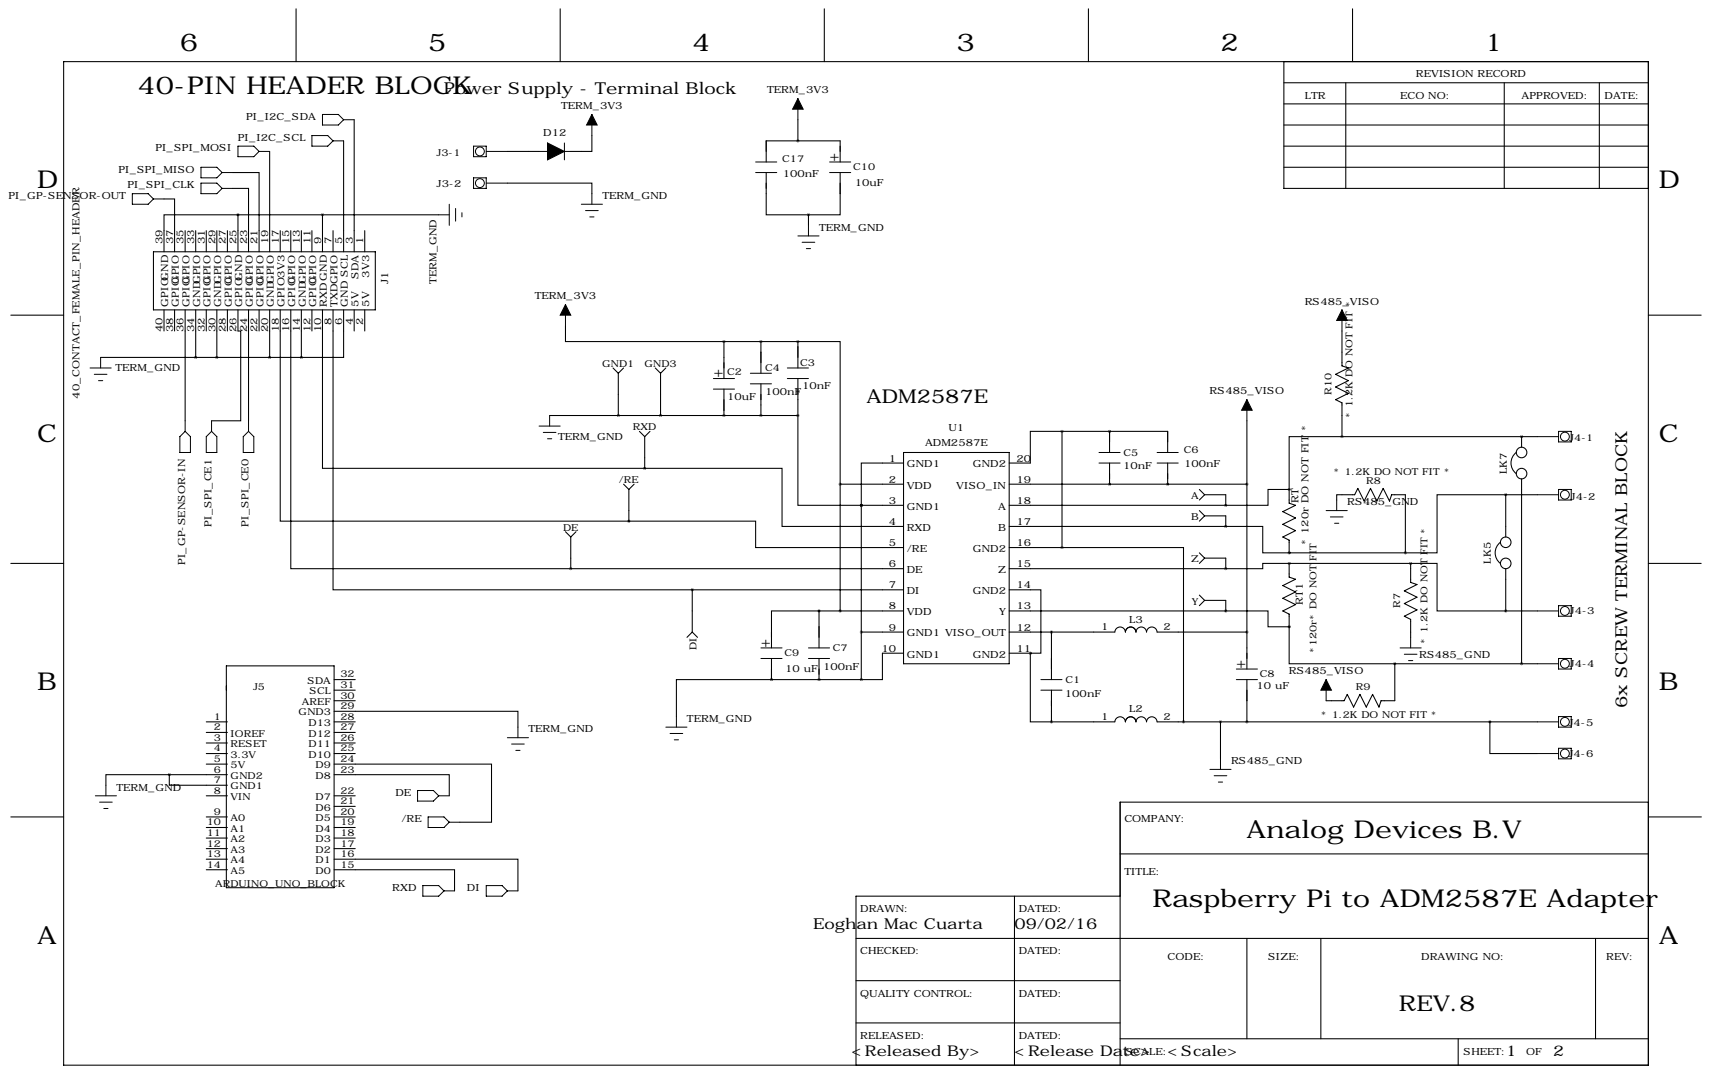
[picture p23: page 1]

40-PIN HEADER BLOCKPower Supply - Terminal Block

TERM_3V3 | REVISION RECORD

LTR | ECO NO: | APPROVED: | DATE:

39 GND 40 GPIO 38 GPIO 36 GPIO 34 GND 32 GPIO 30 GND 28 GPIO 26 GPIO 24 GPIO 22 GPIO 20 GND 18 GPIO 16 GPIO 14 GND 12 GPIO 10 RXD 8 TXD 6 GND 4 5V 2 5V

TITLE:
Raspberry Pi to ADM2587E Adapter

CHECKED: | DATED: | CODE: | SIZE: | DRAWING NO: REV.8 | REV:

QUALITY CONTROL: | DATED:

D

6 | 5 | 4 | 3 | 2 | 1

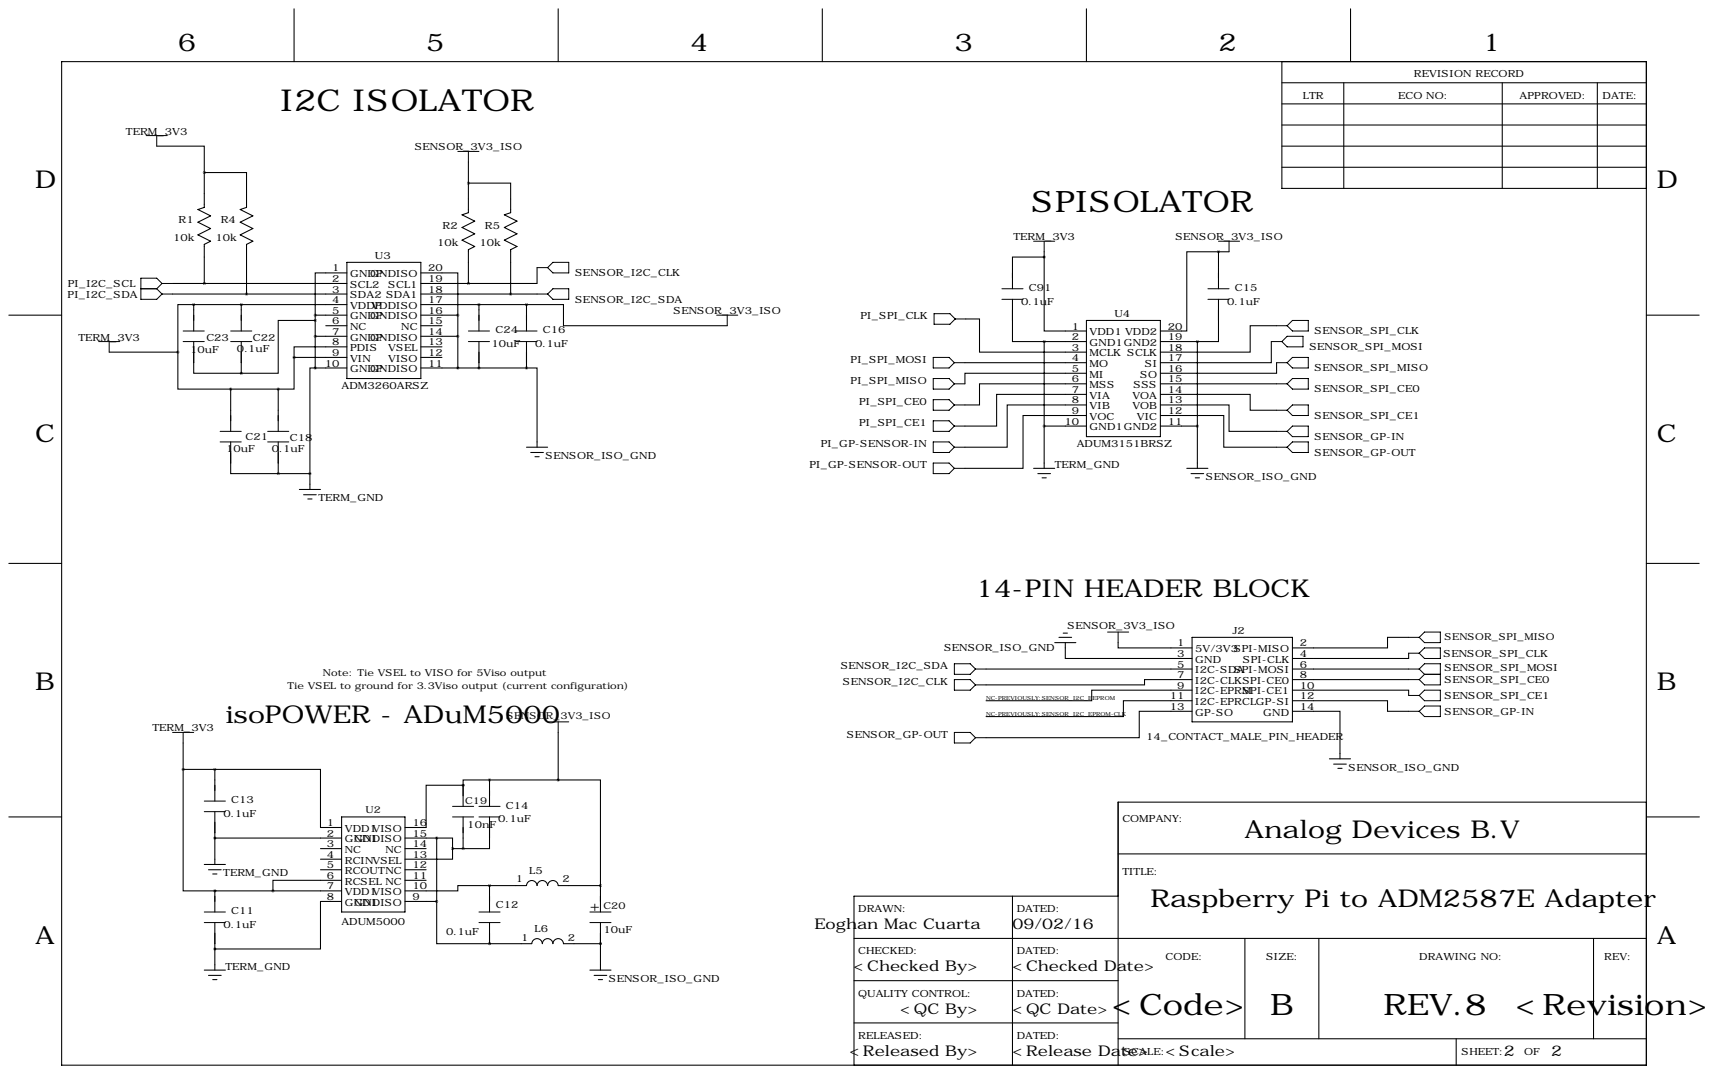
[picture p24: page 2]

TERM_3V3 R2 TERM_3V3 SENSOR_3V3_ISO | REVISION RECORD

LTR | ECO NO: | APPROVED: | DATE:

14 VOA

12 VIC

Note: Tie VSEL to VISO for 5Viso output

Tie VSEL to ground for 3.3Viso output (current configuration)
isoPOWER - ADuM5000

TITLE:
Raspberry Pi to ADM2587E Adapter

DRAWN: | DATED: 09/02/16

CHECKED: <Checked By> | DATED: <Checked Date> | CODE: | SIZE: | DRAWING NO: | REV:

QUALITY CONTROL: <QC By> | DATED: <QC Date>

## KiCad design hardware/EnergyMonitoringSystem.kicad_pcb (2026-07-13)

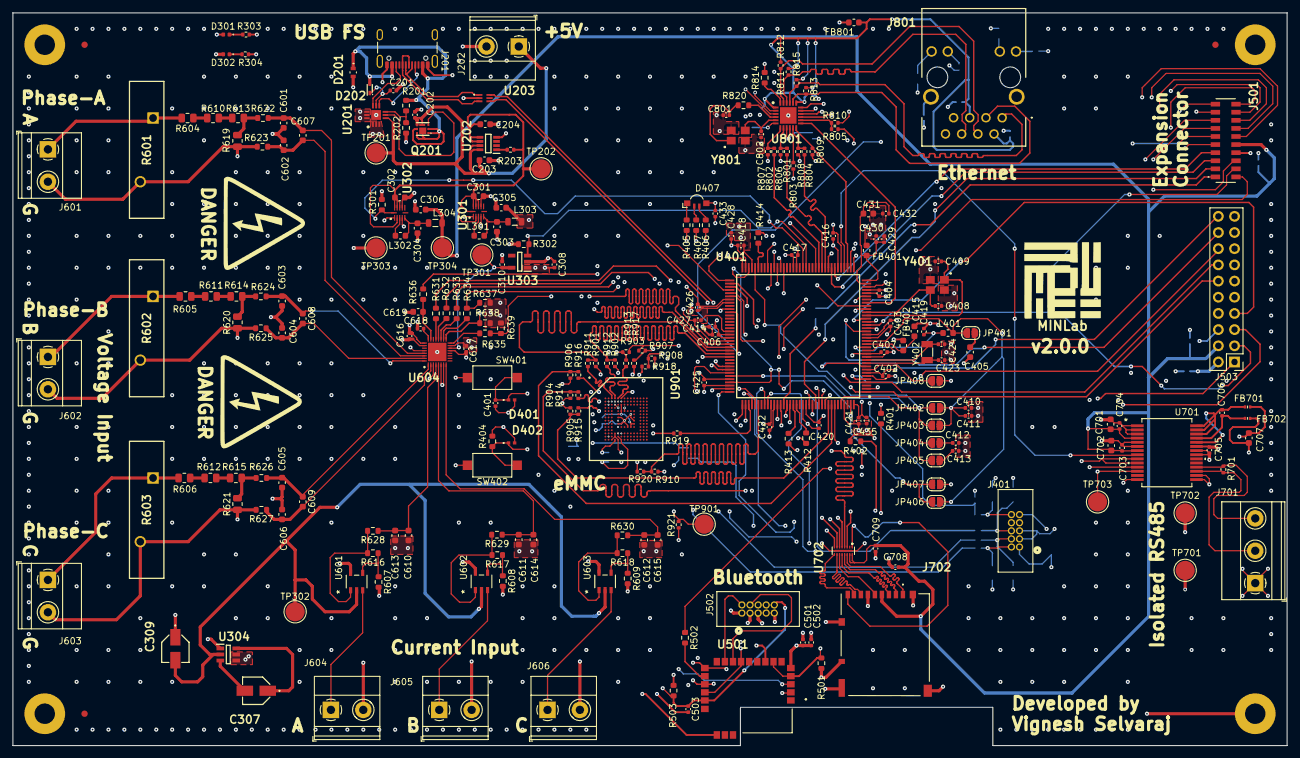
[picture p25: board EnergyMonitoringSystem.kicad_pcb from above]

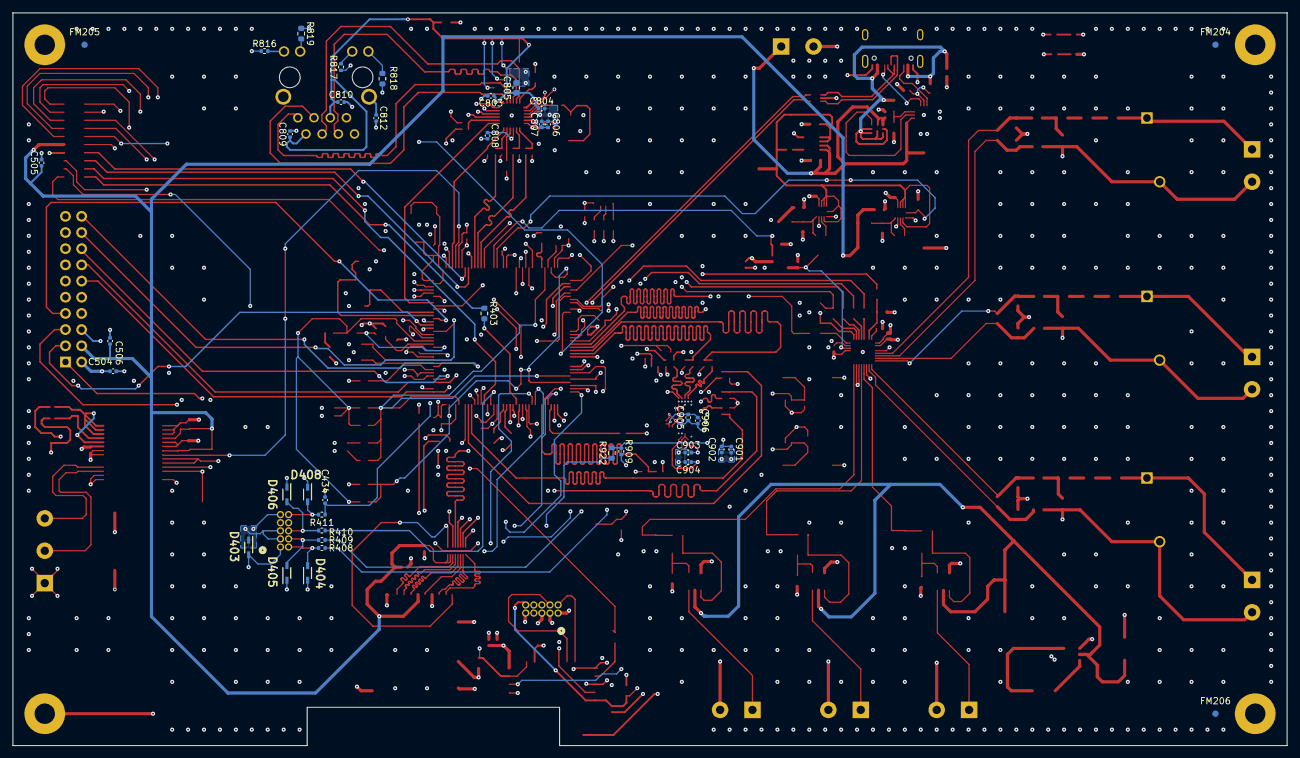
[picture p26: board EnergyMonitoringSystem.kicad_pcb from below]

Board: 8 copper layers, 200.0 x 115.0 mm, 294 parts (38 on the bottom side), 213 nets.

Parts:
C201, C202, C401, C402, C403, C404, C407, C414, C416, C417, C418, C420, C421, C422, C425, C426, C427, C430, C432, C433, C434, C502, C503, C504, C505, C506, C708, C709, C803, C804, C808, C809, C810, C901, C903, C905: 100n; C_0402_1005Metric
C203, C204, C301, C302, C405, C415, C431, C701, C702, C707, C805: 10u; C_0603_1608Metric
C303, C304, C305, C306: 47u; C_0603_1608Metric
C307, C309: 10u; 10SVPS10M
C308, C310, C406, C429, C616, C617, C807: 1u; C_0402_1005Metric
C408, C409, C423, C424, C801, C802: 5p6; C_0402_1005Metric
C410, C411: 4u7; C_0402_1005Metric
C412, C413, C428, C435, C501, C902, C904, C906: 2u2; C_0402_1005Metric
C419: 220p; C_0402_1005Metric
C601, C602, C603, C604, C605, C606, C610, C611, C612, C619: 10p; C_0603_1608Metric
C607, C608, C609, C613, C614, C615: 6800p; C_0603_1608Metric
C618: 220n; C_0402_1005Metric
C703, C704, C705, C706: 0u1; C_0402_1005Metric
C806: 470p; C_0402_1005Metric
C812: 1n; C_0402_1005Metric
D201: ESDA7P60-1U1M
D202: BAT30KFILM
D301, D302: LED; LED_0402_1005Metric
D401, D402: ESDALC6V1-1M2; ESDALC6V11M2
D403, D404, D405, D406, D408: PESD3V3L1BA,115; PESD3V3L1BA_115-SOD-323-2
D407: LED_RAGB; LED_Kingbright_APFA3010_3x1.5mm_Horizontal
FB401, FB402, FB801: FerriteBead; L_0603_1608Metric
FB701, FB702: FerriteBead; BLM15HD182SN1D
FM201, FM202, FM203, FM204, FM205, FM206: Fiducial; Fiducial_1mm_Mask2mm
H201, H202, H203, H204: MountingHole_Pad; MountingHole_3.2mm_M3_Pad
J201: USB_C_Receptacle_USB2.0_16P; USB_C_Receptacle_GCT_USB4105-xx-A_16P_TopMnt_Horizontal
J202, J601, J602, J603, J604, J605, J606: Screw_Terminal_01x02; TerminalBlock_Phoenix_MKDS-1,5-2-5.08_1x02_P5.08mm_Horizont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
J401, J502: Conn_02x05_Counter_Clockwise; 62701021621
J501: CLP-110-02-G-D; CLP-110-02-XXX-D
J503: Conn_02x08_Counter_Clockwise; PinHeader_2x10_P2.54mm_Vertical
J701: Screw_Terminal_01x03; TerminalBlock_Phoenix_MKDS-1,5-3-5.08_1x03_P5.08mm_Horizont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
J702: DM3AT-SF-PEJM5_40_; DM3ATSFPEJM540
J801: SI-60062-F; Connector-SI60062F
JP401, JP402, JP403, JP406, JP408: SolderJumper_2_Bridged; SolderJumper-2_P1.3mm_Open_RoundedPad1.0x1.5mm
JP404, JP405, JP407: SolderJumper_2_Open; SolderJumper-2_P1.3mm_Open_RoundedPad1.0x1.5mm
L301, L302, L401: 2u2; L_0603_1608Metric
L303, L304: 10u; L_0805_2012Metric
Q201: STL6N3LLH6
R201, R404, R607, R608, R609, R637: 10k; R_0603_1608Metric
R202: 2k7; R_0603_1608Metric
R203, R701: 120R; R_0402_1005Metric
R301, R302, R638, R639: 100k; R_0603_1608Metric
R303, R304: 220R; R_0402_1005Metric
R401, R402, R403, R502: 22R; R_0603_1608Metric
R405, R406, R407, R622, R623, R624, R625, R626, R627: 1k; R_0603_1608Metric
R408, R409, R410, R411, R811, R812, R813, R815: 49R9; R_0402_1005Metric
R412, R413, R414, R631, R632, R633, R634, R635, R636: 33R; R_0603_1608Metric
R501: 47k; R_0603_1608Metric
R503: 4k7; R_0603_1608Metric
R601, R602, R603: R_Variable; B72220S0271K101
R604, R605, R606, R610, R611, R612, R613, R614, R615: 330k; R_0805_2012Metric
R616, R617, R618: 15k; R_0603_1608Metric
R619, R620, R621: 750R; R_0805_2012Metric
R628, R629, R630: 2k; R_0603_1608Metric
R801, R802, R804, R805: 33R; R_0402_1005Metric
R803, R806, R807, R808, R810, R816, R817, R910: 10k; R_0402_1005Metric
R809: 1k5; R_0402_1005Metric
R814: 12k1; R_0603_1608Metric
R818, R819: 270R; R_0603_1608Metric
R820, R922: 0R; R_0603_1608Metric
R901, R902, R903, R904, R905, R906, R907, R908, R909, R921: 47k; R_0402_1005Metric
R911, R912, R913, R914, R915, R916, R917, R918, R919, R920: 22R; R_0402_1005Metric
SW401, SW402: SW_Push; SW_SPST_CK_RS282G05A3
TP201, TP202, TP301, TP302, TP303, TP304, TP701, TP702, TP703, TP901: TestPoint; TestPoint_Pad_D3.0mm
U201: TCPP01-M12; TCPP01-M12-QFN-12L
U202: STEF05SGR; STEF05SGR-TSOT23-8L
U203: USBLC6-2P6; USBLC62P6-SOT666-6
U301, U302: ST1PS02CQTR
U303: LDLN025M12R; LDLN025M12R-SOT-23-5
U304: LM2664M6_NOPB; LM2664M6_NOPB-SOT-23-6
U401: STM32H745ZGT6; STM32H745ZGT6_LQFP144
U501: BLUENRG-M2SA
U601, U602, U603: TSV911ILT; TSV911ILT_SOT23-5
U604: ADS131M08IRSNR; ADS131M08IRSNR-QFN40
U701: ADM2565EBRNZ; ADM2565EBRNZ-SOIC-28
U702: EMIF06-MSD02N16
U801: LAN8742A-CZ-TR; LAN8742A-CZ-TR_QFN50
U901: MX52LM04A11XSI; MX52LM04A11XSI_BGA153
Y401, Y801: Crystal_GND24; NX3225SA25000MSTDCSR6
Y402: 32.768KHz; Crystal_SMD_3215-2Pin_3.2x1.5mm

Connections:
+1V2: C310.1, TP301.1, U303.5 (OUT), U604.14 (REFIN)
+5V: C204.1, C301.1, C302.1, R203.1, TP202.1, U202.5 (SOURCE_1), U202.6 (SOURCE_2), U301.2 (VIN), U301.9 (D0), U301.10 (D1), U301.11 (D2), U301.12 (EN), U302.2 (VIN), U302.9 (D0), U302.10 (D1), U302.11 (D2)
+5V_EXT: C202.1, C203.1, J202.1, Q201.4 (S_1), Q201.8 (S_2), TP201.1, U201.4 (SOURCE), U202.7 (VCC_1), U202.8 (VCC_2)
+DCDC_1: C305.1, C308.1, C402.1, C403.1, C404.1, C406.1, C407.1, C414.1, C416.1, C417.1, C418.1, C420.1, C421.1, C422.1, C425.1, C426.1, C427.1, C428.2, C433.1, C435.2, C501.1, C502.1, C504.1, C616.2, C617.2, C808.1, C903.1, C904.1, C905.1, C906.1, D301.2 (A), D403.2 (K2), D407.2 (A), FB401.1, FB402.1, FB801.1, J401.1, J502.1, J503.2, JP407.1 (A), JP408.1 (A), L303.2, R503.2, R637.2, R638.2, R639.2, R806.2, R807.2, R808.2, R809.2, R810.2, R901.2, R902.2, R903.2, R904.2, R905.2, R906.2, R907.2, R908.2, R909.2, R910.2, SW402.2, TP303.1, U303.1 (IN), U304.4 (SD), U304.5 (V+), U401.7 (VDD_1), U401.13 (VDD_2), U401.19 (VDD_3), U401.32 (VDD_4), U401.42 (VDD_5), U401.56 (VDD_6), U401.71 (VDD_7), U401.79 (VDD_8), U401.90 (VDD50USB), U401.91 (VDD33USB), U401.92 (VDD_9), U401.106 (VDD_10), U401.119 (VDD_11), U401.129 (VDD_12), U401.144 (VDD_13), U501.5 (VIN), U601.5 (VCC+), U602.5 (VCC+), U603.5 (VCC+), U604.15 (AVDD), U604.26 (DVDD), U801.9 (VDDIO), U901.C6 (VCCQ_1), U901.E6 (VCC_1), U901.F5 (VCC_2), U901.J10 (VCC_3), U901.K9 (VCC_4), U901.M4 (VCCQ_2), U901.N4 (VCCQ_3), U901.P3 (VCCQ_4), U901.P5 (VCCQ_5)
+DCDC_2: C306.1, C505.1, C506.1, C701.1, C702.2, C703.1, C704.2, C708.1, C709.1, D302.2 (A), J501.10, J503.4, J702.4 (VDD), L304.2, TP304.1, U701.4 (VCC), U701.7 (VIO), U702.15 (VCC), U702.16 (RDATA_VCC)
+VBUSc: D201.1 (K), D202.2 (A), J201.A4 (VBUS), J201.A9 (VBUS), J201.B4 (VBUS), J201.B9 (VBUS), Q201.1 (D_1), Q201.2 (D_2), Q201.5 (D_3), Q201.6 (D_4), Q201.7 (D_5), R201.1
+VDD_SDC: C410.2, C411.2, JP401.2 (B), JP402.1 (A), JP403.1 (A), JP406.1 (A), L401.1, U401.17 (VFBSMPS)
+VREF: C429.1, C430.1, C431.1, C432.1, FB401.2, U401.35 (VREF+), U401.36 (VDDA)
+V_ISO: C705.1, C707.2, FB702.2, TP701.1, U701.23 (VISOIN)
-DCDC_1: C309.2, TP302.1, U304.2 (OUT), U601.2 (VCC-), U602.2 (VCC-), U603.2 (VCC-)
/ADC/CLKIN_ADS_T: C619.1, R636.2, U604.23 (XTAL1_CLKIN)
/ADC/CT_PhaseA_Amp_OUT: R616.2, R628.2, U601.1 (OUT)
/ADC/CT_PhaseA_IN: J604.1, U601.3 (IN+)
/ADC/CT_PhaseB_Amp_OUT: R617.2, R629.2, U602.1 (OUT)
/ADC/CT_PhaseB_IN: J605.1, U602.3 (IN+)
/ADC/CT_PhaseC_Amp_OUT: R618.2, R630.2, U603.1 (OUT)
/ADC/CT_PhaseC_IN: J606.1, U603.3 (IN+)
/ADC/DIN_ADS_T: R631.2, U604.21 (DIN)
/ADC/DOUT_ADS_T: R632.2, U604.20 (DOUT)
/ADC/DRDY_ADS_T: R634.2, U604.18 (DRDY_N)
/ADC/I_Phase_A_P: C610.1, C613.1, R628.1, U604.4 (AIN3P)
/ADC/I_Phase_B_P: C611.1, C614.1, R629.1, U604.5 (AIN4P)
/ADC/I_Phase_C_P: C612.1, C615.1, R630.1, U604.8 (AIN5P)
/ADC/SCK_ADS_T: R633.2, U604.19 (SCLK)
/ADC/SYNC_RESET_ADS_T: R635.2, U604.16 (SYNC_RESET_N)
/ADC/V_Phase_A_N: C602.2, C607.2, R623.1, U604.30 (AIN0N)
/ADC/V_Phase_A_P: C601.1, C607.1, R622.1, U604.29 (AIN0P)
/ADC/V_Phase_B_N: C604.2, C608.2, R625.1, U604.31 (AIN1N)
/ADC/V_Phase_B_P: C603.1, C608.1, R624.1, U604.32 (AIN1P)
/ADC/V_Phase_C_N: C606.2, C609.2, R627.1, U604.2 (AIN2N)
/ADC/V_Phase_C_P: C605.1, C609.1, R626.1, U604.1 (AIN2P)
/BLE/BLE_SWDCLK: J502.4, U501.12 (DIO9)
/BLE/BLE_SWDIO: J502.2, U501.13 (DIO10)
/BLE/SPI5_MISO_R: R502.2, U501.16 (DIO2)
/ETHERNET/ETH_DCDC2_FR: C803.1, C804.1, C805.1, C809.1, C810.1, FB801.2, J801.2 (TCT), J801.5 (RCT), R811.2, R812.2, R813.2, R815.2, U801.1 (VDD2A), U801.19 (VDD1A)
/ETHERNET/RMII_CRS_DV_R: R804.2, R808.1, U801.11 (CRS_DV/MODE2)
/ETHERNET/RMII_PHYAD0: R803.2, U801.10 (RXER/PHYAD0)
/ETHERNET/RMII_REF_CLK_R: R805.2, R810.1, U801.14 (NINT/REFCLKO)
/ETHERNET/RMII_RXD0_R: R801.2, R806.1, U801.8 (RXD0/MODE0)
/ETHERNET/RMII_RXD1_R: R802.2, R807.1, U801.7 (RXD1/MODE1)
/ETHERNET/RMII_RXN: J801.6 (RD-), R811.1, U801.22 (RXN)
/ETHERNET/RMII_RXP: J801.4 (RD+), R812.1, U801.23 (RXP)
/ETHERNET/RMII_TXN: J801.3 (TD-), R813.1, U801.20 (TXN)
/ETHERNET/RMII_TXP: J801.1 (TD+), R815.1, U801.21 (TXP)
/ETHERNET/RMII_XTAL1: C802.2, U801.5 (XTAL1/CLKIN), Y801.3
/ETHERNET/RMII_XTAL2: R820.2, U801.4 (XTAL2)
/SDCARD/SD_CLK: J702.5 (CLK), U702.11 (CLK_EX)
/SDCARD/SD_CMD: J702.3 (CMD), U702.12 (CMD_EX)
/SDCARD/SD_DAT0: J702.7 (DAT0), U702.10 (DAT0_EX)
/SDCARD/SD_DAT1: J702.8 (DAT1), U702.9 (DAT1_EX)
/SDCARD/SD_DAT2: J702.1 (DAT2), U702.14 (DAT2_EX)
/SDCARD/SD_DAT3: J702.2 (CD/DAT3), U702.13 (DAT3_EX)
/USB/FSE_I_LIM: R203.2, U202.1 (I_LIM)
/USB/PD_GATE: Q201.3 (G), U201.5 (GATE)
/USB/PD_IN_GD: C201.1, D202.1 (K), U201.8 (IN_GD)
/USB/PD_VBUS_CTRL: R201.2, R202.1, U201.6 (VBUS_CTRL)
/USB/USB_CC1c: J201.A5 (CC1), U201.7 (CC1C)
/USB/USB_CC2c: J201.B5 (CC2), U201.9 (CC2C)
/USB/USB_OTG_D+: J201.A6 (D+), J201.B6 (D+), U203.3 (I/O2_1)
/USB/USB_OTG_D-: J201.A7 (D-), J201.B7 (D-), U203.1 (I/O1_1)
/VR/CHRG_CAP+: C307.1, U304.6 (CAP+)
/VR/CHRG_CAP-: C307.2, U304.3 (CAP-)
/VR/DC1_SW: L301.1, U301.3 (SW)
/VR/DC1_VOUT: C303.1, L301.2, L303.1, U301.5 (VOUT)
/VR/DC2_SW: L302.1, U302.3 (SW)
/VR/DC2_VOUT: C304.1, L302.2, L304.1, U302.5 (VOUT)
/eMMC/SDMMC1_CK_R: R919.2, U901.M6 (CLK)
/eMMC/SDMMC1_CMD_R: R920.2, U901.M5 (CMD)
/eMMC/SDMMC1_D0_R: R911.2, U901.A3 (DAT0)
/eMMC/SDMMC1_D1_R: R912.2, U901.A4 (DAT1)
/eMMC/SDMMC1_D2_R: R913.2, U901.A5 (DAT2)
/eMMC/SDMMC1_D3_R: R914.2, U901.B2 (DAT3)
/eMMC/SDMMC1_D4_R: R915.2, U901.B3 (DAT4)
/eMMC/SDMMC1_D5_R: R916.2, U901.B4 (DAT5)
/eMMC/SDMMC1_D6_R: R917.2, U901.B5 (DAT6)
/eMMC/SDMMC1_D7_R: R918.2, U901.B6 (DAT7)
/eMMC/SDMMC1_eMMC_RSTn_JP: R909.1, R922.2, U901.K5 (RST_N)
/eMMC/VDDI: C901.1, C902.1, U901.C2 (VDDI)
/uCMain/BOOT0: D402.1 (K), R404.2, SW402.1, U401.135 (BOOT0)
/uCMain/DEBUG_JTCK-SWCLK: R409.1, U401.107 (PA14)
/uCMain/DEBUG_JTCK-SWCLK-H: D405.2 (K2), J401.4, R409.2
/uCMain/DEBUG_JTDO-SWO: R410.1, U401.130 (PB3)
/uCMain/DEBUG_JTDO-SWO-H: D406.2 (K2), J401.6, R410.2
/uCMain/DEBUG_JTMS-SWDIO: R408.1, U401.102 (PA13)
/uCMain/DEBUG_JTMS-SWDIO-H: D404.2 (K2), J401.2, R408.2
/uCMain/NRST: C401.1, C434.1, D401.1 (K), R411.1, SW401.1, U401.27 (NRST)
/uCMain/NRST-H: D408.2 (K2), J401.10, R411.2
/uCMain/OSC32_IN: C423.1, U401.10 (PC14-OSC32_IN), Y402.1
/uCMain/OSC32_OUT: C424.1, U401.11 (PC15-OSC32_OUT), Y402.2
/uCMain/OSC_IN: C409.2, U401.25 (PH0-OSC_IN), Y401.1
/uCMain/OSC_OUT: C408.2, U401.26 (PH1-OSC_OUT), Y401.3
/uCMain/SPI5_MOSI_R: R402.1, U401.23 (PF9)
/uCMain/SPI5_SCK_R: R401.1, U401.21 (PF7)
/uCMain/TIM1_CH1: R405.2, U401.59 (PE9)
/uCMain/TIM1_CH2: R406.2, U401.61 (PE11)
/uCMain/TIM1_CH3: R407.2, U401.63 (PE13)
ADC1_INP9: J501.11, U401.49 (PB0)
ADC3_INP1: J501.9, U401.31 (PC3_C)
ADS_CS: J503.18, R638.1, U401.20 (PF6), U604.17 (CS_N)
ADS_DIN_uC_DOUT: J503.16, R631.1, U401.5 (PE6)
ADS_DOUT_uC_DIN: J503.14, R632.1, U401.4 (PE5)
ADS_DRDY: J503.20, R634.1, R637.1, U401.9 (PC13)
ADS_SPI_SCK: J503.12, R633.1, U401.1 (PE2)
ADS_STM32_CLKOUT: R636.1, U401.97 (PA8)
ADS_SYNC_RESET: R635.1, R639.1, U401.28 (PC0)
BLE_INT: R501.2, U401.2 (PE3), U501.4 (DIO5), U501.7 (DIO7/BOOT)
BLE_RST: C503.1, J502.10, R503.1, U401.76 (PD8), U501.19 (RESETN)
BLE_TEST8: U401.78 (PD10), U501.2 (ADC1)
BLE_TEST9: U401.77 (PD9), U501.3 (DIO4)
DCDC_2_EN: R301.1, U302.12 (EN), U401.53 (PF14)
ETH_NRST: U401.45 (PA6), U801.15 (NRST)
FDCAN2_RX: J501.16, U401.72 (PB12)
FDCAN2_TX: J501.18, U401.73 (PB13)
GND: C201.2, C202.2, C203.2, C204.2, C301.2, C302.2, C303.2, C304.2, C305.2, C306.2, C308.2, C309.1, C310.2, C401.2, C402.2, C403.2, C404.2, C405.1, C406.2, C407.2, C408.1, C409.1, C410.1, C411.1, C412.1, C413.1, C414.2, C415.1, C416.2, C417.2, C418.2, C419.1, C420.2, C421.2, C422.2, C423.2, C424.2, C425.2, C426.2, C427.2, C428.1, C429.2, C430.2, C431.2, C432.2, C433.2, C434.2, C435.1, C501.2, C502.2, C503.2, C504.2, C505.2, C506.2, C601.2, C602.1, C603.2, C604.1, C605.2, C606.1, C610.2, C611.2, C612.2, C613.2, C614.2, C615.2, C616.1, C617.1, C618.2, C619.2, C701.2, C702.1, C703.2, C704.1, C708.2, C709.2, C801.1, C802.1, C803.2, C804.2, C805.2, C806.2, C807.2, C808.2, C809.2, C810.2, C812.2, C901.2, C902.2, C903.2, C904.2, C905.2, C906.2, D201.2 (A), D401.2 (A), D402.2 (A), D403.1 (K1), D404.1 (K1), D405.1 (K1), D406.1 (K1), D408.1 (K1), H201.1, H202.1, H203.1, H204.1, J201.A1 (GND), J201.A12 (GND), J201.B1 (GND), J201.B12 (GND), J201.S1 (SHIELD), J202.2, J401.3, J401.5, J401.9, J501.8, J502.3, J502.5, J502.9, J503.6, J601.2, J602.2, J603.2, J604.2, J605.2, J606.2, J702.6 (VSS), J702.MP1, J702.MP2, J702.MP3, J702.MP4, J702.MP5, J801.8, R202.2, R301.2, R302.1, R303.2, R304.2, R404.1, R501.1, R601.2, R602.2, R603.2, R607.2, R608.2, R609.2, R619.1, R620.1, R621.1, R623.2, R625.2, R627.2, R803.1, R814.2, R816.1, R817.1, R818.1, R819.1, R921.1, SW401.2, U201.1 (CC2), U201.2 (GND), U201.3 (CC1), U201.10 (DB/), U201.11 (FLT/), U201.12 (VCC), U201.13 (EP), U202.4 (GND), U203.2 (GND), U301.1 (AUX), U301.4 (GND), U301.8 (CL), U302.1 (AUX), U302.4 (GND), U302.8 (CL), U303.2 (GND), U304.1 (GND), U401.6 (VSS_1), U401.12 (VSS_2), U401.14 (VSSSMPS), U401.18 (VSS_3), U401.33 (VSS_4), U401.34 (VSSA), U401.41 (VSS_5), U401.55 (VSS_6), U401.69 (VSS_7), U401.80 (VSS_8), U401.89 (VSS_9), U401.104 (VSS_10), U401.118 (VSS_11), U401.128 (VSS_12), U401.141 (VSS_13), U501.8 (GND_1), U501.21 (GND_2), U604.3 (AIN3N), U604.6 (AIN4N), U604.7 (AIN5N), U604.13 (AGND), U604.25 (DGND), U604.28 (AGND), U604.33 (EP), U701.1 (GND1), U701.2 (GND1), U701.3 (GND1), U701.5 (GND1), U701.6 (GND1), U701.14 (GND1), U702.17 (EP_(GND)), U801.25 (EP), U901.A6 (VSS_1), U901.C4 (VSSQ_1), U901.E7 (VSS_2), U901.G5 (VSS_3), U901.H10 (VSS_4), U901.J5 (VSS_5), U901.K8 (VSS_6), U901.N2 (VSSQ_2), U901.N5 (VSSQ_3), U901.P4 (VSSQ_4), U901.P6 (VSSQ_5), Y401.2, Y401.4, Y801.2, Y801.4
GND2: C705.2, C707.1, FB701.2, J701.1, TP702.1, U701.15 (GND2), U701.16 (GND2), U701.21 (GND2), U701.22 (GND2)
GPIO_IN_1: J501.19, U401.62 (PE12)
GPIO_IN_2: J501.17, U401.64 (PE14)
GPIO_OUT_1: J501.20, U401.60 (PE10)
I2C1_SCL: J501.15, U401.133 (PB6)
I2C1_SDA: J501.13, U401.134 (PB7)
LDO_EN: R302.2, U303.3 (EN), U401.52 (PF11)
unnamed: C801.2, R820.1, Y801.1
unnamed: C812.1, J801.9, J801.10
unnamed: D301.1 (K), R303.1
unnamed: D302.1 (K), R304.1
unnamed: D407.4 (BK), R407.1
unnamed: D407.3 (GK), R406.1
unnamed: D407.1 (RK), R405.1
unnamed: J601.1, R601.1, R604.2
unnamed: J602.1, R602.1, R605.2
unnamed: J603.1, R603.1, R606.2
unnamed: J701.2, R701.1, U701.17 (A)
unnamed: J701.3, R701.2, U701.18 (B)
unnamed: J801.13 (GRN_+), R817.2, U801.2 (LED2/NINT/NPME/NINTSEL)
unnamed: J801.14 (GRN_-), R818.2
unnamed: J801.11 (YEL_+), R816.2, U801.3 (LED1/NINT/NPME/REGOFF)
unnamed: J801.12 (YEL_-), R819.2
unnamed: C405.2, JP401.1 (A)
unnamed: JP402.2 (B), JP403.2 (B), JP404.2 (B), JP405.2 (B), U401.68 (VCAP_1), U401.103 (VCAP_2), U401.140 (VCAP_3)
unnamed: C412.2, JP404.1 (A)
unnamed: C413.2, JP405.1 (A)
unnamed: JP406.2 (B), JP407.2 (B), U401.70 (VDDLDO_1), U401.105 (VDDLDO_2), U401.143 (VDDLDO_3)
unnamed: JP408.2 (B), U401.8 (VBAT)
unnamed: R604.1, R610.2
unnamed: R605.1, R611.2
unnamed: R606.1, R612.2
unnamed: R610.1, R613.2
unnamed: R611.1, R614.2
unnamed: R612.1, R615.2
unnamed: R613.1, R619.2, R622.2
unnamed: R614.1, R620.2, R624.2
unnamed: R615.1, R621.2, R626.2
unnamed: R414.2, U401.67 (PB11)
unnamed: R403.2, U401.122 (PG9)
unnamed: R413.1, U401.125 (PG12)
unnamed: R412.1, U401.126 (PG13)
unnamed: C415.2, FB402.2, U401.16 (VDDSMPS)
unnamed: C419.2, L401.2, U401.15 (VLXSMPS)
unnamed: R607.1, R616.1, U601.4 (IN-)
unnamed: R608.1, R617.1, U602.4 (IN-)
unnamed: R609.1, R618.1, U603.4 (IN-)
unnamed: C618.1, U604.24 (CAP)
unnamed: C706.2, FB702.1, U701.25 (VISOOUT)
unnamed: C706.1, FB701.1, U701.24 (GNDISO), U701.26 (GNDISO), U701.27 (VSEL), U701.28 (GNDISO)
unnamed: R814.1, U801.24 (RBIAS)
unnamed: C806.1, C807.1, U801.6 (VDDCR)
unnamed: R921.2, TP901.1, U901.H5 (DATA_STROBE)
RMII_CRS_DV: R804.1, U401.46 (PA7)
RMII_MDC: U401.29 (PC1), U801.13 (MDC)
RMII_MDIO: R809.1, U401.39 (PA2), U801.12 (MDIO)
RMII_REF_CLK: R805.1, U401.38 (PA1)
RMII_RXD0: R801.1, U401.47 (PC4)
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

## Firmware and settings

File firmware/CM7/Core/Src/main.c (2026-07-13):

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
/* Includes ------------------------------------------------------------------*/
#include "main.h"
#include "cmsis_os.h"
#include "dma.h"
#include "lwip.h"
#include "openamp.h"
#include "spi.h"
#include "tim.h"
#include "gpio.h"

/* USER CODE BEGIN Includes */
#include "led.h"
/* USER CODE END Includes */

/* USER CODE BEGIN PD */
#ifndef HSEM_ID_0
#define HSEM_ID_0 (0U)
#endif
/* USER CODE END PD */


/* USER CODE BEGIN PV */
LED rgbLed;
uint16_t phyid1, phyid2, bmsr;
/* USER CODE END PV */

void SystemClock_Config(void);
static void MPU_Config(void);
void MX_FREERTOS_Init(void);
/**
  * @brief  The application entry point.
  * @retval int
  */
int main(void)
{

/* USER CODE BEGIN Boot_Mode_Sequence_0 */
#if defined(DUAL_CORE_BOOT_SYNC_SEQUENCE)
  int32_t timeout;
#endif /* DUAL_CORE_BOOT_SYNC_SEQUENCE */
/* USER CODE END Boot_Mode_Sequence_0 */

  /* MPU Configuration--------------------------------------------------------*/
  MPU_Config();

  /* Enable the CPU Cache */

  /* Enable I-Cache---------------------------------------------------------*/
  SCB_EnableICache();

  /* Enable D-Cache---------------------------------------------------------*/
  SCB_EnableDCache();

/* USER CODE BEGIN Boot_Mode_Sequence_1 */
#if defined(DUAL_CORE_BOOT_SYNC_SEQUENCE)
  /* Wait until CPU2 boots and enters in stop mode or timeout*/
  timeout = 0xFFFF;
  while((__HAL_RCC_GET_FLAG(RCC_FLAG_D2CKRDY) != RESET) && (timeout-- > 0));
  if ( timeout < 0 )
  {
  Error_Handler();
  }
#endif /* DUAL_CORE_BOOT_SYNC_SEQUENCE */
/* USER CODE END Boot_Mode_Sequence_1 */
  /* MCU Configuration--------------------------------------------------------*/

  /* Reset of all peripherals, Initializes the Flash interface and the Systick. */
  HAL_Init();

  /* Configure the system clock */
  SystemClock_Config();
/* USER CODE BEGIN Boot_Mode_Sequence_2 */
#if defined(DUAL_CORE_BOOT_SYNC_SEQUENCE)
/* When system initialization is finished, Cortex-M7 will release Cortex-M4 by means of
HSEM notification */
/*HW semaphore Clock enable*/
__HAL_RCC_HSEM_CLK_ENABLE();
/*Take HSEM */
HAL_HSEM_FastTake(HSEM_ID_0);
/*Release HSEM in order to notify the CPU2(CM4)*/
HAL_HSEM_Release(HSEM_ID_0,0);
/* wait until CPU2 wakes up from stop mode */
timeout = 0xFFFF;
while((__HAL_RCC_GET_FLAG(RCC_FLAG_D2CKRDY) == RESET) && (timeout-- > 0));
if ( timeout < 0 )
{
Error_Handler();
}
#endif /* DUAL_CORE_BOOT_SYNC_SEQUENCE */
/* USER CODE END Boot_Mode_Sequence_2 */

  /* Initialize all configured peripherals */
  MX_GPIO_Init();
  MX_DMA_Init();
  MX_TIM1_Init();
  /* USER CODE BEGIN 2 */
  HAL_TIM_Base_Start_IT(&htim1);
  LED_Init(&rgbLed, &htim1, TIM_CHANNEL_1, TIM_CHANNEL_2, TIM_CHANNEL_3);
  LED_ON(&rgbLed);
  LED_SetStatus(LED_STATUS_BOOTING);
  LED_SetBrightness(&rgbLed, 35, 35, 35);

  /* USER CODE END 2 */

  /* Call init function for freertos objects (in cmsis_os2.c) */
  MX_FREERTOS_Init();

  /* Start scheduler */
  osKernelStart();

  /* We should never get here as control is now taken by the scheduler */

  /* Infinite loop */
  /* USER CODE BEGIN WHILE */
  while (1)
  {
    /* USER CODE END WHILE */

    /* USER CODE BEGIN 3 */
  }
  /* USER CODE END 3 */
}

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
 /* MPU Configuration */

void MPU_Config(void)
{
  MPU_Region_InitTypeDef MPU_InitStruct = {0};

  /* Disables the MPU */
  HAL_MPU_Disable();

  /** Initializes and configures the Region and the memory to be protected
  */
  MPU_InitStruct.Enable = MPU_REGION_ENABLE;
  MPU_InitStruct.Number = MPU_REGION_NUMBER0;
  MPU_InitStruct.BaseAddress = 0x0;
  MPU_InitStruct.Size = MPU_REGION_SIZE_4GB;
  MPU_InitStruct.SubRegionDisable = 0x87;
  MPU_InitStruct.TypeExtField = MPU_TEX_LEVEL0;
  MPU_InitStruct.AccessPermission = MPU_REGION_NO_ACCESS;
  MPU_InitStruct.DisableExec = MPU_INSTRUCTION_ACCESS_DISABLE;
  MPU_InitStruct.IsShareable = MPU_ACCESS_SHAREABLE;
  MPU_InitStruct.IsCacheable = MPU_ACCESS_NOT_CACHEABLE;
  MPU_InitStruct.IsBufferable = MPU_ACCESS_NOT_BUFFERABLE;

  HAL_MPU_ConfigRegion(&MPU_InitStruct);

  /** Initializes and configures the Region and the memory to be protected
  */
  MPU_InitStruct.Number = MPU_REGION_NUMBER1;
  MPU_InitStruct.BaseAddress = 0x30020000;
  MPU_InitStruct.Size = MPU_REGION_SIZE_128KB;
  MPU_InitStruct.SubRegionDisable = 0x0;
  MPU_InitStruct.TypeExtField = MPU_TEX_LEVEL1;
  MPU_InitStruct.AccessPermission = MPU_REGION_FULL_ACCESS;
  MPU_InitStruct.IsShareable = MPU_ACCESS_NOT_SHAREABLE;

  HAL_MPU_ConfigRegion(&MPU_InitStruct);

  /** Initializes and configures the Region and the memory to be protected
  */
  MPU_InitStruct.Number = MPU_REGION_NUMBER2;
  MPU_InitStruct.BaseAddress = 0x30040000;
  MPU_InitStruct.Size = MPU_REGION_SIZE_512B;
  MPU_InitStruct.TypeExtField = MPU_TEX_LEVEL0;
  MPU_InitStruct.IsShareable = MPU_ACCESS_SHAREABLE;
  MPU_InitStruct.IsBufferable = MPU_ACCESS_BUFFERABLE;

  HAL_MPU_ConfigRegion(&MPU_InitStruct);

  /** Initializes and configures the Region and the memory to be protected
  */
  MPU_InitStruct.Number = MPU_REGION_NUMBER3;
  MPU_InitStruct.BaseAddress = 0x38000000;
  MPU_InitStruct.Size = MPU_REGION_SIZE_64KB;
  MPU_InitStruct.DisableExec = MPU_INSTRUCTION_ACCESS_ENABLE;
  MPU_InitStruct.IsBufferable = MPU_ACCESS_NOT_BUFFERABLE;

  HAL_MPU_ConfigRegion(&MPU_InitStruct);

  /** Initializes and configures the Region and the memory to be protected
  */
  MPU_InitStruct.Number = MPU_REGION_NUMBER4;
  MPU_InitStruct.BaseAddress = 0x30000000;
  MPU_InitStruct.Size = MPU_REGION_SIZE_32KB;
  MPU_InitStruct.TypeExtField = MPU_TEX_LEVEL1;
  MPU_InitStruct.DisableExec = MPU_INSTRUCTION_ACCESS_DISABLE;

  HAL_MPU_ConfigRegion(&MPU_InitStruct);
  /* Enables the MPU */
  HAL_MPU_Enable(MPU_PRIVILEGED_DEFAULT);

}

/**
  * @brief  Period elapsed callback in non blocking mode
  * @note   This function is called  when TIM6 interrupt took place, inside
  * HAL_TIM_IRQHandler(). It makes a direct call to HAL_IncTick() to increment
  * a global variable "uwTick" used as application time base.
  * @param  htim : TIM handle
  * @retval None
  */
void HAL_TIM_PeriodElapsedCallback(TIM_HandleTypeDef *htim)
{
  if (htim->Instance == TIM6)
  {
    HAL_IncTick();
  }
}

/**
  * @brief  This function is executed in case of error occurrence.
  * @retval None
  */
void Error_Handler(void)
{
  /* USER CODE BEGIN Error_Handler_Debug */
  /* User can add his own implementation to report the HAL error return state */
  LED_SetStatus(LED_STATUS_FATAL);
  LED_SetBrightness(&rgbLed, 100, 0, 0);
  __disable_irq();
  while (1)
  {
  }
  /* USER CODE END Error_Handler_Debug */
}
#ifdef USE_FULL_ASSERT
/**
  * @brief  Reports the name of the source file and the source line number
  *         where the assert_param error has occurred.
  * @param  file: pointer to the source file name
  * @param  line: assert_param error line source number
  * @retval None
  */
void assert_failed(uint8_t *file, uint32_t line)
{
  /* USER CODE BEGIN 6 */
  /* User can add his own implementation to report the file name and line number,
     ex: printf("Wrong parameters value: file %s on line %d\r\n", file, line) */
  /* USER CODE END 6 */
}
#endif /* USE_FULL_ASSERT */

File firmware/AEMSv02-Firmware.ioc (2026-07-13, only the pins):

Mcu.UserName=STM32H745ZITx
PA1.GPIO_Label=RMII_REF_CLK
PA1.Signal=ETH_REF_CLK
PA2.GPIO_Label=RMII_MDIO
PA2.Signal=ETH_MDIO
PA6.GPIO_Label=ETH_NRST
PA6.Signal=GPIO_Output
PA7.GPIO_Label=RMII_CRS_DV
PA7.Signal=ETH_CRS_DV
PA8.GPIO_Label=ADS_STM32_CLKOUT
PA8.Signal=RCC_MCO_1
PB11.GPIO_Label=RMII_TX_EN
PB11.Signal=ETH_TX_EN
PB8.Signal=SDMMC1_D4
PB9.Signal=SDMMC1_D5
PC0.GPIO_Label=ADS_SYNC_RESET
PC0.Signal=GPIO_Output
PC1.GPIO_Label=RMII_MDC
PC1.Signal=ETH_MDC
PC10.Signal=SDMMC1_D2
PC11.Signal=SDMMC1_D3
PC12.Signal=SDMMC1_CK
PC13.GPIO_Label=ADS_DRDY
PC13.Signal=GPXTI13
PC4.GPIO_Label=RMII_RXD0
PC4.Signal=ETH_RXD0
PC5.GPIO_Label=RMII_RXD1
PC5.Signal=ETH_RXD1
PC6.Signal=SDMMC1_D6
PC7.Signal=SDMMC1_D7
PC8.Signal=SDMMC1_D0
PC9.Signal=SDMMC1_D1
PD0.Signal=UART4_RX
PD2.Signal=SDMMC1_CMD
PD8.GPIO_Label=BLE_RST
PD8.Signal=GPIO_Output
PE0.GPIO_Label=eMMC_RSTn
PE0.Signal=GPIO_Output
PE11.Signal=S_TIM1_CH2
PE13.Signal=S_TIM1_CH3
PE2.GPIO_Label=ADS_SPI_SCK
PE2.Signal=SPI4_SCK
PE3.GPIO_Label=BLE_INT
PE3.Signal=GPXTI3
PE5.GPIO_Label=ADS_DOUT_uC_DIN
PE5.Signal=SPI4_MISO
PE6.GPIO_Label=ADS_DIN_uC_DOUT
PE6.Signal=SPI4_MOSI
PE9.Signal=S_TIM1_CH1
PF10.GPIO_Label=SPI5_CS
PF10.Signal=GPIO_Output
PF11.GPIO_Label=LDO_EN
PF11.Signal=GPIO_Output
PF14.GPIO_Label=DCDC_2_EN
PF14.Signal=GPIO_Output
PF6.GPIO_Label=ADS_CS
PF6.Signal=GPIO_Output
PF7.Signal=SPI5_SCK
PF8.Signal=SPI5_MISO
PF9.Signal=SPI5_MOSI
PG12.GPIO_Label=RMII_TXD1
PG12.Signal=ETH_TXD1
PG13.GPIO_Label=RMII_TXD0
PG13.Signal=ETH_TXD0
PG9.Signal=SPI1_MISO

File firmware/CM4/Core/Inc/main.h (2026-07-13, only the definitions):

#define ADS_SPI_SCK_Pin GPIO_PIN_2
#define ADS_SPI_SCK_GPIO_Port GPIOE
#define ADS_DOUT_uC_DIN_Pin GPIO_PIN_5
#define ADS_DOUT_uC_DIN_GPIO_Port GPIOE
#define ADS_DIN_uC_DOUT_Pin GPIO_PIN_6
#define ADS_DIN_uC_DOUT_GPIO_Port GPIOE
#define ADS_DRDY_Pin GPIO_PIN_13
#define ADS_DRDY_GPIO_Port GPIOC
#define ADS_CS_Pin GPIO_PIN_6
#define ADS_CS_GPIO_Port GPIOF
#define ADS_SYNC_RESET_Pin GPIO_PIN_0
#define ADS_SYNC_RESET_GPIO_Port GPIOC
#define LDO_EN_Pin GPIO_PIN_11
#define LDO_EN_GPIO_Port GPIOF
#define DCDC_2_EN_Pin GPIO_PIN_14
#define DCDC_2_EN_GPIO_Port GPIOF
#define ADS_STM32_CLKOUT_Pin GPIO_PIN_8
#define ADS_STM32_CLKOUT_GPIO_Port GPIOA
#define eMMC_RSTn_Pin GPIO_PIN_0
#define eMMC_RSTn_GPIO_Port GPIOE

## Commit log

2026-01-24 basic config - testing board
2026-01-25 configured LED, ADS, ETH - very basic for now
2026-02-01 fatfs shared device config - not working
    [AEMSv02-Firmware.ioc, main.c, main.h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]
2026-03-30 minor update to ioc
    Fixed default task size to 128
    [AEMSv02-Firmware.ioc, main.c]
2026-04-02 fixed by increasing FreeRTOS size
    [AEMSv02-Firmware.ioc, main.c]
2026-04-05 cm4 can open and mount emmc
2026-04-06 fixing to get before openAMP executing
    [main.c, openamp_fs.c]
2026-04-11 brought OpenAMP back alive
    Stuck in a problem?
    1. Remove OpenAMP using .ioc file and build
    2. Add OpenAMP using the .ioc file and build
    3. It should bring back the shortcuts and linked file
    [AEMSv02-Firmware.ioc, main.c, main.h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]
2026-04-11 Fixed the sdmmc not being included for now
    Just remove and re add the SDMMC1 stuff
    [AEMSv02-Firmware.ioc, main.c, sdmmc.c]
2026-04-15 working toward making ADC work - start
    Start of the interface with the ADC
2026-04-15 The ADC is behaving as expected.
2026-04-15 streaming process being tested.
    [stream_data.csv]
2026-04-15 increasing block size to reduce streaming drops
    [stream_data.csv]
2026-04-15 restarting stream is fixed
    [stream_data.csv]
2026-04-16 adc bug on status read fixed
    [main.c, main.h]
2026-04-17 be able to select sampling rate
    [stream_data.csv]
2026-04-18 DMA enabled with noemmc, no loss
2026-04-18 working to write to emmc
    Not checked if the data written is valid yet
    1. SPI is DMA now
    2. eMMC write works, but interrupts are blocked during write
    2. eMMC sampling rate is not high enough
2026-04-18 working emmc and stream
    Data validity needs to be checked
    1. Sampling rate for eMMC is 1742.7 and stream is 1782 for a required 2000Hz which is OSR 2048.For OSR 2048, we need the sampling rate to be 1953.125
    [stream_data.csv]
2026-04-23 ability to calibrate pipedin
    [stream_data.csv]
2026-04-23 offset calibration appears to be working well
    [stream_data.csv]
2026-05-03 bug fixed - making filesystem error at higher clk
    1. Make filesystem at lower clock and then increase clock
    2. Updated docs
    3. Added more diagnostics to command 99 and added Python parsing
    [AEMSv02-Firmware.ioc, main.c, main.h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]
2026-05-03 fixed multi-board connect issue
    Sometimes the board connects and sometimes it doesn't added reset to the LAN8742 when not connected
2026-05-03 make led useful
2026-05-03 multi board stream tested
    1. csv and bin works
    2. Duration can be set
2026-05-04 added raspberry Pi daemon, cli -- working
2026-07-15 Add .gitattributes to normalize line endings (LF) for KiCad, firmware, and fabrication files
2026-07-15 Normalize line endings per .gitattributes
    [10SVPS10M.stp, 5000.stp, 62701021621.stp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]

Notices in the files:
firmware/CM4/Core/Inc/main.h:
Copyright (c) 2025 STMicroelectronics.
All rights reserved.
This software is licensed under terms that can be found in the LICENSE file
